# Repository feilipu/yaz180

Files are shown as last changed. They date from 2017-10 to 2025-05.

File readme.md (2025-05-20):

# YAZ180

There needed to be <strong>Yet Another Z180</strong> computer created.<br>
And so, here it is.

<div>
<table style="border: 2px solid #cccccc;">
<tbody>
<tr>
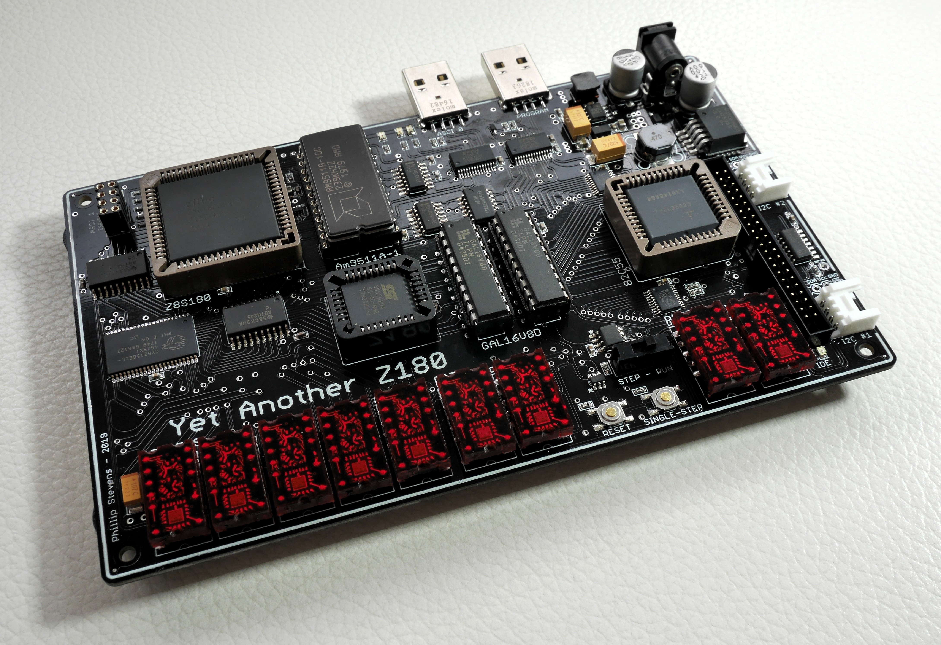
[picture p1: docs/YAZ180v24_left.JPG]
<td style="border: 1px solid #cccccc; padding: 6px;"></td>
</tr>
<tr>
<th style="border: 1px solid #cccccc; padding: 6px;"><centre>YAZ180 Version 2.4 2019 Left<center></th>
</tr>
<tr>
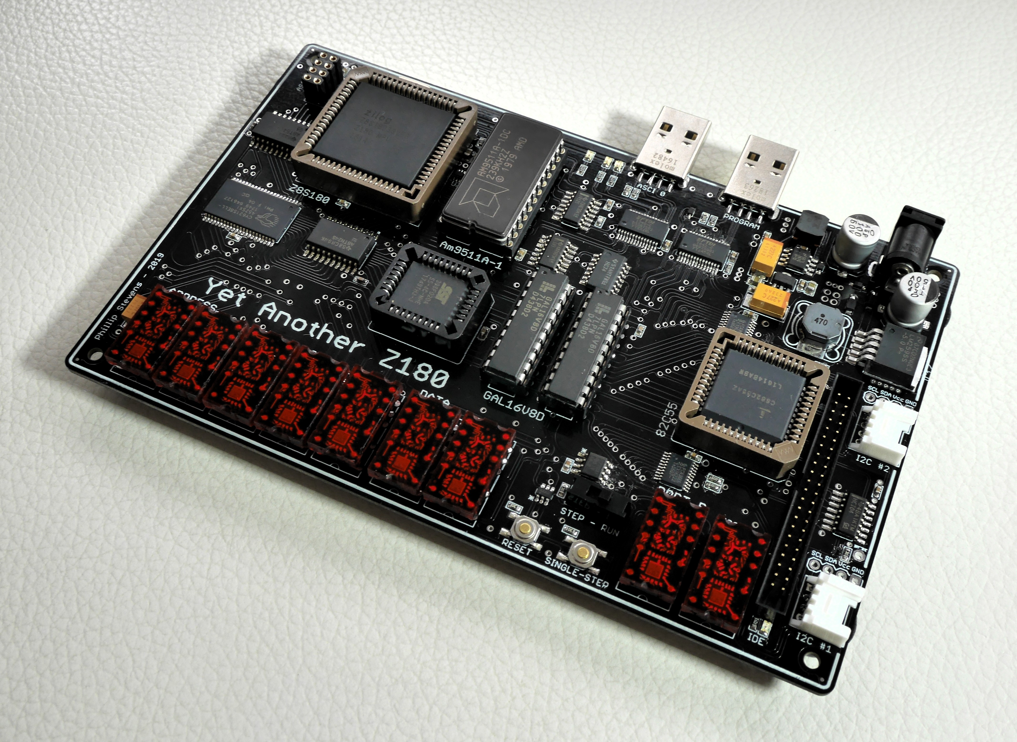
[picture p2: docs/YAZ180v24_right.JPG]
<td style="border: 1px solid #cccccc; padding: 6px;"></td>
</tr>
<tr>
<th style="border: 1px solid #cccccc; padding: 6px;"><centre>YAZ180 Version 2.4 2019 Right<center></th>
</tr>
<tr>
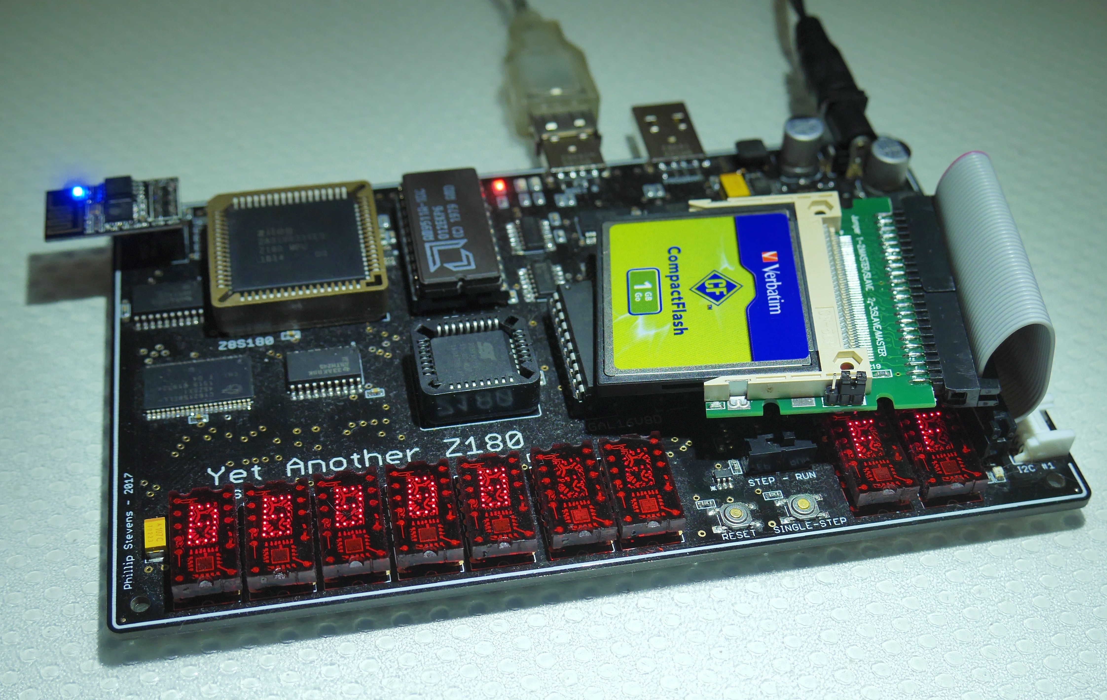
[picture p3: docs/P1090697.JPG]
<td style="border: 1px solid #cccccc; padding: 6px;"></td>
</tr>
<tr>
<th style="border: 1px solid #cccccc; padding: 6px;"><centre>YAZ180 Version 2.1 2017 Live with YABIOS and CP/M<center></th>
</tr>
</tbody>
</table>
</div>

The [YAZ180](https://feilipu.me/?s=yaz180) is a modern single board computer, built on the tradition rich Z180 CPU and the AMD Am9511A-1 APU.

It is my attempt to create a perfect mix of "ancient" and  modern computing technology. Specifically, it is an attempt to marry CPU/APU technology from 40 years ago, with modern I2C, USB, and WiFi capabilities, and make an powerful 8-bit computer that can either be embedded into an application, or operate as a stand-alone computer (with some accessories).

The YAZ180 is supported by the z88dk and it is designed to work with both traditional CP/M v2.2 applications and modern z88dk C compiled programs.

The YAZ180 is fully open source. All documentation and design is available from this repository. I have made the raw PCBs available on [Tindie](https://www.tindie.com/products/feilipu/yaz180-pcb-modern-single-board-z180-computer/), for anyone who wishes to replicate this build.

## Concept

The Z180 CPU is based on the Z80 CPU, but it includes a number of integrated peripherals including a basic Memory Management Unit (MMU), two serial interfaces (ASCI0 & ASCI1), two DMA controllers (DMAC0 & DMAC1), and two Programmable Reload Timers (PRT0 & PRT1).

The fastest readily available Flash memory is 55ns. This is matched by the fastest RAM in 8 x 1MByte packaging at 45ns. Using these two timings the fastest clock that can be therefore be supported is approximately 20MHz. Using this as a guide, and knowing that the Z180 ASCI interfaces are happiest running at a magic frequency, I have therefore selected 18.432MHz as the crystal oscillator frequency for the YAZ180.

The Z180 can operate internally at 2x the crystal oscillator frequency, which means that the YAZ180 is configured to run with PHI at 36.864MHz with 1 wait memory wait state in normal situations. This is slightly outside the Z180 specification (33MHz), but this frequency is reported to work without issues by a number of SBC builds.

The AMD Am9511A (1977) was the first hardware arithmetic Floating Point Unit (FPU) developed. It is essentially a "scientific calculator" on a chip, and is capable of both 16 bit and 32 bit fixed and 32 bit floating point processing, across all the standard and trancendental functions. Even though this device is 40 years old, it is still [comparable in performance](https://feilipu.me/2017/02/22/characterising-am9511a-1-apu/) of mathematical calculations to its Z180 host.

In addition to the internal Z180 interfaces, I have added a 82C55 Programmable Peripheral Interface (PPI) Controller (1974). This device provides 3x 8 bit parallel ports, and enables the YAZ180 to support 16bit IDE hard drives, as well as providing a mechanism to add parallel data interfacing to future expansion boards.

As the IDE interface requires control signals that are active low, several of the PPI Port C lines are passed through inverters. Importantly, those Port C lines that can accept input in PPI Mode 1 or Mode 2 are not inverted, and are therefore available as inputs from off-board applications. The IDE physical interface cable also provides a tidy board extension format, to allow extension or accessory devices to be attached to the YAZ180.

A single step circuitry has been implemented, which is enabled by a switch, and triggered by writing to an I/O port address. This enables the YAZ180 to run normally, until it becomes interesting to enable a breakpoint.

To interface with modern sensors and devices, two separate I2C interface PCA9665 devices have been provided. This enables one I2C device to be running at 800kHz in Fast-mode Plus (or even Plaid at 1MHz) driving a LCD controller for a screen (for example FTDI EVE), and have the other I2C interface connected over longer distances to sensors or keyboard running at 100kHz in Standard mode. The PCA9665 has deep 68 byte hardware buffers, and can operate in buffered or streaming mode, enabling complete I2C sentences to be transmitted or received without CPU interaction. A complete GLX graphics command can be sent with one CPU interrupt transaction, for example.

<div>
<table style="border: 2px solid #cccccc;">
<tbody>
<tr>
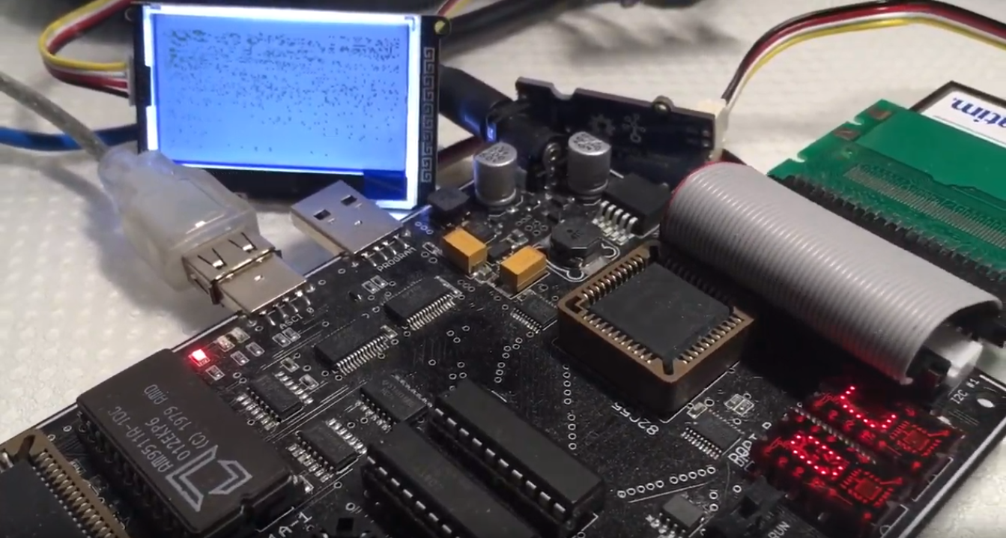
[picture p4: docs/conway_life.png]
<td style="border: 1px solid #cccccc; padding: 6px;"></td>
</tr>
<tr>
<th style="border: 1px solid #cccccc; padding: 6px;"><centre>YAZ180 I2C#2 Conway's Life & I2C#1 Temperature / Humidity Sensing - CLICK FOR VIDEO<center></th>
</tr>
</tbody>
</table>
</div>

To interface with TCP/IP networks, using WiFi, an ESP8266 pin-out for the ESP-01S is provided, connected to ASCI1. This enables the YAZ180 to operate as an Internet server (with attached IDE hard drive), and / or to be controlled using Secure Shell from anywhere.

A USB parallel interface is provided to enable "tool-less" programming of the YAZ180. A perl script is provided to upload Intel HEX code and program it into the system Flash memory. To enable this feature hardware is provided to reconfigure the memory map to allow boot from USB.

## PCB

The YAZ180 PCB is 160mm x 100mm in size, with 4 layers.<br>
This is the maximum size supported by the Eagle "Hobby Licence", which was used to create the PCB.

- Layer Top - all active devices (RED) - 2oz copper
- Layer 2 - GND layer (flood fill) - 0.5oz copper
- Layer 15 - VCC layer (flood fill) - 0.5oz copper
- Layer Bottom - signal traces (BLUE) - 2oz copper

- PCB Dimension - 160mm*100mm
- Material - FR-4 TG130
- Surface Finish - ENIG
- Min Solder Mask Dam - 0.4mm
- PCB Color - Black

<div>
<table style="border: 2px solid #cccccc;">
<tbody>
<tr>
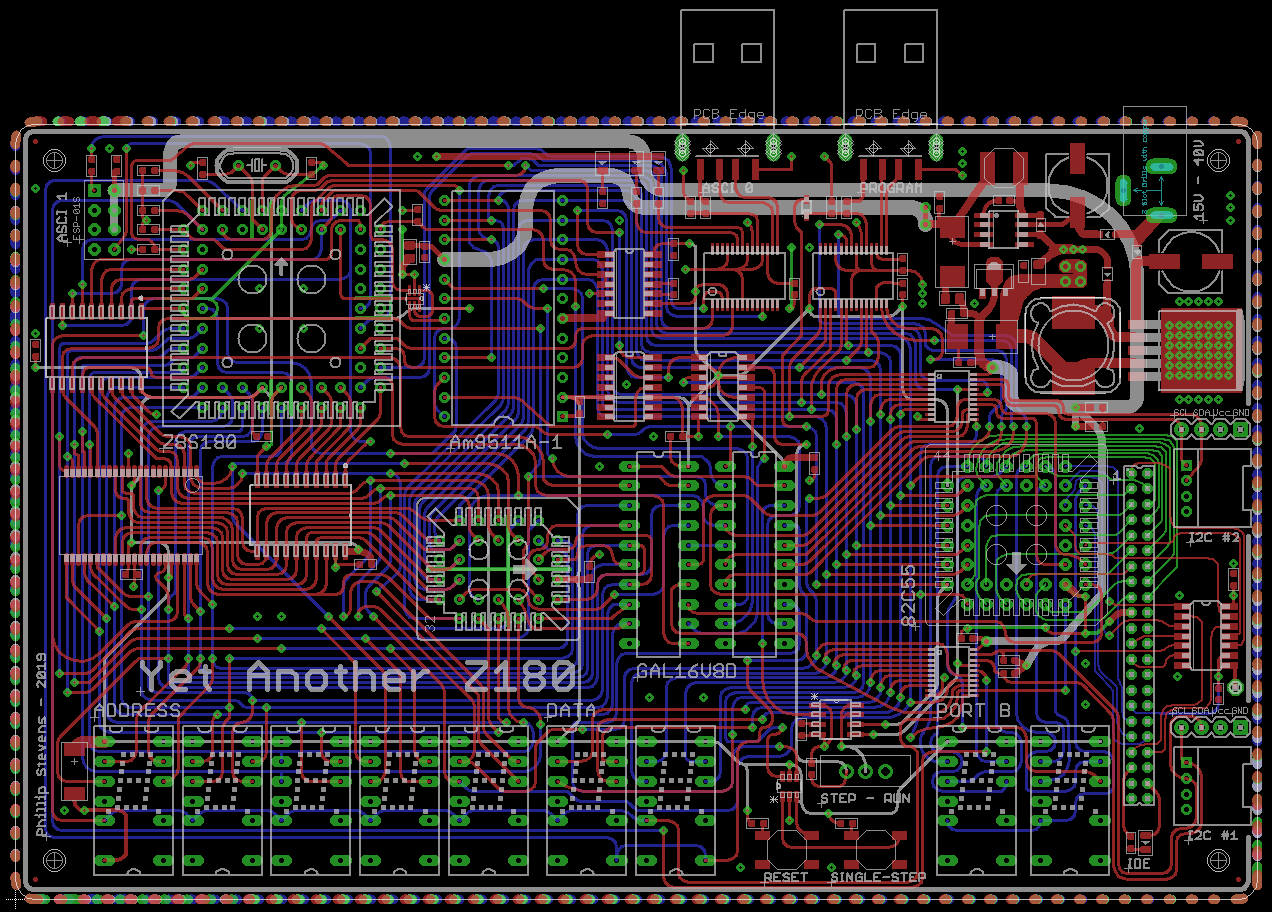
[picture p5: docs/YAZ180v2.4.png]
<td style="border: 1px solid #cccccc; padding: 6px;"></td>
</tr>
<tr>
<th style="border: 1px solid #cccccc; padding: 6px;"><centre>YAZ180 Version 2.4 PCB 2019 Layout<center></th>
</tr>
<tr>
<td style="border: 1px solid #cccccc; padding: 6px;"></td>
</tr>
<tr>
<th style="border: 1px solid #cccccc; padding: 6px;"><centre>YAZ180 Version 2.1 PCB 2017<center></th>
</tr>
</tbody>
</table>
</div>



The YAZ180 requires 15V to 40V, 2A power supply, through a standard 2.1mm barrel jack.<br>
If you are not equipping the Am9511A-1 APU, then the minimum required supply voltage drops to 7V.

The main supply is switchmode rated at 5V 3A, which is used by most of the traditional devices on the board. Note that the <strong>TIL-311</strong> LED display devices consume approximately 105mA each, and operate <strong>HOT TO TOUCH</strong>.

A 3.3V 1A rated linear supply is fed from the 5V internal source. 3.3V is needed to support the I2C and ESP-01S devices.

The internal 12V 500mA rated switchmode supply is generated only to support the APU. Note that the <strong>Am9511A-1</strong> consumes 5V 70mA plus 12V 70mA normally, and operates <strong>BURNING HOT TO TOUCH</strong> (seriously).

The Z180 is supported by an ABT logic signal buffer on the /RD, /WR, /MREQ, and /IORQ lines, together with the four lowest address lines, A3, A2, A1, and A0. These signals are provided to all active elements, and so even though the Z180 includes its own signal buffers, I thought these signals should be additionally buffered.

The Z180 data lines are also buffered by an ABT logic bus transceiver. This is to ensure that these lines are also optimally driven.

## BOM

The <a href="https://github.com/feilipu/yaz180/blob/master/docs/YAZ180_V23_ListByValues.csv" target="_blank">Bill of Material</a> is available from DigiKey by modifying this [Shopping Cart](https://www.digikey.com.au/short/j103pz).

Note that there are two significant items missing from the Shopping Cart.

- The <a href="https://github.com/feilipu/yaz180/blob/master/docs/datasheets/Am9511%20Arithmetic%20Processor.pdf" target="_blank">Am9511A-1</a> is obsolete, and is only available from second tier chip sellers.
- The <a href="https://github.com/feilipu/yaz180/blob/master/docs/datasheets/til311.pdf" target="_blank">TIL-311</a> is not obsolete, but is no longer used in modern development and so is also not generally available.

Both of these products are readily available from second tier sources, but due to their scarcity they are not inexpensive.

Some other smaller pin-outs and connectors are not included:

- 2 of Seeed Studio Grove I2C connectors

## Memory & I/O Address Layout

The physical address mapping is provided by the standard CUPL (described below), and is completely arbitrary. Any other CUPL definitions can be programmed into the GAL16V8D "Memory" device to provide any memory layout desired.

### Physical Memory Address Space

The basic layout is to allow for an initial boot from flash memory into a BANK_0, with additional BANK_1 through BANK14 containing 64kB RAM based application spaces. The upper 4kB of each application space will be masked by COMMON AREA 1 RAM, which provides system utilities.

The additional flash memory is assigned to the upper memory space (BANK13, BANK14, and) BANK15, depending on the size of flash storage equipped. This non-volatile storage can be used for any purpose.

The PROGRAMMING MODE hardware recognises that data is available on the USB parallel port, and reconfigures the physical address mapping to enable boot from USB, and further programming of Flash or RAM.

<div>
<table style="border: 2px solid #cccccc;">
<tbody>
<tr>
<th style="border: 2px solid #cccccc; padding: 6px;">Physical Address Range</th>
<th style="border: 2px solid #cccccc; padding: 6px;">Run Mode</th>
<th style="border: 2px solid #cccccc; padding: 6px;">Programming Mode</th>
</tr>
<tr>
<th style="border: 1px solid #cccccc; padding: 6px;">$00000 -> $0BFFF</th>
<td style="border: 1px solid #cccccc; padding: 6px;">Flash (48kB of 256kB)</td>
<td style="border: 1px solid #cccccc; padding: 6px;">USB pseudo RAM (48kB)</td>
</tr>
<tr>
<th style="border: 1px solid #cccccc; padding: 6px;">$0C000 -> $BFFFF</th>
<td style="border: 1px solid #cccccc; padding: 6px;">SRAM (736kB of 1MB)</td>
<td style="border: 1px solid #cccccc; padding: 6px;">SRAM (736kB of 1MB)</td>
</tr>
<tr>
<th style="border: 1px solid #cccccc; padding: 6px;">$C0000 -> $CFFFF</th>
<td style="border: 1px solid #cccccc; padding: 6px;">SRAM (64kB of 1MB)</td>
<td style="border: 1px solid #cccccc; padding: 6px;">Flash (64kB of 256kB)</td>
</tr>
<tr>
<th style="border: 1px solid #cccccc; padding: 6px;">$D0000 -> $FFFFF</th>
<td style="border: 1px solid #cccccc; padding: 6px;">Flash (192kB of 256kB)</td>
<td style="border: 1px solid #cccccc; padding: 6px;">Flash (192kB of 256kB)</td>
</tr>
</tbody>
</table>
</div>

### Logical Memory Address Space

There is no need to follow this logical address space mapping. This is what I prefer. You can do whatever you want.

The organisation below is an attempt to provide a BANK_0 containing YABIOS (CRT0, boot code, and z88dk library code) together with a RAM system heap. The COMMON AREA 1 space from 0xF000 to 0xFFFF is intended to hold banking code, system call forwarding, interrupt service routines, system buffers, and a system stack.

Additional BANK_1 through BANK14 are intended to hold user code, whether CP/M or z88dk C programs, both are supported through system calls to BANK_0.

Flash found in (BANK13, BANK14, and) BANK15 is intended to be used for snapshots of default or frequently used applications. For example a CP/M snapshot would enable a "diskless" CP/M initialisation, using DMA to load within fractions of a second. Suggested default snapshots could be: CP/M CCP/BDOS, CP/M + BASIC, or Webserver, for example.

<div>
<table style="border: 2px solid #cccccc;">
<tbody>
<tr>
<th style="border: 2px solid #cccccc; padding: 6px;">Logical Address Range</th>
<th style="border: 2px solid #cccccc; padding: 6px;">Run Mode</th>
<th style="border: 2px solid #cccccc; padding: 6px;">Programming Mode</th>
</tr>
<tr>
<th style="border: 1px solid #cccccc; padding: 6px;">$0000 - $BFFF</th>
<td style="border: 1px solid #cccccc; padding: 6px;">Flash (48kB, BANK_0)</td>
<td style="border: 1px solid #cccccc; padding: 6px;">USB (48kB, CA0)</td>
</tr>
<tr>
<th style="border: 1px solid #cccccc; padding: 6px;">$C000 - $EFFF</th>
<td style="border: 1px solid #cccccc; padding: 6px;">SRAM (12kB, BANK_0)</td>
<td style="border: 1px solid #cccccc; padding: 6px;">Flash (8kB, BANK)</td>
</tr>
<tr>
<th style="border: 1px solid #cccccc; padding: 6px;">$F000 - $FFFF</th>
<td style="border: 1px solid #cccccc; padding: 6px;">SRAM (4kB, CA1)</td>
<td style="border: 1px solid #cccccc; padding: 6px;">SRAM (8kB, CA1)</td>
</tr>
</tbody>
</table>
</div>

### I/O Address Space

A computer always needs to be extended and to interact with the real world, and the YAZ180 provides multiple high-speed interfaces. As the Z180 supports 16 bit I/O addressing, the address lines A15-A13 to provide I/O selection options on the YAZ180.

Using a PLD to generate the I/O address mapping also allows flexibility to latch data into the Hex Display, or trigger breakpoints using Z180 #M1 and #Wait signals to allow Single Step execution from any code point.

<div>
<table style="border: 2px solid #cccccc;">
<tbody>
<tr>
<th style="border: 2px solid #cccccc; padding: 6px;">I/O Address Range</th>
<th style="border: 2px solid #cccccc; padding: 6px;">Chip Select (A15,A14,A13)</th>
<th style="border: 2px solid #cccccc; padding: 6px;">Device</th>
</tr>
<tr>
<th style="border: 1px solid #cccccc; padding: 6px;">$0000 - $1FFF</th>
<td style="border: 1px solid #cccccc; padding: 6px;">DO NOT USE</td>
<td style="border: 1px solid #cccccc; padding: 6px;">Internal I/O z180 #INTn $0000-$00FF Registers</td>
</tr>
<tr>
<th style="border: 1px solid #cccccc; padding: 6px;">$2000 - $3FFF</th>
<td style="border: 1px solid #cccccc; padding: 6px;">BREAK</td>
<td style="border: 1px solid #cccccc; padding: 6px;">Break Point - Initiate Single Step Mode</td>
</tr>
<tr>
<th style="border: 1px solid #cccccc; padding: 6px;">$4000 - $5FFF</th>
<td style="border: 1px solid #cccccc; padding: 6px;">#DIO_CS</td>
<td style="border: 1px solid #cccccc; padding: 6px;">82C55 $4000-$4003 Registers</span></td>
</tr>
<tr>
<th style="border: 1px solid #cccccc; padding: 6px;">$6000 - $7FFF</th>
<td style="border: 1px solid #cccccc; padding: 6px;">EXPANSION</td>
<td style="border: 1px solid #cccccc; padding: 6px;">Hold for Expansion</td>
</tr>
<tr>
<th style="border: 1px solid #cccccc; padding: 6px;">$8000 - $9FFF</th>
<td style="border: 1px solid #cccccc; padding: 6px;">#I2C_CS2</td>
<td style="border: 1px solid #cccccc; padding: 6px;">PCA9665 #INT2 $8000-$8003 Registers</td>
</tr>
<tr>
<th style="border: 1px solid #cccccc; padding: 6px;">$A000 - $BFFF</th>
<td style="border: 1px solid #cccccc; padding: 6px;">#I2C_CS1</td>
<td style="border: 1px solid #cccccc; padding: 6px;">PCA9665 #INT1 $A000-$A003 Registers</td>
</tr>
<tr>
<th style="border: 1px solid #cccccc; padding: 6px;">$C000 - $DFFF</th>
<td style="border: 1px solid #cccccc; padding: 6px;">#APU_CS</td>
<td style="border: 1px solid #cccccc; padding: 6px;">Am9511A-1 #INT0 $C000-$C001 Registers</td>
</tr>
<tr>
<th style="border: 1px solid #cccccc; padding: 6px;">$E000 - $FFFF</th>
<td style="border: 1px solid #cccccc; padding: 6px;">EXPANSION</td>
<td style="border: 1px solid #cccccc; padding: 6px;">Hold for Expansion</td>
</tr>
</tbody>
</table>
</div>

## CUPL

The YAZ180 is essentially software defined hardware. The use of Programmable Logic Devices (PLD) to control the board has enabled me to avoid multiple rework to repair issues, and has enabled reconfiguration of memory and I/O logic without raising a soldering iron.

### Memory GAL Configuration

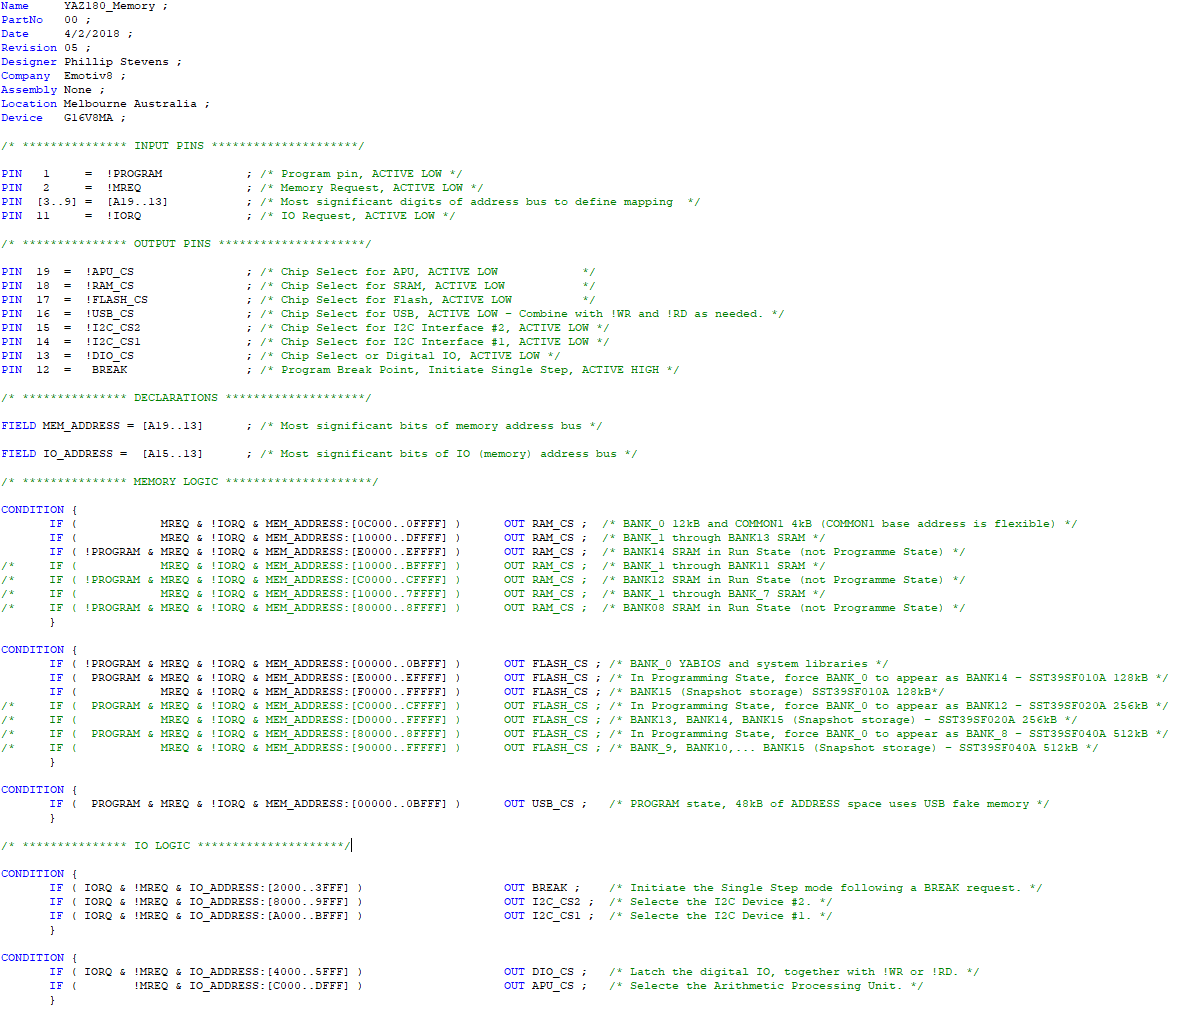
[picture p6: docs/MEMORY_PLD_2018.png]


### Logic (Single Step) GAL Configuration

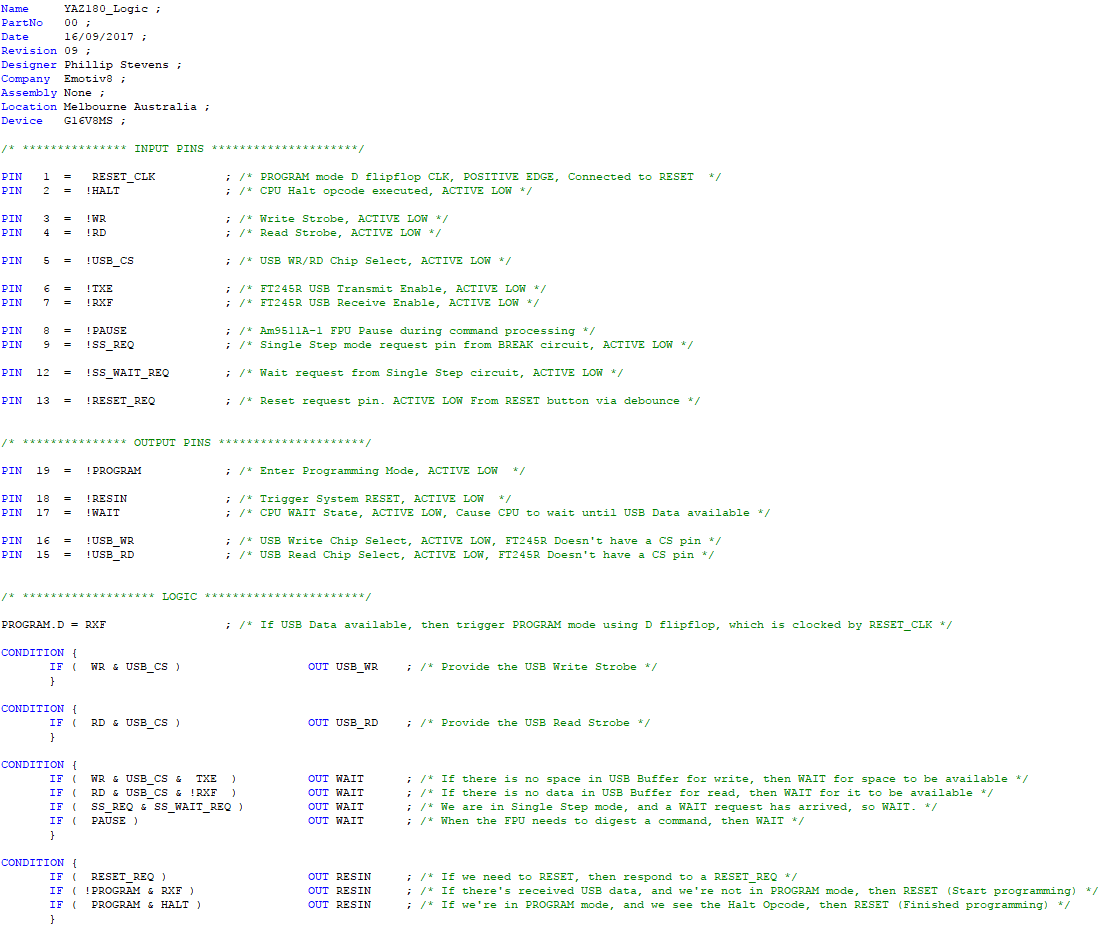
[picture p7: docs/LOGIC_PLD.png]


The YAZ180 CUPL code is available in the [respective directory](https://github.com/feilipu/yaz180/tree/master/cupl).

## YABIOS

Please see here for the status of [YABIOS](https://github.com/feilipu/yaz180/tree/master/yabios).

Currently the YAZ180 is initialised to load [YABIOS v2.2](https://github.com/feilipu/yaz180/tree/master/yabios). Applications can be built for the `+yaz180` target using the [z88dk]((https://github.com/z88dk/z88dk/tree/master/libsrc/_DEVELOPMENT/target/yaz180)) using the ROM (embedded system on metal), APP (YABIOS I/O), and CP/M (BDOS I/O) sub-types.

The YABIOS supports CP/M 2.2 Page 0 compatibility, with an underlying FAT32 File System, and has been extended to allow access to z88dk libraries, and APU and floating point libraries, through the use of `RST+DEFW` short calls, and it includes both `_call_far` and `_jump_far` capability to allow applications to grow beyond 60kB. There is support for 8 MByte CP/M drives as FAT32 files on a Compact Flash or PATA IDE drive up to 128 Gbyte (LBA 28).

## z88dk

[z88dk support](https://github.com/z88dk/z88dk/tree/master/libsrc/_DEVELOPMENT/target/yaz180) has been completed, and improvement work continues reguarly.

## CP/M

CP/M is complete with console and teletype I/O, and the underlying disk sub-system working. Integration of CP/M disks as FAT32 files has also been completed. CP/M can be booted off the Flash snapshot and can load transient programs from FAT32 files (read as CP/M drives).

CP/M drive files can be read and written using a host PC with any operating system, by using the [`cpmtools`](http://www.moria.de/~michael/cpmtools/) utilities, simply by inserting the IDE drive in a USB drive caddy.

The [`yash`](https://github.com/z88dk/z88dk-ext/blob/master/os-related/CPM/yash.c) application can be used to manage CP/M drive files without moving the PATA drive to a host computer. This application supports both read and write to the underlying FATFS file system.

## Construction Notes

There are some [construction notes](https://github.com/feilipu/yaz180/tree/master/construction_notes.md) with errata, to advice on how to build the YAZ180.

## Owners Notes

There are some [owners notes](https://github.com/feilipu/yaz180/tree/master/owners_notes.md) advice on how to operate the YAZ180, and its environment.

## Release Notes

The [release notes](https://github.com/feilipu/yaz180/tree/master/release/readme.md) for each major release cover any issues in software relating to the release.

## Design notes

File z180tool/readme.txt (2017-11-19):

Edit z80tool.pl to point to your FTDI device's device file.

    ls -la /dev/serial/by-id/

You can also just use the /dev/ttyUSB device name, but FTDI chips are popular
and you may eventually plug another one into your computer.  It's better to
use the by-id path which contains the chip's serial number.

The script can program EEPROM both with and without high-speed programming
mode and with or without software write protection, as well as RAM.  It
detects automatically which type of memory is in the Z80 system, but has
only been tested with AT28C256 EEPROMs and SRAM, as I do not have other
EEPROMs.  I did, however, test the code paths by modifying the assembly code
to incorrectly detect which type of memory is present, and so it should work
with other memory chips.

Usage: ./z80tool.pl [function] [filename]

Functions:

  read - reads the Z80 memory and writes it to specified file
  write - writes the specified file to Z80 memory
  protect - enables write protection on AT28C256 EEPROMs
  unprotect - disables write protection on AT28C256 EEPROMs
  writeprotect - writes the specified file to Z80 memory, then
                 enables write protection on the AT28C256 EEPROMS.
  check - Just checks what type of memory is in the Z80, and its
          write protection status.  May wreck the EEPROM's contents
          in the process, as it must write to it to figure it out.

The z80tool.pl can run alone, the other files in this archive are there just
in case you need to modify it.  If it sees the resulting *.rom files from
compiling the two assembly source files, it will load them, otherwise it uses
versions stored within the script itself, made with the rom2perl.pl script.

http://www.ecstaticlyrics.com/electronics/Z80/EEPROM_programmer/

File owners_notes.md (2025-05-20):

# Owners Notes

These are a few notes for owners of a YAZ180, which should help to make using the board for fun and profit easier.

Please also read the [implementation notes](https://github.com/feilipu/yaz180/blob/master/implementation_notes.md), and the [construction notes](https://github.com/feilipu/yaz180/blob/master/construction_notes.md). The information in both these documents won't be repeated here.

Note that the YAZ180 is a very capable and multifaceted tool. I've not stretched any of its capabilities, and therefore you might find stuff (bugs) that I've never seen.

I've tested the `_call_far` and `_jp_far` functions, but I haven't written large programs requiring multi-bank support. 

I've written I2C drivers now 4 times (and deleted the last two attempts), and I know the drivers in the z88dk have been updated and are working. Trying to use the I2C hardware buffers, in an interrupt driven memory banked environment is hard IMHO, and I've still not completely achieved the result I want.

You're probably the first one to try what you're trying to do. But, don't stress.

Read the source code. At least the code in this repository. The important stuff to know is all maintained here. Libraries in z88dk and in my z88dk-libraries are relevant, but they deliver standardised outcomes for libc and for file management, and the won't tell you much about how this environment is configured.

## Power Bricks

The first thing needed is a power supply capable of supplying the current needs of all of the blinking lights. And, being able to supply current at above 12V to support the Am9511A APU.

Because a switch mode power supply is being used, with a substantial input voltage tolerance, anything up to (say) 24V 2A would work. On my desk, I have a 15V 2A supply, which performs perfectly.

40V is the ultimate maximum input voltage. Magic smoke territory. Please don't use this.

If you're not planning to use the APU, then it is probably best to unplug it and leave it aside. It will just sit generating heat, and that's pretty pointless. If you aren't using the APU, then the power supply is adequate supplying 7V to 9V 2A.

Use a 12V to 15V supply, simply because that covers all of the bases. 2A is more than enough.
Providing a lower source voltage is less wasteful and the PCB power supplies run cooler.

## USB Cables and Connections

I selected male A type sockets for the USB because the connector is quite robust, and doesn't mind a few insertion cycles.

The FTDI chips are powered by the USB side, but their IO on the digital side is powered by the board. This means that during a power cycle it should be possible to leave the USB cable plugged, and not re-enumerate the USB interface. But, this doesn't always work. Often the host computer will move the USB interface to new device on power cycle, which means that the serial terminal will loose connection with the YAZ180 if it is not re-plugged.

The ASCI-0 with the FTDI-232 Serial interface is set up for 115,200 baud 8n2.

## RESET and SINGLE-STEP

After putting a lot of circuitry on the PCB to support SINGLE-STEP, in reality it is not very useful now that tools such as ZSID or DDT work effectively. Still, it is nice to have. Leave the switch set to RUN, and forget it.

The RESET button is your friend. Don't be afraid to use it, often. As there is very little state maintained, nothing is lost by doing a RESET.

You will need to RESET

* on power on, to flush and reset the serial interfaces.
* something crashed in CP/M.
* sometimes, just because.

## Random stuff happening

There are two causes of random stuff happening. The first is the Flash chip has lost seating. The second is the IDE or CF drive needs to be power cycled.

Sometimes I find random things happening, and it is almost always cured by pressing down on the Flash chip, or sometimes simply extracting it and reseating.

When using CP/M sometimes the IDE or CF drive will get itself into an unusual state, that can't be recovered by a hard reset on the PATA interface (generated when the YAZ180 is RESET). If that happens, then a power cycle is the only option.

## Am9511A-1 APU

Obviously, the Am9511A APU is a very old device, and it has been quite difficult to get it to work with the more modern Z8S180 CPU. That said, once it has been initialised correctly, it is very reliable.

Sometimes the devices doesn't initialise itself properly, and then the only thing remaining to do is to power cycle the board. Resetting often doesn't work. But, try if you like.

The Am9511A-1 runs very very hot. I cannot leave my finger on the surface of the device after it has been operating for 10 minutes or so. Yet, this is normal. The current consumption is within the normal range. And the devices I used have been operating now for two years now without one failing.

You will note that in order to write to the Am9511A-1 the CPU has to slow down 4x from 36MHz to 9.2MHz, although during normal operation of the Am9511A-1 the 74LS93 divider produces a 2.3MHz signal from the normal speed CPU PHI signal. Unfortunately, the Am9511A-1 requires 30ns of data hold following release of the `/WR` signal, and this can only be generated by combining the `/WR` and `ECLK` signals (shortening the apparent `/WR` for the APU), and slowing down the CPU clock. Running the CPU at 18.432MHz produces 27ns of hold time, and unfortunately this is simply not sufficient so the the next step is to slow down to 9.2MHz during write to the APU.

Reading from the APU is not affected by this issue, so it is done at full CPU speed.

Note that in some situations the Am9511A-1 also requires that 2x Memory Wait states (and 3x I/O Wait states) be provided, although it is not being accessed by memory operations. I'm still not clear why this is the case.

## ESP-01S Interface

The ASCI-1 is connected to a port into which a ESP-01S can be inserted. Whilst any program can be run on the ESP-01S, the most useful from my point of view is the [JeeLabs esp-link](https://github.com/jeelabs/esp-link/releases/tag/V3.0.14).

The ASCI-1 is set up with 9600 baud 8n2, with NO remote echo as it typical for teletype interfaces. It is done this way to support Kermit on HP-48S/G calculators. Just an interest I have.

Using the ESP-01S, it is possible to reach your YAZ180 via the Internet.

# YABIOS

The YABIOS has been set up as a working tool. It isn't consise in its language or its commands. So, for example, there are three steps to getting a program running.

* Load the program using either `loadh 3` via the currently active serial port, or load a previously saved program (if you've got an IDE or CF drive attached) using `loadb path 3` (where we have decided to use Bank 3 for our program).
* Save the program to your drive (if you want to) using `saveb 3 path`.
* Establish the program bank as active, and fill the page 0 information with `mkb 3`.
* Initiate the program by using the `initb 3`, whereby execution begins in Bank 3 at `0x0100`.

Before any IDE or CF drive information can be obtained, the drive needs either to be mounted with `mount 1`, or its directory read with `ls` which will auto mount the drive.

The workflow that I use is to build new programs, which will be run as a native YABIOS `app`, on the host PC and then download or `cat` the HEX file to the YAZ180 using the YABIOS `loadh` function. This is extremely fast, and makes use of more convenient tools on the host PC.

It is also possible to store binary files, with any origin (default at `0x0100`) directly into a file in the IDE or CF drive on the PC, and then use `loadb` to load them into the correct place on YAZ180, and `initb` to start execution at the right address. I'd call this advanced usage. I can't remember actually doing this.

Often used binary files can be stored in flash. For example in the Release 2.1, two versions of the Mandelbrot program are stored in Pages 13 (using Z180 `mul` routines), and Page 14 (using Am9511A-1 APU). The two stored binaries can be accessed with the command sequence `cpb 13 3` or `cpb 14 3`, and `mkb 3`, and `initb 3`, for example, where Bank 3 is the target bank.

## CP/M Functions

There are two CP/M functions. The `mkcpmd` function builds a properly extended CP/M drive file on the IDE or CF drive attached to YAZ180. This is necessary because the CPM tools do not build the fully extended 8388608 Byte files required. But, if you have a file you can use as a template already then this comand is pretty useless (obsolete). Just do a file copy, and then within CP/M delete the contents of the drive.

The `mkcpmb` command will be used all the time. This combines both the `mkb` and `loadb` actions, and will load the contents of the flash in Bank 15 into the Bank you choose, and will prepare the bank with the LBA of each of up to 4 drive files. Then a `initb` command is required to initiate CP/M.

To exit CP/M an additional CCP function called `EXIT` has been added. This will return to YABIOS and allow CP/M to be restarted with different drive files.

More to CP/M later

## Bank Functions

All work as intended, but `lsb` or list bank has not been implemented. I found that since I've not implemented a RTOS yet, there was little point to this function at this stage.

The `loadh` function should respect Type 2 ESA configuration. This means that an ESA command will change banks to the required Bank, and will begin loading HEX from that location. The Type 2 Extended Segment Address (ESA), is equivalent to BBR data, and translates 1:1. Therefore Bank changes can be done by inputting the correct ESA data as 0xn000.

## File System Functions

The `mkfs` function has been excluded from the build, as it took too much space, and it wasn't sensible to format the sole drive on the YAZ180. Do this on a host PC.

## Disk Functions

The `dd` function reads decimal LBAs, so where a file is used as input to the `mkcpmb` command and the LBA is found and output. This LBA can then be used to dump the contents of the CP/M drive file, for interest.

## Time functions

The `clock` reads real time and keeps pretty good time at that at about 20ppm. The only thing that will upset the clock is using the APU which slows down the clock to 1/4 speed for milli-seconds. Probably you won't notice this.

The default `tz` is Melbourne Australia. There isn't an easy non-volatile way to make the default change permanently, unless a new firmware version is burnt.

# z88dk

The z88dk is my development system of choice. There is much information about how to configure it around, and there's an [entry on my blog](https://feilipu.me/2016/09/16/z80-c-code-development-with-eclipse-and-z88dk/) on using it as a last resort. Note, I've never gotten to getting the Eclipse environment working. Never really needed it.

## YAZ180

For the YAZ180 the command line of choice is
```bash
zcc +yaz180 -subtype=app -SO3 -m --math32 --max-allocs-per-node400000 test.c -o test -create-app
```
The YAZ180 has three main options,being `app`, `rom`, and `cpm` subtypes.

The `rom` subtype is only useful where you are compiling a YABIOS, or you wish to run your YAZ180 without the yabios from the metal. In this situation all the drivers available for the YAZ180 are maintained within the z88dk, and everything should just work.

The `app` subtype is the go to for native applications. Everything you're running directly on YABIOS should be compiled with this subtype.

Within the CP/M environment, then the `cpm` subtype should be selected. Alternatively the z88dk `cpm` target can be selected, although this doesn't allow access to YAZ180 specific libraries and header files, nor does it use the Z180 specific functions, such as `mlt nn` to accelerate array access and integer arithmetic.

Details of each build type for the YAZ180 can be found within the configuration files of the z88dk. For the beginning user, the defaults are quite acceptable.

Breaking down the above command line

* `+yaz180` - is the platform type
* `-subtype=app` - is the subtype for the platform, here build for application (with YABIOS)
* `-v` - verbose `-nv` is silent
* `-m` - build a map file, needed for `-create-app`
* `-SO3` - stongly optimise using the aggressive z88dk peephole optimiser
* `--list` - generate list files
* `--max-allocs-per-node` - depth of sdcc code optimisation, reduce for faster compilation
* `-create-app` - generate finalised HEX code, also a BIN file which can be used directly.

## CP/M

To use z88dk to compile for CP/M for the Z180 processor, then the following commands can be used

```bash
zcc +yaz180 -subtype=cpm -SO3 -m --list --math32 -test.c -o test
appmake +glue --ihex --clean -b test -c test
```
Breaking this down

* `+yaz180` - is the platform type
* `-subtype=cpm` - is the subtype for the platform, here build for CP/M
* `appmake` - builds the final HEX output
* `+glue` - binds binary objects into a specific output
* `--clean` - removes byproducts of the build process

Using the `cpm` subtype from the YAZ180 target supports the Z180 specific instructions more completely, and avoid the potential inclusion of Z80 undocumented instructions.

Note that the alternative method of obtaining CP/M builds by using the CP/M target and `default` subtype doesn't provide access to YAZ180 specific hardware or capabilities, but that is not really a problem, as CP/M provides access to all the serial hardware via BDOS calls anyway.

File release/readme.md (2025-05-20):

## Release Notes

### V1.2

The current version of yabios has been used now for several months, and Release 1.2 provides a clear point from which code can be distributed.

At this point all of the included hardware drivers (ASCIO, 82C55 and APU), and software functions are working as expected, and yabios now provides a platform for further development.

Further development includes the I2C drivers, which are excluded from the yabios common RAM.

In the 256kB of Flash there are 4 pages of 64kB, split according to the memory map into Pages 0, 13, 14, and 15.

* Page 0 is the boot page, containing the yabios boot code and shell.
* Page 13 is a mandelbrot test using the Z180 `mul` instruction, showing the maximum math performance.
* Page 14 is a mantelbrot test using the Am9511A-1 APU in floating point mode.
* Page 15 is the CP/M CCP/BDOS/BIOS from which the CP/M system loads (and reloads) during normal operation.

__Note__ that the Am9511A-1 APU may have difficulty initialising itself. This will be obvious, because the expected output will not be provided. In this case the yaz180 may need to be power cycled, or at a minimum reset.

If no IDE disk is available for testing, most of the system can be tested by running either the Page 13 or Page 14 mandelbrot programs, or simply doing some memory dumps.

<div>
<table style="border: 2px solid #cccccc;">
<tbody>
<tr>
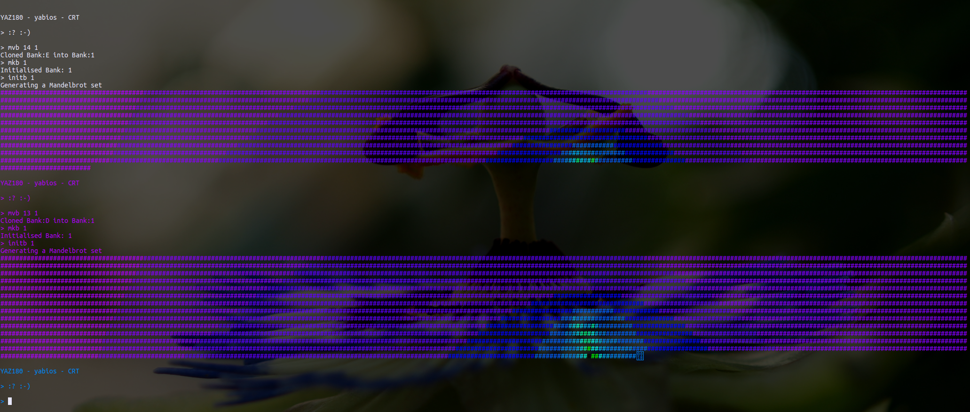
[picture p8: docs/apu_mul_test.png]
<td style="border: 1px solid #cccccc; padding: 6px;"></td>
</tr>
<tr>
<th style="border: 1px solid #cccccc; padding: 6px;"><centre>Testing using Page 13 and Page 14<center></th>
</tr>
<tr>
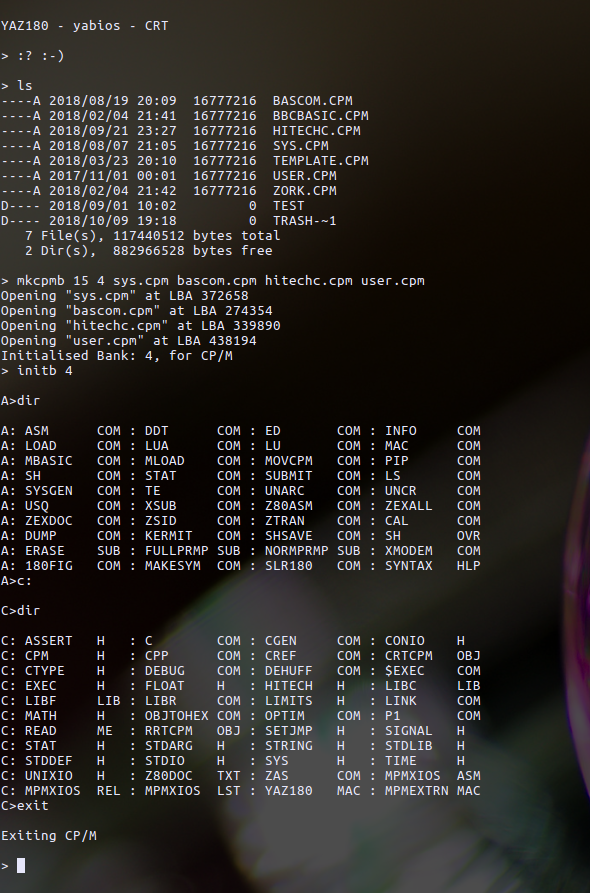
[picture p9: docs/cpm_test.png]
<td style="border: 1px solid #cccccc; padding: 6px;"></td>
</tr>
<tr>
<th style="border: 1px solid #cccccc; padding: 6px;"><centre>Testing Page 15 CP/M<center></th>
</tr>
</tbody>
</table>
</div>

### V1.3

There is little change to the yaz180 code in this release, but the underlying `zsdcc` compiler has been developed significantly. This release has been compiled with `r11311` of sdcc, using the patch file included in z88dk.

### V1.4

There is little change to the yaz180 code in this release, except a few tweaks to the far functions and ASCI drivers. This release has been compiled with `r11369` of sdcc, using the patch file included in z88dk. This release changes the location of most functions, so the [linkage file](https://github.com/z88dk/z88dk/blob/master/libsrc/_DEVELOPMENT/target/yaz180/crt_yabios_def.inc) in z88dk has been updated.

### V1.5

There is little change to the yaz180 code in this release, except a few tweaks to the IDE drivers and time reporting. This release has been compiled with `r11502` of sdcc, using the patch file included in z88dk. This release changes the location of some functions, so the [linkage file](https://github.com/z88dk/z88dk/blob/master/libsrc/_DEVELOPMENT/target/yaz180/crt_yabios_def.inc) in z88dk has been updated.

### V1.6

There is little change to the yaz180 code in this release, except a few tweaks to the CLI. This release has been compiled with `r11556` of sdcc, using the patch file included in z88dk. All the underlying libraries have been updated too.

### V2.0

__NOTE WELL__ This release __v2.0 changes the number of directory entries in CP/M drives to 2048 directory entries__. If you don't convert __your old drives__ to this new configuration, __they will be destroyed__.

There is no change to the yaz180 code in this release, except to change the directory structure. This release has been compiled with `r12017` of sdcc, using the patch file included in z88dk.

### V2.1

This release adds trap functionality to notify of illegal opcodes, most commonly present in programs developed for use within CP/M. This has meant that the function addresses have changed, and these are noted both here and in the [z88dk definitions file](https://github.com/z88dk/z88dk/blob/master/libsrc/_DEVELOPMENT/target/yaz180/crt_yabios_def.inc).

The command to clone or copy a bank has changed to `cpb` which is more aligned to its actual function.

Hardware flow control has been enabled on ASCI0 `CRT` using `/RTS`.

This release has been compiled with `r12419` of zsdcc, using the patch file included in z88dk.

### V2.2

This release provides some minor tidy up of the source code, including simplification of token parsing.
The unimplemented function `lsb` has been removed from the CLI, and some defaults have been reset.
The `frag` function to check whether FAT32 files are contiguous has been added. This only needs to be run once to before use with CP/M.
The ChaN FatFs library is updated to R0.15.

The serial interfaces have been adjusted to 115200 baud 8n2.

This release has been compiled with v4.4.0 `r14648` of zsdcc, using the patch file included in z88dk.

### V2.3

This release provides some minor tidy up of the source code, including interrupt safe disk read and write routines for SDCC. The CP/M functions #37 and #40 have been returned to the BDOS, as these were inadvertently ommited even though they are part of CP/M 2.2.

The ChaN FatFs library is updated to R0.15a patch 1.

This release has been compiled with v4.5.0 `r15248` of zsdcc, using the patch file included in z88dk and the z88dk on May 20, 2025.

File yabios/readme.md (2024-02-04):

# YABIOS

There needed to be Yet Another Z180 computer created, and for that computer: <strong>Yet Another BIOS</strong>.

The YAZ180 is a modern single board computer, built on the tradition rich Z180 CPU and the AMD Am9511A-1 APU.

It is my attempt to create a perfect mix of "ancient" and  modern computing technology. Specifically, it is an attempt to marry CPU/APU technology from 40 years ago, with modern I2C, USB, and WiFi capabilities, and make an powerful 8-bit computer that can either be embedded into an application, or operate as a stand-alone computer (with some accessories).

The YAZ180 is supported by the Z88dk and it is designed to work with both traditional CP/M v2.2 applications and modern Z88dk C compiled applications.

The YABIOS supports CP/M 2.2 Page 0 compatibility, with an underlying Fat32 File System, and allows access to Z88dk libraries, with APU, FatFs, and time libraries, through the use of `RST+DEFB` or `RST+DEFW` short calls, and will include a `_call_far` capability to allow applications to grow beyond 60kB.

## Design Concept

YABIOS is designed to look substantially like CP/M BIOS to CP/M applications, but incorporating advances in design pioneered by the Cambridge Z88 OZ operating sytem to enable access to a wider range of system resources for applications prepared by the Z88dk.

There are three ways to interact with YABIOS,

1. the Command Line Interface, on either of the ASCI serial interfaces,
2. the Z80 `RST` short calls established to support access to YABIOS system functions, and
3. the CP/M BIOS calls integrating YABIOS with the CP/M CCP/BDOS.

The location of the `RST` short calls is defined within the YABIOS Page 0.
<div>
<table style="border: 2px solid #cccccc;">
<tbody>
<tr>
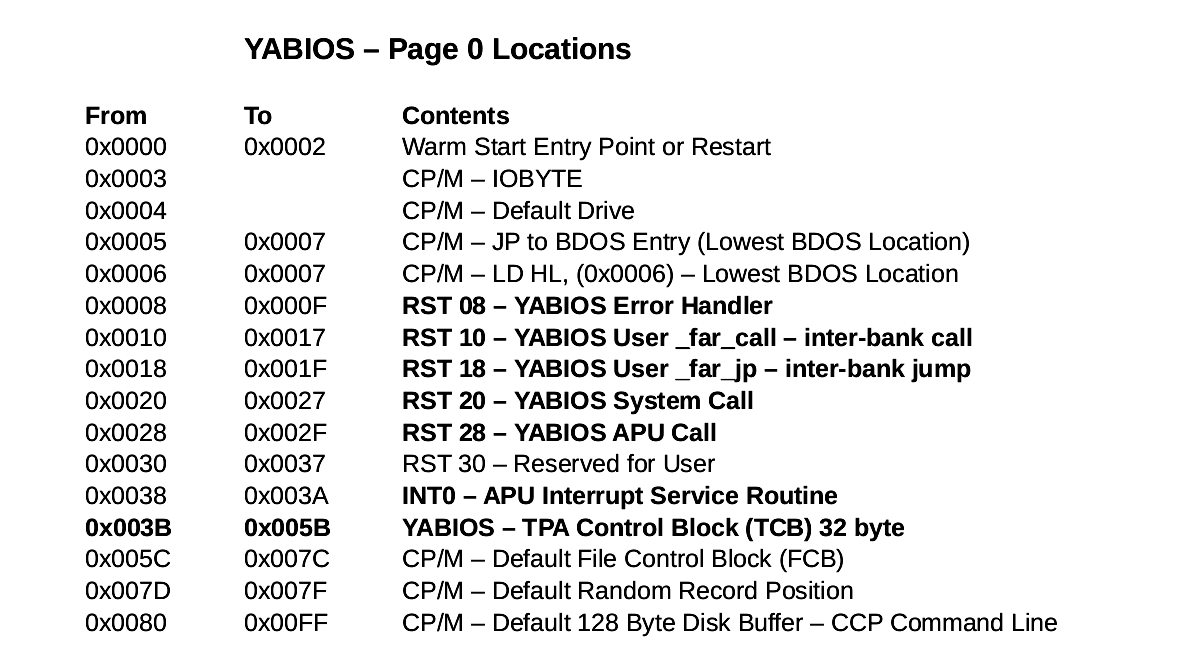
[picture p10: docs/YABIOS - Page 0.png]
<td style="border: 1px solid #cccccc; padding: 6px;"></td>
</tr>
<tr>
<th style="border: 1px solid #cccccc; padding: 6px;"><centre>YABIOS Page 0<center></th>
</tr>
</tbody>
</table>
</div>

As the YAZ180 has multiple BANK locations in which to run an application, one design goal is to minimise (remove) dependency on the application being loaded into a particular BANK. This will require the development of BANK relative addressing for `_call_far` and other system functionalities, if an application is to be larger than 60kB, or is to be independent of its initial BANK location.

## Development Path

As the development of YABIOS is going to take some effort and time, the work will be divided into phases, each providing measurable and useable outcomes. Each phase should provide services to the following phases, upon which that development phase will build.

Each one of these items will need to be implemented.

### Phase 1 - Z88dk application support

- [x] [`_memcpy_far`](https://github.com/feilipu/yaz180/tree/master/yabios#_memcpy_far)function
- [x] [`_load_hex`](https://github.com/feilipu/yaz180/tree/master/yabios#_load_hex)
- [x] [`_load_bin`](https://github.com/feilipu/yaz180/tree/master/yabios#_load_bin) functions
- [x] [Command Line Interface](https://github.com/feilipu/yaz180/tree/master/yabios#command-line-interface)
- [x] [`RST+DEFW` System Call](https://github.com/feilipu/yaz180/tree/master/yabios#rst20defw-system-call)
- [x] [`RST+DEFB` APU Call](https://github.com/feilipu/yaz180/tree/master/yabios#rst28defb-apu-call) convert existing code to pass values, rather than pointers
- [x] [`RST+DEFB` Error Handler](https://github.com/feilipu/yaz180/tree/master/yabios#rst8defb-error-handler)
- [x] Integrate existing FatFs code for IDE interface on 82C55.
- [x] I/O redirection for CP/M IOBYTE support

Note: `_memset_far` was deleted as there was insufficient space in CA1 memory.

### Phase 2 - CP/M application support

- [x] `conin`, `conout`, `const` calls
- [x] link FatFS with CP/M Disk buffers
- [x] `setdma`, `seldsk`, `settrk`, `setsec` calls
- [x] `read`, `write`, `sectran` calls
- [x] integrate CP/M IOBYTE support
- [x] integrate CLI support

### Phase 3 - Flash Snapshot support

- [x] add flash read support into `_ memcpy_far`.
- [ ] add flash write support into `_ memcpy_far` (very hard, DMAC won't do it).
- [x] support CP/M to warm boot from flash
- [x] integrate CLI support

### Phase 4 - RTOS multi-tasking

- [x] port FreeRTOS within an application (single BANK) see [z88dk-libs/freertos](https://github.com/feilipu/z88dk-libraries/tree/master/freertos).
- [ ] integrate FreeRTOS with YABIOS (Page 0 `TCB*`)

### Phase 5 - Multi-bank application support

- [x] [`RST+DEFW+DEFB` `_call_far`](https://github.com/feilipu/yaz180/tree/master/yabios#rst10defwdefb-_call_far)
- [x] [`RST` `_jp_far`](https://github.com/feilipu/yaz180/tree/master/yabios#rst18-_jp_far)
- [x] finalise and test

## Memory Map

The organisation below is an attempt to provide a logical memory map for YAZ180, which allows simple bank management. Yet, is flexible enough to support multi-tasking from a RTOS in the future.

`BANK_0` contains YABIOS (CRT0, boot code, and Z88dk library code) together with a RAM system heap. The COMMON AREA 1 space from 0xF000 to 0xFFFF is intended to hold banking code, system call forwarding, interrupt service routines, system buffers, and a system stack.

Additional `BANK_1` through `BANK14` are intended to hold user code, whether CP/M or Z88dk C programs, both are supported through system calls to `BANK_0`.

Flash found in (`BANK13`, `BANK14`, and) `BANK15` is intended to be used for snapshots of default or frequently used applications. For example storing a CP/M snapshot enables a "diskless" CP/M initialisation, using DMA, to load within fractions of a second. Suggested default snapshots could be: CP/M CCP/BDOS, CP/M + BASIC, or Webserver, for example.

<div>
<table style="border: 2px solid #cccccc;">
<tbody>
<tr>
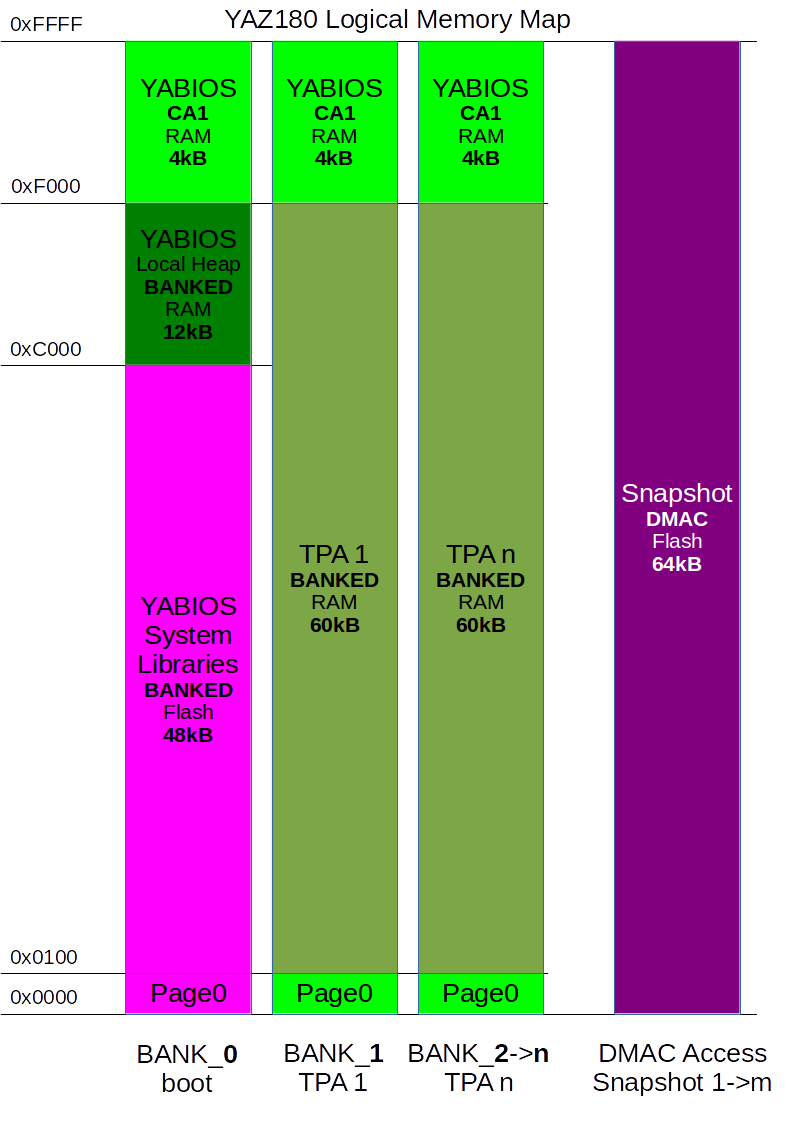
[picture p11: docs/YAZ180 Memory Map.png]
<td style="border: 1px solid #cccccc; padding: 6px;"></td>
</tr>
<tr>
<th style="border: 1px solid #cccccc; padding: 6px;"><centre>YABIOS Memory Map<center></th>
</tr>
</tbody>
</table>
</div>

Further description of the memory map when programming via the USB parallel port, the physical arrangement of RAM and Flash memory, and the I/O arrangement are provided below.

### Programming Memory Map

YABIOS being developed for the YAZ180 implements the following memory map for run (normal) mode and programming mode. Programming mode is used to provide access to YAZ180 Flash memory for programming, without relying on the existance of YABIOS, or external tools.

A USB parallel interface is provided to enable "tool-less" programming of the YAZ180. A perl script is provided to upload Intel HEX code and program it into the system Flash memory. To enable this feature hardware is provided to reconfigure the memory map to allow boot from USB.

Preparation of the programming mode perl tool is work in progress.

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

### Physical Memory Address Space

The basic layout is to allow for an initial boot from flash memory into a system `BANK_0`, with additional `BANK_1` through `BANK12` containing 64kB RAM based application spaces. The upper 4kB of each application space will be masked by `COMMON AREA 1` RAM, which provides system utilities.

The additional flash memory is assigned to the upper memory space (`BANK13`, `BANK14`, and) `BANK15`. This non-volatile storage can be used for any purpose.

The PROGRAMMING MODE hardware recognises that data is available on the USB parallel port, and reconfigures the physical address mapping to enable boot from USB, and further programming of Flash or RAM.

<div>
<table style="border: 2px solid #cccccc;">
<tbody>
<tr>
<th style="border: 2px solid #cccccc; padding: 6px;">Physical Address Range</th>
<th style="border: 2px solid #cccccc; padding: 6px;">Run Mode</th>
<th style="border: 2px solid #cccccc; padding: 6px;">Programming Mode</th>
</tr>
<tr>
<th style="border: 1px solid #cccccc; padding: 6px;">$00000 - $0BFFF</th>
<td style="border: 1px solid #cccccc; padding: 6px;">Flash (48kB of 128kB)</td>
<td style="border: 1px solid #cccccc; padding: 6px;">USB pseudo RAM (48kB)</td>
</tr>
<tr>
<th style="border: 1px solid #cccccc; padding: 6px;">$0C000 - $DFFFF</th>
<td style="border: 1px solid #cccccc; padding: 6px;">SRAM (848kB of 1MB)</td>
<td style="border: 1px solid #cccccc; padding: 6px;">SRAM (848kB of 1MB)</td>
</tr>
<tr>
<th style="border: 1px solid #cccccc; padding: 6px;">$E0000 - $EFFFF</th>
<td style="border: 1px solid #cccccc; padding: 6px;">SRAM (64kB of 1MB)</td>
<td style="border: 1px solid #cccccc; padding: 6px;">Flash (64kB of 128kB)</td>
</tr>
<tr>
<th style="border: 1px solid #cccccc; padding: 6px;">$F0000 - $FFFFF</th>
<td style="border: 1px solid #cccccc; padding: 6px;">Flash (64kB of 128kB)</td>
<td style="border: 1px solid #cccccc; padding: 6px;">Flash (64kB of 128kB)</td>
</tr>
</tbody>
</table>
</div>

### I/O Address Space

A computer always needs to be extended and to interact with the real world, and the YAZ180 provides multiple high-speed interfaces. As the Z180 supports 16 bit I/O addressing, the address lines A15-A13 to provide I/O selection options on the YAZ180.

<div>
<table style="border: 2px solid #cccccc;">
<tbody>
<tr>
<th style="border: 2px solid #cccccc; padding: 6px;">I/O Address Range</th>
<th style="border: 2px solid #cccccc; padding: 6px;">Chip Select (A15,A14,A13)</th>
<th style="border: 2px solid #cccccc; padding: 6px;">Device</th>
</tr>
<tr>
<th style="border: 1px solid #cccccc; padding: 6px;">$0000 - $1FFF</th>
<td style="border: 1px solid #cccccc; padding: 6px;">-</td>
<td style="border: 1px solid #cccccc; padding: 6px;">Internal I/O z180 #INTn $0000-$00FF Registers</td>
</tr>
<tr>
<th style="border: 1px solid #cccccc; padding: 6px;">$2000 - $3FFF</th>
<td style="border: 1px solid #cccccc; padding: 6px;">BREAK</td>
<td style="border: 1px solid #cccccc; padding: 6px;">Break Point - Initiate Single Step Mode</td>
</tr>
<tr>
<th style="border: 1px solid #cccccc; padding: 6px;">$4000 - $5FFF</th>
<td style="border: 1px solid #cccccc; padding: 6px;">#DIO_CS</td>
<td style="border: 1px solid #cccccc; padding: 6px;">82C55 $4000-$4003 Registers</span></td>
</tr>
<tr>
<th style="border: 1px solid #cccccc; padding: 6px;">$6000 - $7FFF</th>
<td style="border: 1px solid #cccccc; padding: 6px;">-</td>
<td style="border: 1px solid #cccccc; padding: 6px;">Hold for Expansion</td>
</tr>
<tr>
<th style="border: 1px solid #cccccc; padding: 6px;">$8000 - $9FFF</th>
<td style="border: 1px solid #cccccc; padding: 6px;">#I2C_CS2</td>
<td style="border: 1px solid #cccccc; padding: 6px;">PCA9665 #INT2 $8000-$8003 Registers</td>
</tr>
<tr>
<th style="border: 1px solid #cccccc; padding: 6px;">$A000 - $BFFF</th>
<td style="border: 1px solid #cccccc; padding: 6px;">#I2C_CS1</td>
<td style="border: 1px solid #cccccc; padding: 6px;">PCA9665 #INT1 $A000-$A003 Registers</td>
</tr>
<tr>
<th style="border: 1px solid #cccccc; padding: 6px;">$C000 - $DFFF</th>
<td style="border: 1px solid #cccccc; padding: 6px;">#APU_CS</td>
<td style="border: 1px solid #cccccc; padding: 6px;">Am9511A-1 #INT0 $C000-$C001 Registers</td>
</tr>
<tr>
<th style="border: 1px solid #cccccc; padding: 6px;">$E000 - $FFFF</th>
<td style="border: 1px solid #cccccc; padding: 6px;">-</td>
<td style="border: 1px solid #cccccc; padding: 6px;">Hold for Expansion</td>
</tr>
</tbody>
</table>
</div>

## Design Rules

_My house, my rules!_

Some design rules which (hopefully) will allow a responsive multi-tasking system to be built.

1. Only interrupt service routines should disable the global interrupt. No application should disable the global interrupt flag. The only exception to this is where an atomic outcome is needed, and there is no Z80 instruction available to achieve what is required.

2. All the hardware resources will be protected by their own Mutual Exclusion (mutex) semaphore (or lock). Irrespective of whether you need exclusive use of a resource, use the lock. Otherwise you might be trampling another application's I/O. Potentially, a queuing semaphore may be needed at some stage, but for now, it is simply a `SRA` based little mutex.

3. Shadow (alternate) registers are reserved for the use of the bank switching routines, and for yabios library code. Interrupt service routines should not use the shadow registers. Z88dk system library code uses shadow registers, and the calling yabios code will retain the `shadowLock` mutex, to ensure that the Z88dk library code is not affected by a bank switch at an inconvenient time.

4. Applications should use their own stack, which will be located at the top of the BANK space when they are initialised (unless otherwise defined), and not rely on the system stack being available. If parameters need to be passed on the stack to the library code, then they will have to be pushed onto the system stack, before the `system` call.

5. CP/M specific BIOS items will exist in the BANK space, below the YABIOS space, ensuring that the CP/M specific buffers and jump tables do not consume space in non-CP/M applications.

## System Function Definitions

These system functions are essential for creating bank handling for the YAZ180.

Whilst they will be exposed to the user through linkage into the Z88dk libraries, they are not expected to be used by an application, and they may cause harm to the coherency of the system if they are used.

### Note on BANK relative addressing, the `far void*`

For all memory related functions in the Z180 which extend beyond the Z80 addressing capability of 64kB, there needs to be a decision made as to how to address locations. Where a flat RAM model is being pursued, it makes sense to create a flat addressing structure.

However, in the YAZ180 we have a banked memory assignment. This means that the top of one bank is not contiguous with the bottom of another bank, and the YABIOS exists in a specific location in `BANK_0`. Therefore, we are never going to copy memory across the edge of a BANKED memory space. Both of these issues point to a slightly different addressing scheme.

For all far memory functions, the high byte of the 20bit address will be a twos complement bank-relative address. Additionally, as a later enhancement, calling far memory functions from a non-zero bank (as a user) will ensure that `BANK_0` and (`BANK13`, `BANK14`, and) `BANK15` cannot be reached, and `COMMON_AREA_1` memory cannot be written.

Far pointers will normally be passed in the `EHL` registers, as is the z88dk standard.<br>
`0xEE` is the twos complement bank address, as defined above.<br>
`0xHH` is the normal high or page address, within 64kB.<br>
`0xLL` is the normal low address, within 64kB.<br>

### `_memcpy_far`

`void *memcpy_far(void *str1, int8_t bank1, const void *str2, const int8_t bank2, size_t n)`<br>
`str1` − This is a pointer to the destination array where the content is to be copied, type-cast to a pointer of type `void*`.<br>
`bank1` − This is the destination bank, relative to the current bank.<br>
`str2` − This is a pointer to the source of data to be copied, type-cast to a pointer of type `void*`.<br>
`bank2` − This is the source bank, relative to the current bank.<br>
`n` − This is the number of bytes to be copied.<br>
This function returns a `void*` to destination, which is `str1` in `HL`.

IN:

    stack:
    n high
    n low
    bank2 far
    str2 high
    str2 low
    bank1 far
    str1 high
    str1 low
    ret high
    ret low

OUT:

    HL = `void*` to `str1`

Registers affected after return:
```
    ......../IXIY   preserved
    AFBCDEHL/....   modified
```
Notes:

`_memcpy_far` respects overlapping source and destination regions.
No checking is done to prevent writing to the `PAGE0` region, as this will be a common requirement.

Memory copying is done with DMAC0, using burst mode. This means that the CPU is halted during the transfer. This affects processing of other interrupts.

### `_load_hex`

`void _load_hex(char bank)`<br>
`bank` − This is the desired bank (in two's complement) _relative_ to the current bank. For example `0xFF` is one bank lower than the current bank.

IN:

    L = destination BANK, relative addressed.

OUT:

    -

Registers affected after return:
```
    ..BCDEHL/IXIY   preserved
    AF....../....   modified
exx AFBCDEHL        modified
```
Notes:

When called `_load_hex` waits for Intel HEX to be loaded via the CLI, and will load it into the provided initial bank. Any Type 2 ESA HEX instruction present within the Intel HEX will override CLI selection.

`_load_hex` provides an initial bank for loading the application. Type 2 ESA HEX information provides further _relative_ (preferred) bank information, in the [format defined above](https://github.com/feilipu/yaz180/tree/master/yabios#note-on-bank-relative-addressing), should the program to be loaded extend beyond one bank.

The contents of the alternate register set is modified only during the internal banks which function with interrupts disabled. This is only a momentary situation. Normal `_load_hex` operation is with interrupts enabled (to ensure that the ASCI interfaces are working).

No checking is done to prevent the `BANK_0` or flash memory bank (`BANK13`, `BANK14`, or) `BANK15` from being selected, if the system calls `_load_hex`.

No checking is done to prevent `PAGE0` and `COMMON AREA 1` memory being overwritten, if the system calls `_load_hex`.

When the user calls `_load_hex`, access to `BANK_0` will be prevented, enabling relocation of applications, and will ensure that critical `PAGE0` and `COMMON AREA 1` memory cannot be overwritten.

### `_load_bin`

`void _load_bin(far void* str)`<br>
`str` − This is a pointer to the destination where the content is to be copied, type-cast to a pointer of type `far void*`.<br>

IN:

    E = destination BANK, relative addressed.
    HL = `void*` to `str`

OUT:

    -

Registers affected after return:
```
    ..BC..../IXIY   preserved
    AF..DEHL/....   modified
exx AFBCDEHL        modified
```
Notes:

When called `_load_bin` waits for binary data to be loaded via the CLI, and will load it into memory starting from the provided initial destination  `str`.

The alternate register set is modified only during the internal `_bank_switch` function with interrupts disabled. This is only a momentary situation. Normal `_load_hex` operation is with interrupts enabled (to ensure that the ASCI interfaces are working).

No checking is done to prevent the `BANK_0` or flash memory bank (`BANK13`, `BANK14`, or) `BANK15` from being selected if the system calls `_load_bin`.

No checking is done to prevent `PAGE0` and `COMMON AREA 1` memory being overwritten, if the system calls `_load_bin`.

When the user calls `_load_bin`, access to `BANK_0` will be prevented, enabling relocation of applications, and will ensure that critical `PAGE0` and `COMMON AREA 1` memory cannot be overwritten.

## User System Interfaces

Access to YABIOS is designed to be through calls to the `RST20` System Call, and the `RST18` APU Call. Access to banked applications (greater than 60kB in size) is designed to be through the `RST10` `_call_far`. General management of the YAZ180 is to be done through the Command Line Interface.

Errors will be reported to an Error handler function located at `RST8`, registered for each application, as desired.

Additional short call `RST30` addresses may be used by the application as desired.

### `RST30` Reserved User Call

The user might want to have a `RST` short call available. Reserve this `RST` for user short calls within a bank.

### `RST28+DEFB` APU Call

Registers affected after return:
```
    ..B.DE../IXIY   preserved (check called APU Function)
    AF.C..HL/....   modified  (check called APU Function)
```
Notes:

YABIOS APU Calls are provided within the `COMMON AREA 1` memory space, and can be linked to an Z88dk application program.

For example, for the `APU_OP_SQRT` command the System Call is generated by following example byte code:

```
RST28
DEFB __IO_APU_IO_SQRT
```

Following execution of the APU Call, the operation returns to the calling application.

### `RST20+DEFW` System Call

IN:

    Parameters required to execute the System Call, in Registers, or on Stack

OUT:

    Parameters returned by the System Call

Registers affected after return:
```
    ......../IXIY   preserved (check called System Function)
    AFBCDEHL/....   modified  (check called System Function)
exx AFBCDEHL        modified  (check called System Function)
```
Notes:

YABIOS System Calls are provided within the `BANK_0`, or `COMMON AREA 1` memory space, and can be linked to an Z88dk application program.

For example, the `_f_printf` function parameters are placed on the Stack or Registers, and the System Call is generated by following example byte code:

```
RST20
DEFW _f_printf
```

Following execution of the System Call, the operation returns to the calling application.

The the contents of the alternate register set is modified during the internal bank switch with interrupts disabled, during a System Call. Interrupts are disabled only for a momentary situation. Normal operation is with interrupts enabled.  Therefore for YABIOS system functions that require the use of the alternate register set, some evaluation of the actual requirements will need to be completed.

### `RST18` `_jp_far`

IN:

    `far void *` in EHL, to the location

OUT:

Registers affected after return:
```
    ......../IXIY   preserved (check called System Function)
    AFBCDEHL/....   modified  (check called System Function)
exx AFBCDEHL        modified  (check called System Function)
```

Notes:

YABIOS `_jp_far` call are provided to support an application in its own memory space. The location of the application `_user_function` is provided by a `far void *`.

The `_jp_far` call is generated by following example byte code:

```
LD E, -1                ; Destination BANK, for example one bank below
LD HL, _user_function   ; Address of _user_function
RST18
```
The the contents of the alternate register set is modified during the internal bank switch with interrupts disabled, during a System Call. Interrupts are disabled only for a momentary situation. Normal operation is with interrupts enabled.

### `RST10+DEFW+DEFB` `_call_far`

IN:

    Parameters required to execute the `_user_function` call, in Registers or on Stack

OUT:

    Parameters returned by the `_user_function` call

Registers affected after return:
```
    ......../IXIY   preserved (check called _user_function)
    AFBCDEHL/....   modified  (check called _user_function)
exx AFBCDEHL        modified  (check called _user_function)
```
Notes:

YABIOS `_call_far` calls are provided to support an application in its own memory space. The location of the application `_user_function` is provided by a `far void *`.

The called `_user_function` parameters are placed on the Stack or Registers, and the `_call_far` call is generated by following example byte code:

```
RST10
DEFW 0xHHLL
DEFB 0xEE
```

Where:<br>
0xHHLL = `void*` to `_user_function`
0xEE = destination BANK, _relative_ addressed, to the current BANK.<br>

Following execution `_user_function` call, the operation returns to the calling application.

The the contents of the alternate register set is modified during the internal bank switch with interrupts disabled, during a System Call. Interrupts are disabled only for a momentary situation. Normal operation is with interrupts enabled.

### `RST8+DEFB` Error Handler

IN:

    Parameters required to execute the `_error` call, in Registers or on Stack

OUT:

    Parameters returned by the `_error` call

Registers affected after return:
```
    ......../IXIY   preserved (check called _error Function)
    AFBCDEHL/....   modified  (check called _error Function)
```
Notes:

YABIOS `_error` calls are provided to support an application in its own memory space. The location of the application `_error` function is provided by a `void*` within the application's own bank.

The `_error` parameters are placed on the Stack or Registers, and the `_error` call is generated by following example byte code:

```
RST08
DEFB 0xEE           ; optional if error code is placed in subset of DEHL
```

Where:<br>
EE = error code as defined by the application.<br>

Following execution `_error` call, the operation returns to the Command Line interface via `_warm_start`, and does not return to the calling function.

```
RST08:
    pop hl             ; get return address in hl
    call _error        ; user provided function, minimum is `ret`
    jp _warm_start     ; YABIOS provided warm restart function
```

### Command Line Interface

The command line interface is implemented in C, with the underlying functions either in C or in assembly.

#### CP/M Functions
- `mkcpmb [src][dest][file][][][]` - initialise dest bank for CP/M from src bank, up to 4 drive files
- `mkcpmd [file][dir][bytes]` - create a drive file for CP/M, with dir entries, of bytes size

#### Bank Functions
- `mkb [bank]` - initialise the nominated bank (to warm state)
- `cpb [src][dest]` - copy or clone the nominated src bank
- `rmb [bank]` - remove the nominated bank (to cold state)
- `lsb` - list the usage of banks, and whether they are cold, warm, or hot (not implemented)
- `initb [bank][origin]` - begin executing the nominated bank at nominated address
- `loadh [bank]` - load the nominated bank with Intel Hex from ASCI0 / ASCI1 (ESA supported)
- `loadb [path][bank][origin]` - load the nominated bank from origin with binary code
- `saveb [bank][path]` - save the nominated bank from 0x0100 to 0xF000

#### System Functions
- `md [bank][origin]` - memory dump, origin in hexadecimal
- `help` - this is it
- `exit` - exit and restart

#### File System Functions
- `ls [path]` - directory listing
- `rm [path]` - delete a file
- `cp [src][dest]` - copy a file
- `cd [path]` - change the current working directory
- `pwd` - show the current working directory
- `mkdir [path]` - create a new directory
- `chmod [path][attr][mask]` - change file or directory attributes
- `mount [path][option]` - mount a FAT file system

#### Disk Functions
- `ds` - disk status
- `dd [sector]` - disk dump, sector in decimal

#### Time Functions
- `clock [timestamp]` - set the time (UNIX epoch) using `date +%s`
- `tz [tz]` - set timezone (no daylight saving)
- `diso` - local time ISO format: 2013-03-23 01:03:52
- `date` - local time: Sun Mar 23 01:03:52 2013

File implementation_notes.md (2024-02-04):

# Implementation Notes

These are some notes taken during implementation, so that the scraps of paper don't get lost.

## FIXME

- [x] convert APU driver from storing operand pointers, to actually store operands.<br>
- [ ] implement mutex lock code for apu [ ], asci0 [ ], and asci1 [ ].<br>

## Why the `COMMON_AREA_1` shrunk

Now that we're trying to keep the `COMMON_AREA_1` space down to 4kB, we need to pack things in tight.

The CP/M BIOS functions will be below the YABIOS area, because they relate only to CP/M, and there are some large allocation vectors for the disks that are not required for other systems. So, don't push them on other systems. We can then choose whether the CP/M BDOS/BIOS is large or small, depending on how we prepare the hard drive files.

## Calculating `COMMON1` addresses

We have `$0500` bytes of aligned buffers, with the two ASCI and the APU. Put them at the bottom of `COMMON1`, then unaligned data starts at `$F500`. That allows the code section to flow after, and makes copying on setup a single transfer.

The ASCI Tx buffers share a single page, and are interleaved. This provides 127 bytes of Tx buffer and doesn't require manual buffer wrapping. Page alignment ensure that we only have to increment the low address byte to have the buffer wrap properly.

So that the Z80 jump and Z180 vector tables don't have to be moved, put them at the top. Therefore the Z80 `__IO_VECTOR_BASE` is `$FFE0`, and with the Z180 `__crt_io_vector_base` being `0x00` bytes later also at `$FFE0`. The Z80 jump table is empty. Z80 jump tables in `BANK_0` point directly at the relevant RST functions in `BANK_0`, and in other banks they can be configured as the application in that bank desires.

That puts the initial system stack pointer at `$FFDE` (pre-decrement), with two bytes available from `$FFDE` to enable the global SP to be stored, when local SP is switched over.

## Modifying the memory model

Based on the above, we can allow the memory model to be expanded by just 3 items. The `rodata_page0` contains `$003B` bytes of simple page zero code, to be replicated to each `BANK_n` during initialisation, and when a bank is reloaded.

Then the `rodata_common1_data` and `rodata_common1_driver` can just follow each other into the space from `$F000`. The global stack will grow down to meet them somewhere (hopefully not too often).

```asm
section rodata_page0
section rodata_common1_data
section rodata_common1_driver
```

## Moving the Z88dk files around because `PHASE`

We need to have the YABIOS constructed in just three files. The `PAGE0` file, the `COMMON1_DATA` file, and the `COMMON1_DRIVER` file. This is pretty simple, based on the fact that we can't handle multiple files with phase currently. It breaks the nice model of one file per function, but that's ok for now. We don't have too many functions we want to put in the common area 1 memory.

## Setting up the Z80 `RST` calls

Because we're using all of the `RST` calls, (except `RST28` is reserved for the user, and `RST30` is reserved for FUZIX), the resulting code is `$00FE`. There is no Z80 jump table built, and the `RST` jumps will be directly to the actual function. These functions calls must be filled into the page zero table in `rodata_page0`.

The `__crt_enable_trap` enables us to use the `RST00` to do a warm boot, or optionally jump to the start of a transitory program in TPA space `$0100`.

```asm
   defc TAR__crt_enable_rst            = 0x00FE
   defc TAR__crt_enable_nmi            = 0
   defc TAR__crt_enable_trap           = 1
```

## What needs to be in `COMMON_AREA_1`?

Based on the [design rules](https://github.com/feilipu/yaz180/blob/master/yabios/README.MD#design-rules), the following things will need to be in the `COMMON_AREA_1` so that they can respond quickly.

- All interrupt code, for Z180 interrupts, and the Z80 INT0 APU ISR.
- ASCI0/1 get character code, so that `_load_hex` and `_load_bin` can work quickly.
- Banking code and handling the error, system and APU `RST` calls.
- DMAC0/1 code for doing `_memcpy_far` and `_memset_far`.
- Any Z80dk library code that is called by either a `PAGE0` or `COMMON_AREA_1` resident call, unless it is specifically a banked call.
- Scheduling code, when we get that far...

## What needs to be in `BANK_0` RAM?

These elements need to be either statically defined the `BANK_0` RAM, or located in the system heap space also in `BANK_0`.

- Disk I/O buffers
- FatFS
- Floating point library conversions, and soft floating point
- clib
- time functions
- driver code that is not time critical or is large (i2c, graphics).

The boot monitor code will be the major program located in `BANK_0` Flash, and this will be written in C.

## Sadly, there can never be a `jp_far`

I modified the `call_far` code to make a `jp_far` using the `RSTx + DEFW + DEFC` mechanism, but forgot that a `jp` instruction doesn't push the `PC` onto the stack. Therefore there is no way to know from whence the program arrived, when it hits the `rst` instruction. Damn. It would have been so nice to just switch banks like that. I guess the only way to do it is off the stack (costing the ability to pass some parameters).

## Stack Canary

After finding there were stack issues, I built a canary that `xor` two bytes. These two bytes are located at the end of the CA1 code, and are the first thing the bios stack will grow down to meet. The stack canary is checked once per second by the system tick. An error code of `0x40` will be printed on the console if the stack collides with the CA1 code.

As part of resolving this issue, I had to delete the `_memset_far` function. I think it was the most unnecessary piece of code of all the functions in CA1.

## Compilation Command Line

First make sure that the ff and time libraries are installed into Z88dk using the `z88dk-lib` tool.
```bash
> zcc +yaz180 -subtype=rom -clib=sdcc_iy -SO3 --opt-code-speed --max-allocs-per-node400000 -v -m -llib/yaz180/ff -llib/yaz180/time --math32 @yabios.lst -gpf:yabios.rex -o yabios -create-app
```

or
```bash
> zcc +yaz180 -subtype=rom -clib=new -O2 --opt-code-speed=all -v -m -llib/yaz180/ff -llib/yaz180/time --math32 @yabios.lst -gpf:yabios.rex -o yabios -create-app
```

This generates a `yabios.ihx` file that can be written to the YAZ180 flash.

It also generates a `yabios.def` file containing the calling linkages for the particular compile. Note that this API may be unstable, because of the constant development in Z88dk, sdcc, and the resulting sizes of the `ff.lib` and `time.lib` system libraries. So once the YAZ180 flash is written, then the `yaz180.def` (or possibly renamed to `yaz180.asm`) API will be needed for every application.

## Loading Flash from outside yabios

It is possible to load (`BANK13`, `BANK14`, and) `BANK15` with application code either from the perl programming interface, or via the TL866 programming tool. Applications written in this way can be loaded to an initialised (`mkb`) bank using the `mvb` or `mkcpmb` command and then executed using `initb` as normal. The v2.1 PCB (2017) doesn't connect A17 to the flash, so it is limited to 128kB. The CUPL has been modified to put the upper page in `BANK15`. Other CUPL options are commented out, for v2.2 PCB (2018) and later, which has both A17 and A18 connected.

## CP/M Implementation

The CP/M implementation supports both ASCI interfaces, with ASCI0 being the CRT and ASCI1 being the TTY. The CP/M CCP+BDOS is now running, and the disk interface has been completed.

```bash
> zcc +yaz180 -subtype=app --no-crt -m --list @cpm22.lst -o cpm22; z88dk-appmake +glue -b cpm22 --ihex --clean
> cat > /dev/ttyUSB0 < cpm22__.ihx
```

I've added the `_f_expand()` function into the FATFs implementation, as this will allow the YABIOS command line to create a correctly sized CP/M drive, which can then be added / or exchanged for other drives simply by renaming it. Formatting and other CP/M "disk" management will be done from within CP/M, using the YABIOS tools.

I've added an `EXIT` function into the CP/M CCP. This is to allow the CP/M system to terminate and return to yabios in `BANK_0` successfully. CP/M can be reinitialised, simply with the `initb n` command.

## CP/M TOOLS Usage

CP/M drive files can be read and written using a host PC with any operating system, by using the [`cpmtools`](http://www.moria.de/~michael/cpmtools/) utilities, simply by inserting the IDE drive in a USB drive caddy.

The CP/M TOOLS package v2.20 is available from debian repositories.

Check the disk image, `ls` a CP/M image, copy a file (in this case `bbcbasic.com`).

```bash
> fsed.cpm -f yaz180-8MB a.cpm
> cpmls -f yaz180-8MB a.cpm
> cpmcp -f yaz180-8MB a.cpm ~/Desktop/CPM/bbcbasic.com 0:BBCBASIC.COM
```

The contents of the `/etc/cpmtools/diskdefs` file need to be augmented with disk information specific to the YAZ180.

```
diskdef yaz180-8MB
  seclen 512
  tracks 64
  sectrk 256
  blocksize 4096
  maxdir 2048
  skew 0
  boottrk -
  os 2.2
end
```

## CP/M System Disk

I have found that the [RunCPM system disk](https://github.com/MockbaTheBorg/RunCPM/tree/master/DISK) contains a good package of CP/M utilities, that can just be loaded onto a disk for a complete ready to run CP/M.

I've also found the [NGS Microshell](http://www.z80.eu/microshell.html) to be very useful, so I add it to my system disk too. No need to add it permanently. In fact, adding it will remove the special `EXIT` function I built into the CCP to return to yabios.

The [`yash`](https://github.com/z88dk/z88dk-ext/blob/master/os-related/CPM/yash.c) application can be used to manage CP/M drive files without moving the PATA drive to a host computer. This application supports both read and write to the underlying FATFS file system.

## Layout issue - January 31, 2018 - PCB v2.1 2017

Noted that I selected the wrong device for the flash, being the 128kB version. This means that the Address 17 pin is not connected, by accident. When doing the v2.2 PCB, I will next select the 512kB device, and connect both A17 and A18 to the flash device, as this will provide some extra flexibility, if more flash memory is required.

## Layout issue - March 1, 2018 - PCB v2.2 2018

The ESP-01S can't have the DIO lines pulled high when booting. This means that the two DIO pins on the connecter must be removed, to prevent these lines from contacting.

## Legacy CP/M Drive - 512 Directory Entries

Note that for yaz180 CP/M v2.0 the maximum directory entries were increased to 2048, and the file size reduced to 8MB.
CP/M 2.2 BDOS uses 16 bit registers to calculate the ARECORD location, which overflows beyond 8 MB files.

These cpmtools entries below are for the (__obsolete__) v1.x releases of yaz180 CP/M.

```
diskdef yaz180v1-16MB
  seclen 512
  tracks 1024
  sectrk 32
  blocksize 4096
  maxdir 512
  skew 0
  boottrk -
  os 2.2
end
```

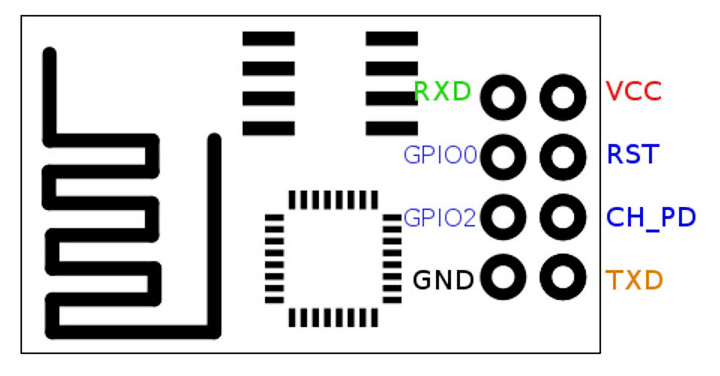
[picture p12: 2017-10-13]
docs/datasheets/esp8266-esp-01e-pinouts.jpg

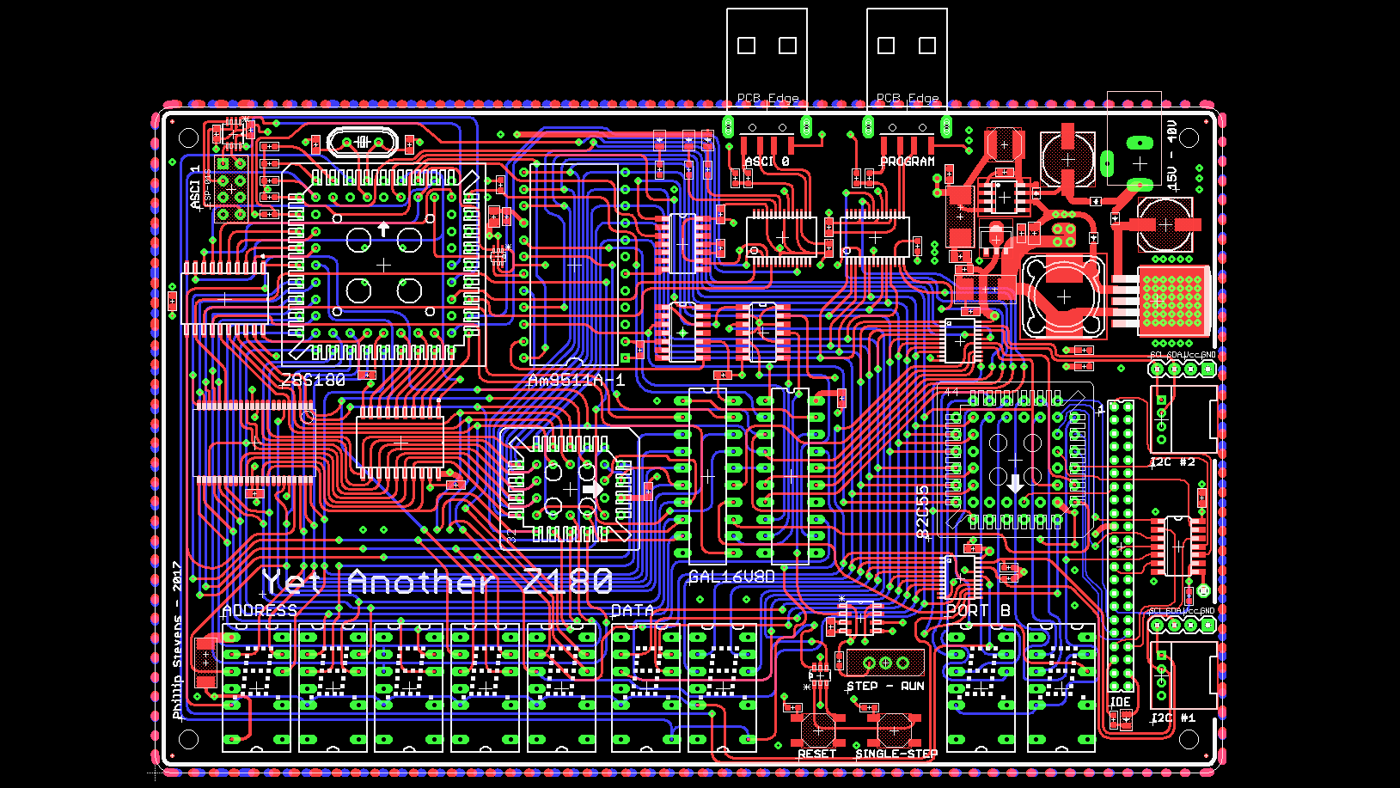
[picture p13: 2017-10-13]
docs/YAZ180v2.1.png

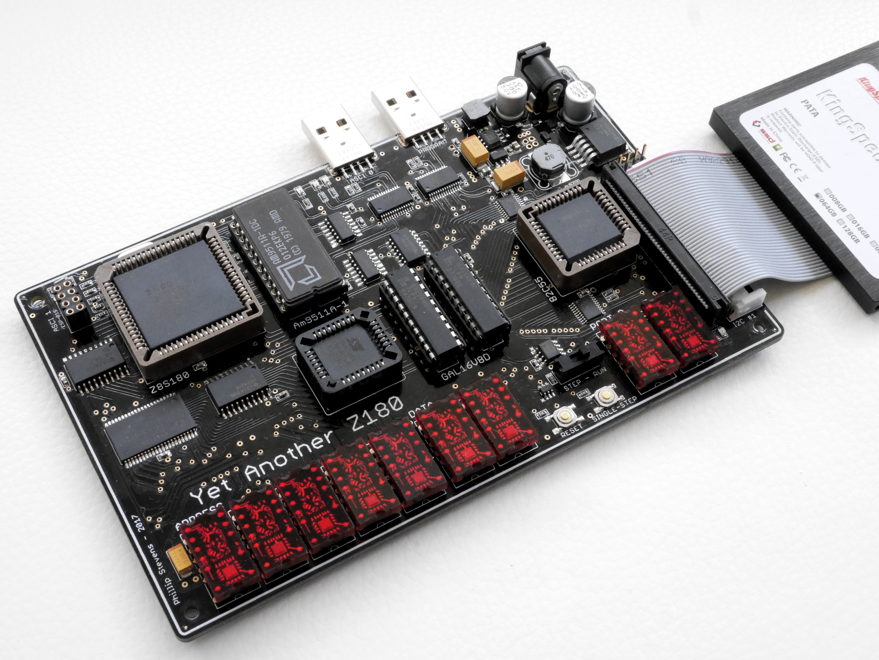
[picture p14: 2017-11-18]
docs/YAZ180v21_ide.JPG

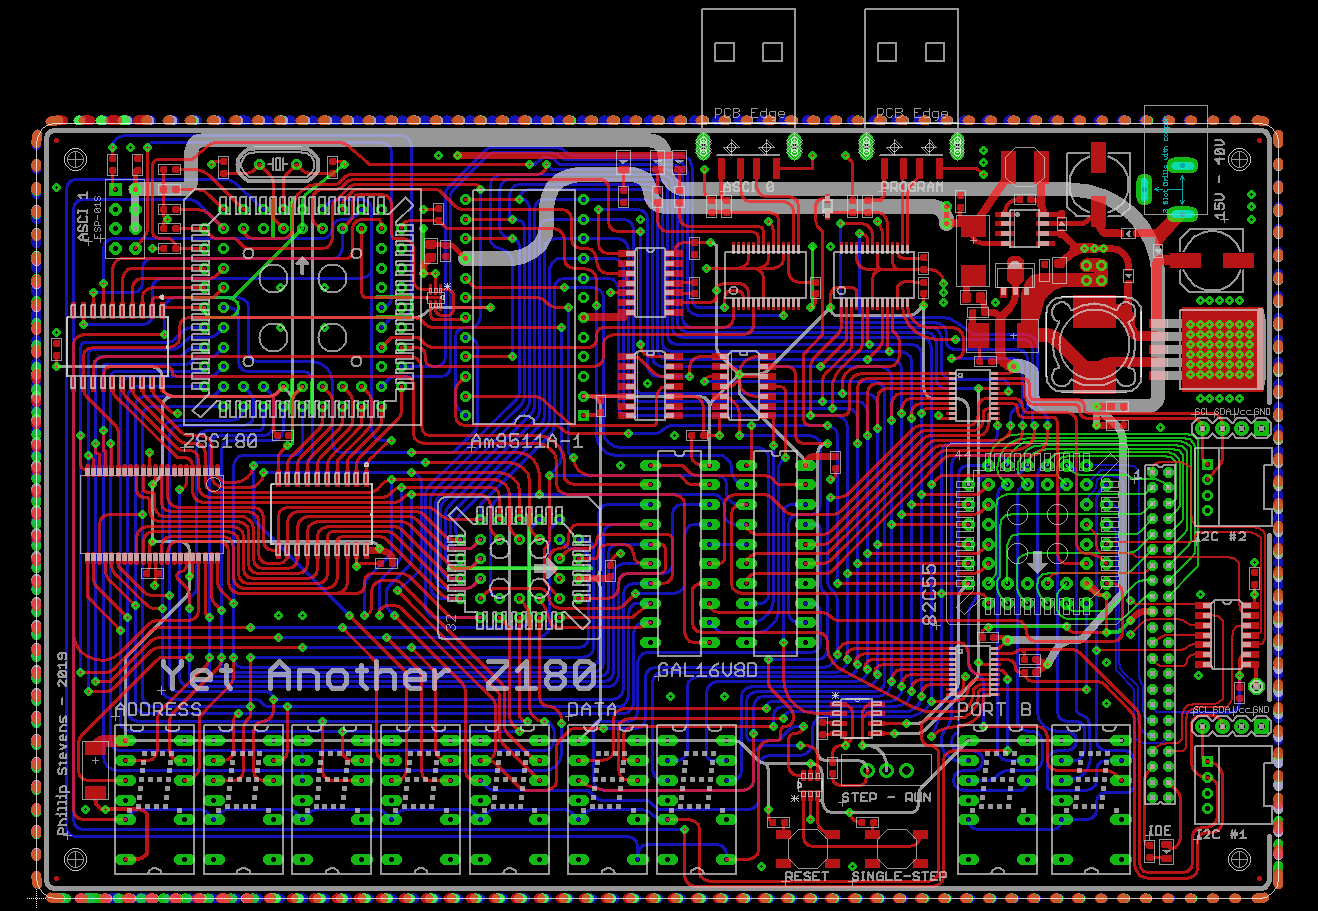
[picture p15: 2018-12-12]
docs/YAZ180v2.3.png

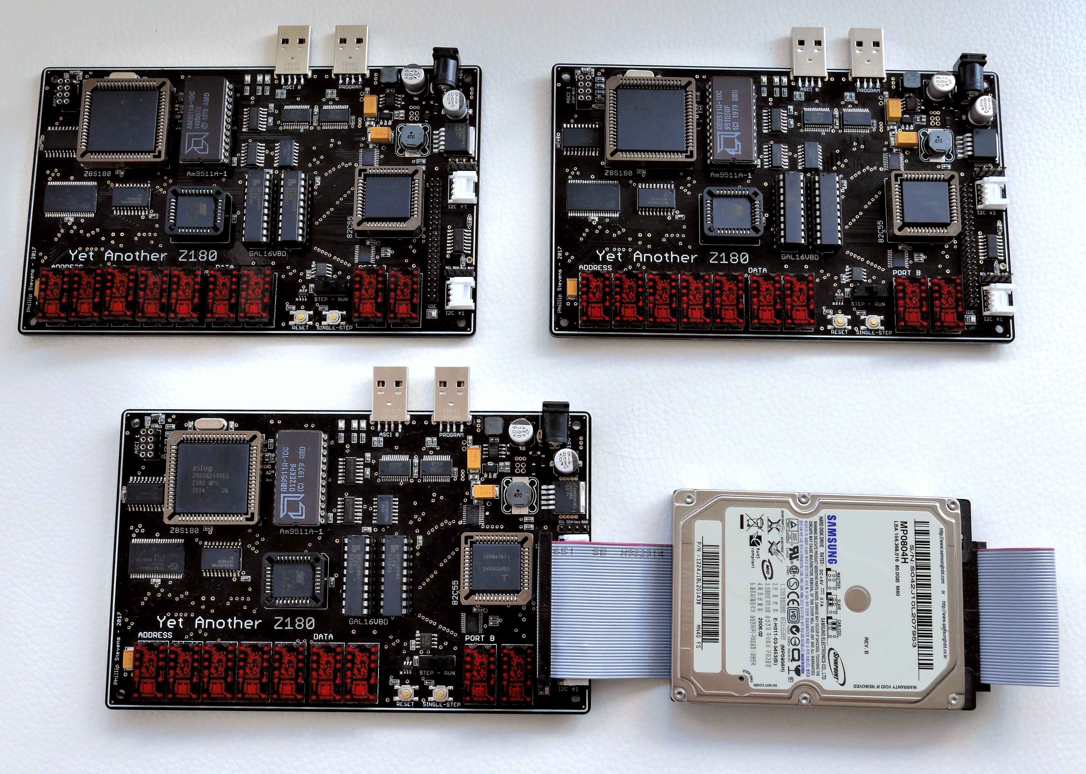
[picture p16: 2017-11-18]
docs/YAZ180v21_family.JPG

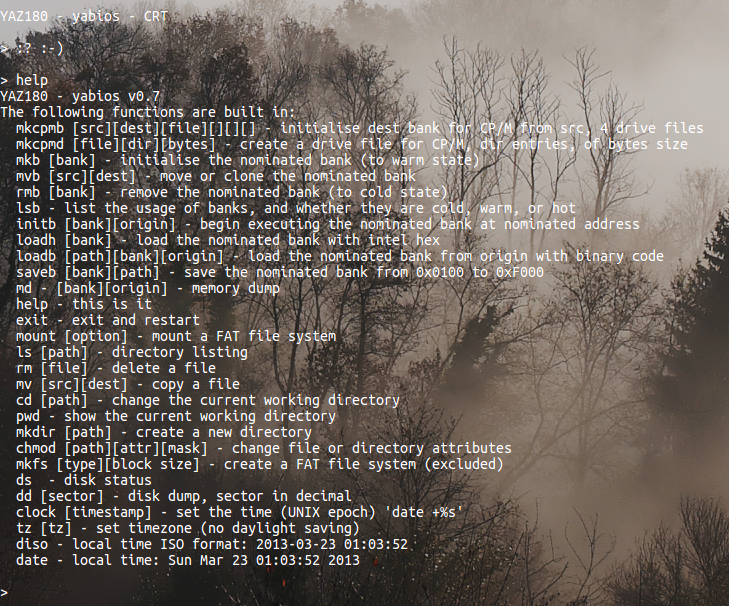
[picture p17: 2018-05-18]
docs/yabios_help.png

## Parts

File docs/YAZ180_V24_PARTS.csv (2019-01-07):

Part | Value | Device | Package | Description | MF | MPN | OC_FARNELL | OC_NEWARK | PACKAGE | SUPPLIER | TP_SIGNAL_NAME | VALUE
!INT_IDE | TPSPAD1-13 | TPSPAD1-13 | P1-13 | TEST PIN
C1 | 100nf | CERAMIC-100NF-50V-10%-X7R(0603) | C0603 | 302010138 |  | CC0603KRX7R9BB104 |  |  |  |  |  | 100nf
C2 | 100nf | CERAMIC-100NF-50V-10%-X7R(0603) | C0603 | 302010138 |  | CC0603KRX7R9BB104 |  |  |  |  |  | 100nf
C3 | 22pf | CERAMIC-22PF-50V-5%-NPO(0603) | C0603 | 302010143 |  |  |  |  |  |  |  | 22pf
C4 | 22pf | CERAMIC-22PF-50V-5%-NPO(0603) | C0603 | 302010143 |  |  |  |  |  |  |  | 22pf
C5 | 2.2uf | CERAMIC-2.2UF-10V-10%-X7R(0603) | C0603 | 302010054 |  | CC0603KRX7R6BB225 |  |  |  |  |  | 2.2uf
C6 | 22pf | CERAMIC-22PF-50V-5%-NPO(0603) | C0603 | 302010143 |  |  |  |  |  |  |  | 22pf
C7 | 100uf | ALUMINUM-SMD-100UF-50V(D8-H10.5MM) | ELECTRO-SMD-E-7.8MM | 302030095 |  | CS1H101M-CRF10 |  |  |  |  |  | 100uf
C8 | 100uf | ALUMINUM-SMD-100UF-50V(D8-H10.5MM) | ELECTRO-SMD-E-7.8MM | 302030095 |  | CS1H101M-CRF10 |  |  |  |  |  | 100uf
C9 | 220uf | TANTALUM-SMD-220UF-16V(AVX-E) | AVX-E | 302020032 |  | TAJE227K016RNJ |  |  |  |  |  | 220uf
C10 | 220uf | TANTALUM-SMD-220UF-16V(AVX-E) | AVX-E | 302020032 |  | TAJE227K016RNJ |  |  |  |  |  | 220uf
C11 | 100uf | TANTALUM-SMD-100UF-16V(AVX-C) | AVX-C | 302020023 |  | TAJC107K016RNJ |  |  |  |  |  | 100uf
C12 | 10uf | CERAMIC-10UF-25V-10%-X5R(0805) | C0805 | 302010178 |  | CC0805KKX5R8BB106 |  |  |  |  |  | 10uf
C13 | 100nf | CERAMIC-100NF-50V-10%-X7R(0603) | C0603 | 302010138 |  | CC0603KRX7R9BB104 |  |  |  |  |  | 100nf
C14 | 100nf | CERAMIC-100NF-50V-10%-X7R(0603) | C0603 | 302010138 |  | CC0603KRX7R9BB104 |  |  |  |  |  | 100nf
C15 | 100nf | CERAMIC-100NF-50V-10%-X7R(0603) | C0603 | 302010138 |  | CC0603KRX7R9BB104 |  |  |  |  |  | 100nf
C16 | 100nf | CERAMIC-100NF-50V-10%-X7R(0603) | C0603 | 302010138 |  | CC0603KRX7R9BB104 |  |  |  |  |  | 100nf
C17 | 100nf | CERAMIC-100NF-50V-10%-X7R(0603) | C0603 | 302010138 |  | CC0603KRX7R9BB104 |  |  |  |  |  | 100nf
C18 | 100nf | CERAMIC-100NF-50V-10%-X7R(0603) | C0603 | 302010138 |  | CC0603KRX7R9BB104 |  |  |  |  |  | 100nf
C19 | 100nf | CERAMIC-100NF-50V-10%-X7R(0603) | C0603 | 302010138 |  | CC0603KRX7R9BB104 |  |  |  |  |  | 100nf
C20 | 100nf | CERAMIC-100NF-50V-10%-X7R(0603) | C0603 | 302010138 |  | CC0603KRX7R9BB104 |  |  |  |  |  | 100nf
C21 | 100nf | CERAMIC-100NF-50V-10%-X7R(0603) | C0603 | 302010138 |  | CC0603KRX7R9BB104 |  |  |  |  |  | 100nf
C22 | 100nf | CERAMIC-100NF-50V-10%-X7R(0603) | C0603 | 302010138 |  | CC0603KRX7R9BB104 |  |  |  |  |  | 100nf
C23 | 100nf | CERAMIC-100NF-50V-10%-X7R(0603) | C0603 | 302010138 |  | CC0603KRX7R9BB104 |  |  |  |  |  | 100nf
C24 | 100nf | CERAMIC-100NF-50V-10%-X7R(0603) | C0603 | 302010138 |  | CC0603KRX7R9BB104 |  |  |  |  |  | 100nf
C25 | 100nf | CERAMIC-100NF-50V-10%-X7R(0603) | C0603 | 302010138 |  | CC0603KRX7R9BB104 |  |  |  |  |  | 100nf
C26 | 10uf | CERAMIC-10UF-25V-10%-X5R(0805) | C0805 | 302010178 |  | CC0805KKX5R8BB106 |  |  |  |  |  | 10uf
C27 | 10nf | CERAMIC-10NF-50V-10%-X7R(0603) | C0603 | 302010140 |  | CC0603KRX7R9BB103 |  |  |  |  |  | 10nf
C28 | 100nf | CERAMIC-100NF-50V-10%-X7R(0603) | C0603 | 302010138 |  | CC0603KRX7R9BB104 |  |  |  |  |  | 100nf
C29 | 10uf | CERAMIC-10UF-25V-10%-X5R(0805) | C0805 | 302010178 |  | CC0805KKX5R8BB106 |  |  |  |  |  | 10uf
C30 | 100nf | CERAMIC-100NF-50V-10%-X7R(0603) | C0603 | 302010138 |  | CC0603KRX7R9BB104 |  |  |  |  |  | 100nf
C31 | 100nf | CERAMIC-100NF-50V-10%-X7R(0603) | C0603 | 302010138 |  | CC0603KRX7R9BB104 |  |  |  |  |  | 100nf
C32 | 100nf | CERAMIC-100NF-50V-10%-X7R(0603) | C0603 | 302010138 |  | CC0603KRX7R9BB104 |  |  |  |  |  | 100nf
D1 | 60V-3A | SMD-DIODE-SCHOTTKY-60V-1A(SOD-323) | SOD-323 | 304020026 |  | PMEG6010CEJ,115 |  |  |  |  |  | 60V-1A
D2 | 60V-1A | SMD-DIODE-SCHOTTKY-60V-1A(SOD-323) | SOD-323 | 304020026 |  | PMEG6010CEJ,115 |  |  |  |  |  | 60V-1A
D3 | 60V-3A | SMD-DIODE-SCHOTTKY-60V-1A(SOD-323) | SOD-323 | 304020026 |  | PMEG6010CEJ,115 |  |  |  |  |  | 60V-1A
D4 | 60V-1A | SMD-DIODE-SCHOTTKY-60V-1A(SOD-323) | SOD-323 | 304020026 |  | PMEG6010CEJ,115 |  |  |  |  |  | 60V-1A
D5 | SMD-LED-CLEAR-YELLOW(0805) | SMD-LED-CLEAR-YELLOW(0805) | LED-0805 | 304090039 |  | 17-215UYC/S530-A3/TR8
D6 | SMD-LED-CLEAR-GREEN(0805) | SMD-LED-CLEAR-GREEN(0805) | LED-0805 | 304090057 |  | 17-215SYGC/S530-E2/TR8
D7 | SMD-LED-CLEAR-RED(0805) | SMD-LED-CLEAR-RED(0805) | LED-0805 | 304090046 |  | 17-215SURC/S530-A2/TR8
D8 | SMD-LED-CLEAR-RED(0805) | SMD-LED-CLEAR-RED(0805) | LED-0805 | 304090046 |  | 17-215SURC/S530-A2/TR8
D9 | 1N4148WS | 1N4148WS | SOD323F | 1N4148 General Purpose Rectifie
DIS1 | HTIL311A | HTIL311A | HTIL311A | LED DISPLAY 1-character dot matrix, 2 decimal points |  |  | unknown | unknown
DIS2 | HTIL311A | HTIL311A | HTIL311A | LED DISPLAY 1-character dot matrix, 2 decimal points |  |  | unknown | unknown
DIS3 | HTIL311A | HTIL311A | HTIL311A | LED DISPLAY 1-character dot matrix, 2 decimal points |  |  | unknown | unknown
DIS4 | HTIL311A | HTIL311A | HTIL311A | LED DISPLAY 1-character dot matrix, 2 decimal points |  |  | unknown | unknown
DIS5 | HTIL311A | HTIL311A | HTIL311A | LED DISPLAY 1-character dot matrix, 2 decimal points |  |  | unknown | unknown
DIS6 | HTIL311A | HTIL311A | HTIL311A | LED DISPLAY 1-character dot matrix, 2 decimal points |  |  | unknown | unknown
DIS7 | HTIL311A | HTIL311A | HTIL311A | LED DISPLAY 1-character dot matrix, 2 decimal points |  |  | unknown | unknown
DIS8 | HTIL311A | HTIL311A | HTIL311A | LED DISPLAY 1-character dot matrix, 2 decimal points |  |  | unknown | unknown
DIS9 | HTIL311A | HTIL311A | HTIL311A | LED DISPLAY 1-character dot matrix, 2 decimal points |  |  | unknown | unknown
ESP-01S | ESP-01S | DIP-BLACK-FEMALE-HEADER(2X4P-2.54) | H2X4-2.54 | 320030087 |  |  |  |  |  |  |  | 2X4P-2.54
IC1 | 74LS93D | 74LS93D | SO14 | Decade, divide by twelve and binary COUNTER
IC3 | 74ACT74D | 74ACT74D | SO14 | Dual D type positive edge triggered FLIP FLOP, preset and clear
IC4 | IS62WV10248DALL-55T | IS62WV10248DALL-55T | TSOP-II-44 | 1024k x 8 low voltage, ultra low power CMOS static RAM
IC5 | SST39VF010 | SST39VF010 | S32 | 1 Mbit x8 Multi-Purpose Flash
IC6 | ATF16V8BP3 | ATF16V8BP3 | DIL20 | High perfomance CMOS (electrically erasable) programmable logic device (PLD) |  | ATF16V8CZ-15PU | 1551768 | 94M6254
IC7 | ATF16V8BP3 | ATF16V8BP3 | DIL20 | High perfomance CMOS (electrically erasable) programmable logic device (PLD) |  | ATF16V8CZ-15PU | 1551768 | 94M6254
IC8 | 74121D | 74121D | SO14 | Monostable MULTIVIBRATOR, schmitt trigger inputs
IC9 | 82c55 | 82C55APLCC44-S | S44 | MICROCOMPUTER/PERIPHERAL DEVICE
IC10 | LM2674AM-12V | LM2674AM | SO08 | National Semiconductor 0.5A Simple Switcher"(c)"
IC11 | FT232RL | FT232RL | SSOP28DB | USB UART
IC12 | FT245RL | FT245RL | SSOP28DB | USB FIFO Controller
IC13 | 74HCT04D | 74HCT04D | SO14 | Hex INVERTER
IC14 | PCA9665 | PCA9665 | TSSOP20 | IC CNTRLR PARALLEL/I2C 20TSSOP
IC15 | PCA9665 | PCA9665 | TSSOP20 | IC CNTRLR PARALLEL/I2C 20TSSOP
IC17 | LM2596S-5V | LM2596S | TO263-5 | SIMPLE SWITCHER® Power Converter 150 kHz 3A Step-Down Voltage Regulator | NATIONAL SEMICONDUCTOR | LM2596S-ADJ/NOPB | 9494367 | 41K3842
IDE | 87758-4416 | 87758-4416 | 87758-4416 | 44 Pin - 2mm Dual Row Single Wafer, Vertical T/H HDR | MOLEX | 87758-4416 | unknown | 59J1588
J1 | DC-005 | CONN-POWER-JACK-2.1MM(DC-005) | DCJ3P-14.2X11.0X9.0MM | 320120003 |  | DC-005 |  |  |  |  |  | DC-005
J2 | I2C Grove 2 | GROVE-CONNECTOR-DIP-90D(4P-2.0) | HW4-2.0-90D | 320110034
J3 | I2C Grove 1 | GROVE-CONNECTOR-DIP-90D(4P-2.0) | HW4-2.0-90D | 320110034
J6 | I2C Pinout 1 | I2C_STANDARD | 1X04 | SparkFun has standardized on a pinout for all I2C based sensor breakouts.
J7 | I2C Pinout 2 | I2C_STANDARD | 1X04 | SparkFun has standardized on a pinout for all I2C based sensor breakouts.
L1 | 33uH | MSS1260 | MSS1260 | SMT Power Inductor
L2 | 200UH | SMD-INDUCTOR-200UH-20%(2P-5X5MM) | SMD-2P-5.0X5.0X2.0MM | 303010140 |  | SWPA5020S220MT |  |  |  |  |  | 200UH
R1 | 270R | SMD-RES-270R-1%-1/10W(0603) | R0603 | 301010197 |  | RC0603FR-07270RL |  |  |  |  |  | 270R
R2 | 10K | SMD-RES-10K-1%-1/10W(0603) | R0603 | 301010299 |  | RC0603FR-0710KL
R3 | 270R | SMD-RES-270R-1%-1/10W(0603) | R0603 | 301010197 |  | RC0603FR-07270RL |  |  |  |  |  | 270R
R4 | 270R | SMD-RES-270R-1%-1/10W(0603) | R0603 | 301010197 |  | RC0603FR-07270RL |  |  |  |  |  | 270R
R5 | 10K | SMD-RES-10K-1%-1/10W(0603) | R0603 | 301010299 |  | RC0603FR-0710KL
R6 | 10K | SMD-RES-10K-1%-1/10W(0603) | R0603 | 301010299 |  | RC0603FR-0710KL
R7 | 10K | SMD-RES-10K-1%-1/10W(0603) | R0603 | 301010299 |  | RC0603FR-0710KL
R8 | 270R | SMD-RES-270R-1%-1/10W(0603) | R0603 | 301010197 |  | RC0603FR-07270RL |  |  |  |  |  | 270R
R9 | 4.7K | SMD-RES-4.7K-5%-1/10W(0603) | R0603 | 301010290 |  | RC0603JR-074K7L |  |  |  |  |  | 4.7K
R10 | 10K | SMD-RES-10K-1%-1/10W(0603) | R0603 | 301010299 |  | RC0603FR-0710KL |  |  |  |  |  | 10K
R11 | 10K | SMD-RES-10K-1%-1/10W(0603) | R0603 | 301010299 |  | RC0603FR-0710KL |  |  |  |  |  | 10K
R12 | 10K | SMD-RES-10K-1%-1/10W(0603) | R0603 | 301010299 |  | RC0603FR-0710KL
R13 | 10K | SMD-RES-10K-1%-1/10W(0603) | R0603 | 301010299 |  | RC0603FR-0710KL |  |  |  |  |  | 10K
R14 | 4.7K | SMD-RES-4.7K-5%-1/10W(0603) | R0603 | 301010290 |  | RC0603JR-074K7L |  |  |  |  |  | 4.7K
R15 | 4.7K | SMD-RES-4.7K-5%-1/10W(0603) | R0603 | 301010290 |  | RC0603JR-074K7L |  |  |  |  |  | 4.7K
R16 | 10K | SMD-RES-10K-1%-1/10W(0603) | R0603 | 301010299 |  | RC0603FR-0710KL
R17 | 10K | SMD-RES-10K-1%-1/10W(0603) | R0603 | 301010299 |  | RC0603FR-0710KL
R18 | 10K | SMD-RES-10K-1%-1/10W(0603) | R0603 | 301010299 |  | RC0603FR-0710KL
R19 | 10K | SMD-RES-10K-1%-1/10W(0603) | R0603 | 301010299 |  | RC0603FR-0710KL
R20 | 2.2K | SMD-RES-2.2K-5%-1/10W(0603) | R0603 | 301010124 |  | RC0603JR-072K2L |  |  |  |  |  | 2.2K
R21 | 2.2K | SMD-RES-2.2K-5%-1/10W(0603) | R0603 | 301010124 |  | RC0603JR-072K2L |  |  |  |  |  | 2.2K
R22 | 2.2K | SMD-RES-2.2K-5%-1/10W(0603) | R0603 | 301010124 |  | RC0603JR-072K2L |  |  |  |  |  | 2.2K
R23 | 2.2K | SMD-RES-2.2K-5%-1/10W(0603) | R0603 | 301010124 |  | RC0603JR-072K2L |  |  |  |  |  | 2.2K
R24 | 270R | SMD-RES-270R-1%-1/10W(0603) | R0603 | 301010197 |  | RC0603FR-07270RL |  |  |  |  |  | 270R
SW1 | SINGLE STEP | SMD-BUTTON(4P-4.0X4.0X1.7MM)-DHT-1152 | SW4-SMD-4.0X4.0X1.7MM | 311020027
SW2 | RESET | SMD-BUTTON(4P-4.0X4.0X1.7MM)-DHT-1152 | SW4-SMD-4.0X4.0X1.7MM | 311020027
SW3 | DIP-SLIDE-SWITCH(3P-11.6X4.0X5.4+2.0MM)-EG1218 | DIP-SLIDE-SWITCH(3P-11.6X4.0X5.4+2.0MM)-EG1218 | SW3-2.5-11.6X4.0X5.4+2.0MM | 311010006
U1 | Z8X180PLCC68-S | Z8X180PLCC68-S | PLCC-S68 | Zilog Z80S180/Z80L180
U2 | AM9511A-1 | AM9511 | DIL24-6
U3 | SN74ABTH245DW | SN74ABTH245DW | SOIC127P1030X265-20N | OCTAL BUS TRANSCEIVERS |  | SN74ABTH245DW | 1739615 | 50R5691 | SOIC-20 | Texas Instruments
U4 | SN74ABT541BDW | SN74ABT541BDW | SOIC127P1030X265-20N | OCTAL BUFFERS/DRIVERS |  | SN74ABT541BDW | 9590170 | 85F222 | SOIC-20 | Texas Instruments
U5 | CJ1117-3.3-1310120P1 | CJ1117-3.3-1310120P1 | SOT89 | 1A Low Dropout Linear Regulator
U7 | SN74LVC1G97DCKR | SN74LVC1G97DCKR | SOT65P210X110-6N | CONFIGURABLE MULTIPLE-FUNCTION GATE |  | SN74LVC1G97DCKR | 1470839 | 32H6376 | SOT-23-6 | Texas Instruments
U21 | MAX6817EUT+T | MAX6817EUT+T | SOT95P280X145-6N | ±15kV ESD-Protected CMOS Switch Debouncers |  | MAX6817EUT+T | 1299771 | 68K9458 | SOT23-6 | Maxim
U22 | TLC7705ID | TLC7705ID | SOIC127P600X175-8N | MICROPOWER SUPPLY VOLTAGE SUPERVISOR |  | TLC7705ID | 8454663 | 35K1226 | SOIC-8 | Texas Instruments
X1 | ASCI0 - USB | USBA-SMD-MALE | USB-A-SMT-MALE | USB Connectors
X2 | USB Programmer | USBA-SMD-MALE | USB-A-SMT-MALE | USB Connectors
X3 | FIDUCIAL_0.6-1.2MM | FIDUCIAL_0.6-1.2MM | FIDUCIAL0.6-1.2
X4 | FIDUCIAL_0.6-1.2MM | FIDUCIAL_0.6-1.2MM | FIDUCIAL0.6-1.2
X5 | FIDUCIAL_0.6-1.2MM | FIDUCIAL_0.6-1.2MM | FIDUCIAL0.6-1.2
X6 | FIDUCIAL_0.6-1.2MM | FIDUCIAL_0.6-1.2MM | FIDUCIAL0.6-1.2
Y1 | 18.432MHZ | DIP-CRYSTAL-25MHZ-20PF-20PPM(HC49US) | HC49US | 306010005 |  | 49S |  |  |  |  |  | 25MHZ

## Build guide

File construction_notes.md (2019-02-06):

# Construction Notes

The best BOM, as in most accurate, is the Digikey Shopping Cart. But this is not so transparent, as the Item numbers don't match the names on the board. Use the Excel version of the BOM for reference, although it has a few extra parts that are unneeded.

To build instructions, this depends on your personal workflow. I have a cheap Chinese SMD oven, so I use this for most of the SMD components. Though, I've found that the RAM, I2C, and FTDI USB component soldering is better done by hand soldering, after the other SMD components are placed and soldered. Then I place the sockets for all of the through-hole components.

Finally, I use a TL866 to program the Lattice GAL devices, and the Flash with the relevant code, and dig into testing.

## Soldering

Also, please note that the soldering for the TSSOP SMD devices is quite hard. I have a bit of trouble with these myself and I still don't have a perfect workflow for getting the RAM and FTDI devices soldered right every time.

If you solder in stages, leaving the FT245, I2C, and 82C55 devices off the bus initially, it is easiest to trouble shoot the board. 9 out of 10 times, it is the RAM device that causes me problems. Either with dry feet, or whisker shorts.

## PCB Version 2.1 (2017)

I found the ESP-01S doesn't need to have a level converter, because it has 5V tolerant I/O. Therefore the expensive level converter component is not needed. The footprint can be repaired by three small cuts, as shown. The Z80 ASCI1 TX line can be bridged with a resistor, between 0 Ohms and 1000 Ohms. I used 220 Ohms. The Z80 ASCI1 RX line can be bridged with a very short piece of wire, as shown.

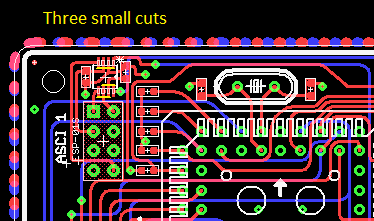
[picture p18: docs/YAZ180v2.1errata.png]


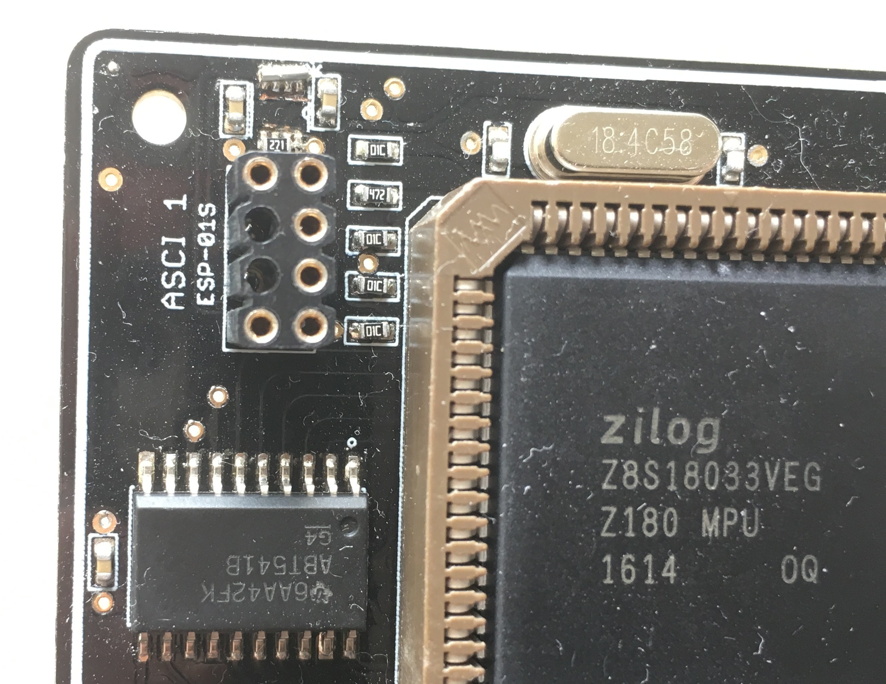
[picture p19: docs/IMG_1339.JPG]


Note that the SST39SF020A 256kB flash device is only supported for 128kB, unless the A17 pin is connected from the Memory GAL to the flash device. This means that `BANK15` is loaded at `0x10000`, rather than at `0x30000` as might be expected. In the default CUPL code `BANK13` and `BANK14` are defined as RAM also because of this issue.

Note that the Am9511A needs to have at least 5 clock cycles under Reset, to initialise itself properly. As the Reset pins on the 74LS93 are controlled by the same Reset as the Am9511A this doesn't happen. The Reset signal needs to be disconnected from the 74LS93, so that the Phi/8 signal can be provided continually to the Am9511A. Use a sharp knife to make a tiny cut to disconnect Pin 2 and 3, which are bridged from the Reset via. Be careful not to cut on the left side of the via, as this is the Reset signal to the Am9511A. The 74LS93 Reset pins should be tied to ground, so that they don't float.

Note to operate the YAZ180 at 36.864MHz, and have the Am9511A work at its preferred frequency, the QD (/16) output of the 74LS93 divider needs to be connected to the Am9511A `CLK` rather than the QC (/8) output. In practice, I just lifted Pin 8 of the 74LS93 off the pad, and soldered a tiny jumper from Pin 11 to Pad 8. There's no problem with just breaking off Pin 8 if it is getting in the way.

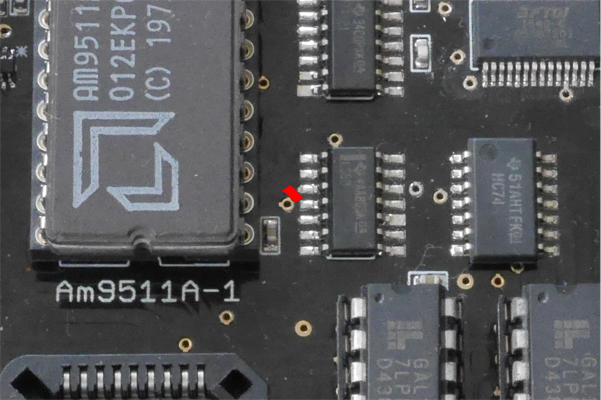
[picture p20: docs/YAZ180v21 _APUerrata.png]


Note that the monostable latch for the Single Step function needs to have input B held high. The B input (Pin 5) should be tied to VCC.

These four images show a Version 2.1 PCB with both APU and Single Step modifications, and ESP-01S modification. The Flash address modification has not been made, and would only be visible on the back side.

<div>
<table style="border: 2px solid #cccccc;">
<tbody>
<tr>
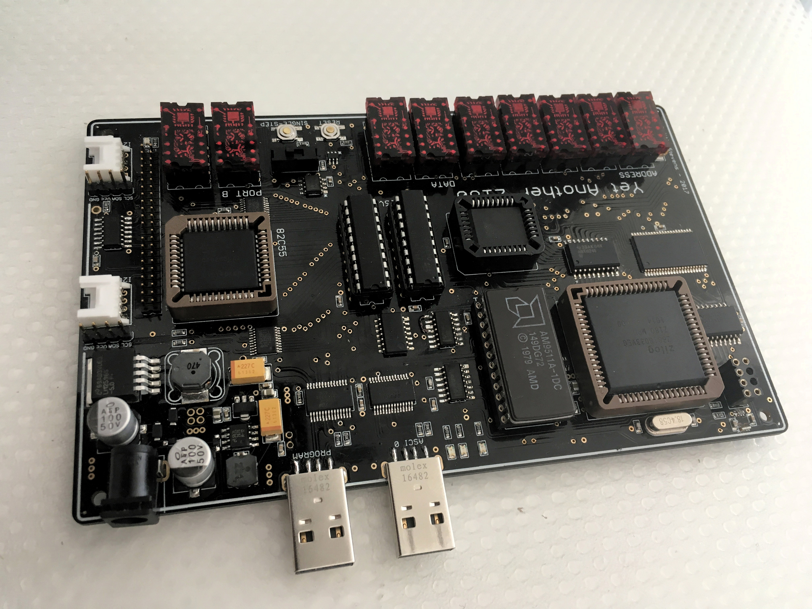
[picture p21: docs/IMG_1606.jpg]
<td style="border: 1px solid #cccccc; padding: 6px;"></td>
</tr>
<tr>
<th style="border: 1px solid #cccccc; padding: 6px;"><centre>YAZ180 Version 2.1 2017 Top Perspective View<center></th>
</tr>
<tr>
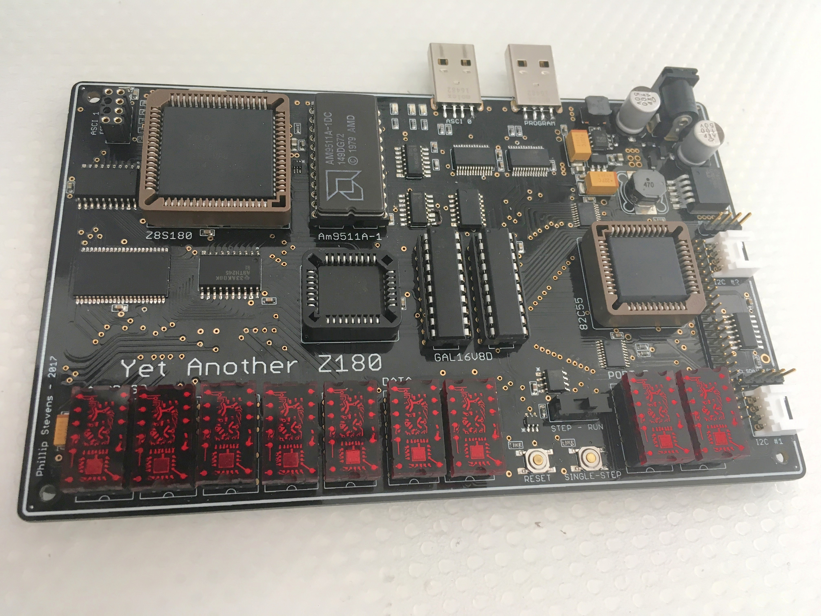
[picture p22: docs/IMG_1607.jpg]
<td style="border: 1px solid #cccccc; padding: 6px;"></td>
</tr>
<tr>
<th style="border: 1px solid #cccccc; padding: 6px;"><centre>YAZ180 Version 2.1 2017 Bottom Perspective View<center></th>
</tr>
<tr>
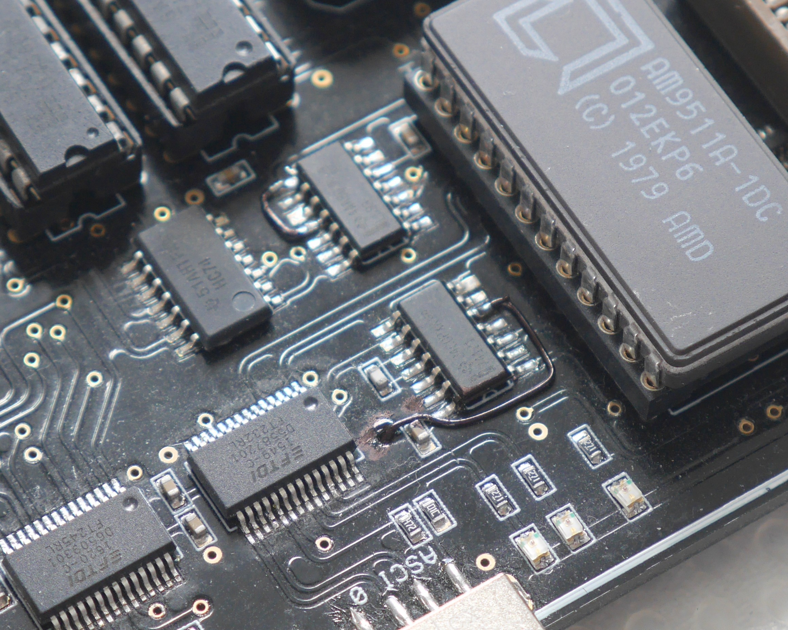
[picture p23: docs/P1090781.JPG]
<td style="border: 1px solid #cccccc; padding: 6px;"></td>
</tr>
<tr>
<th style="border: 1px solid #cccccc; padding: 6px;"><centre>YAZ180 Version 2.1 2017 Top Perspective of Rework<center></th>
</tr>
<tr>
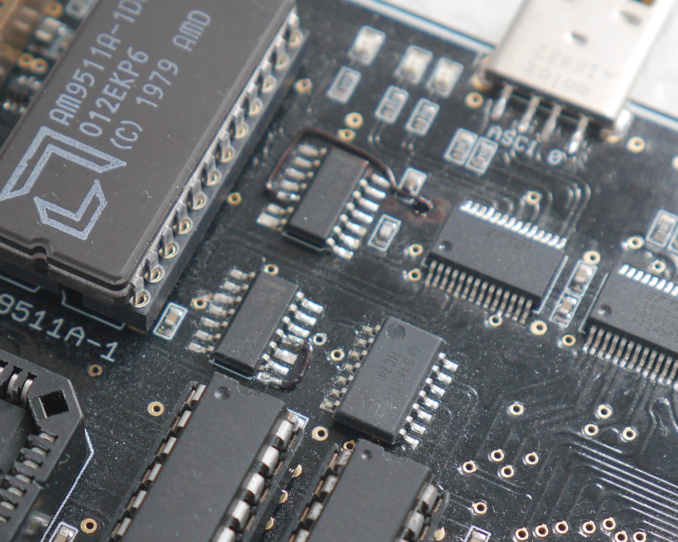
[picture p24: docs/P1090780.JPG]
<td style="border: 1px solid #cccccc; padding: 6px;"></td>
</tr>
<tr>
<th style="border: 1px solid #cccccc; padding: 6px;"><centre>YAZ180 Version 2.1 2017 Bottom Perspective of Rework<center></th>
</tr>
</tbody>
</table>
</div>

## PCB Version 2.2 (2018)

The ESP-01S won't boot with its IO held high. Therefore the two IO pins need to be removed from the connector before it is soldered into the PCB. This modification together with fix for PCB v2.1 (2017) is shown above.

The Am9511A Reset fix above needs to be made.

The Am9511A `CLK` fix above needs to be made too.

The Single Step `B` fix above needs to be made too.

## PCB Version 2.3 (2019)

All of the above errata have been incorporated, and resolution of issue #4 has also been incorporated.
Files for this version have been released in this repository.

Bad order somehow. Dimension information missing from the gerbers.
Version 2.3 gerbers didn't produce working board.

## PCB Version 2.4 (2019)

So Version 2.4 has been revised and is now the basis going forward.
This version  has no errata at 1 February 2019.

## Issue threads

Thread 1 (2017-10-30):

How to use a 17- or 19-pin SRAM chip with YAZ180?

grancier, 2017-10-30:
Hi,

I've decided to build a retrobrew 8-bit computer, and for a variety of reasons (including parts sourcing) I decided to use a Z180 33MHZ MPU (bought on digikey).

Your project is probably one of the best documented and researched DIY 8-bit computers on the internet, especially for the Z-180, so I have been following your schematics very closely.

I'm working in breadboard since soldering such small components would be very time consuming, so most of the components I purchased were in DIP or PLCC formfactor, including SRAM.

I purchased a AS6C1008 1M SRAM chip which has 17 address pins (A0-A16) which leaves 3 pins hanging and I'm not sure how to reconcile them with your schematic. I see that you connected the CPU pins to the SRAM pins in a non-sequential way, using the first 5 CPU pins (A0-A4) at the beginning of SRAM and the next 5 (A5-A9) at the 'end' (mapping to A15-A19 on SRAM) and the next half of the CPU pins mapping to the middle 10 on the SRAM pins in reverse order.

I suppose I could do the same with the 17 pins on the 1mb SRAM chip, having the first 10 cpu pins mapping to the first and last 5 pins on the SRAM, with the remaining 7 CPU pins mapped to the middle SRAM pins in reverse order, but would that work the same way? I guess I would have to update the CUPL code for that to work?

For Glue Logic, I decided to use a CPLD (ATF1508AS 84PLCC) instead of the 2 GALs you use, and I've read I could use that to decode the remaining 3 CPU address pins (A17-A19), but then where would they go out to, would I need a jumper for those pins, or should I use a 3-to-8 decoder, before the pins go into the CPLD?

I'm not trying to build anything fancy, and maybe one day I'll create a PCB for my project, but for now I just want to be able to: program the CPLD, boot a ROM, connect using vterm through usb, and run BASIC on my homebrew computer. I'm sure that could be done even without mapping the CPU pins 1:1 with SRAM, am I right?

Any response would be appreciated. Thanks.

feilipu, 2017-10-31:
> I've decided to build a retrobrew 8-bit computer, and for a variety of reasons (including parts sourcing) I decided to use a Z180 33MHZ MPU (bought on digikey).

Good choice!

> Your project is probably one of the best documented and researched DIY 8-bit computers on the internet, especially for the Z-180, so I have been following your schematics very closely.

Thanks. Much appreciated.
Its probably because I have a tendency to forget things, unless I write them down.

> I'm working in breadboard since soldering such small components would be very time consuming, so most of the components I purchased were in DIP or PLCC formfactor, including SRAM.

> I purchased a AS6C1008 1M SRAM chip which has 17 address pins (A0-A16) which leaves 3 pins hanging and I'm not sure how to reconcile them with your schematic.

That gives you 128kB of RAM. I would just connect the address pins to the Z180 sequentially, starting at the lowest address. You'll need to manage the RAM /CS pin to separate the use of RAM and Flash using the CPLD programming later.

> I see that you connected the CPU pins to the SRAM pins in a non-sequential way, using the first 5 CPU pins (A0-A4) at the beginning of SRAM and the next 5 (A5-A9) at the 'end' (mapping to A15-A19 on SRAM) and the next half of the CPU pins mapping to the middle 10 on the SRAM pins in reverse order.

That was just convenience. I was plagued by the non sequential ordering of the Address pins on the Z180, which meant that my layout on the PCB was complicated and not working. I wasted a week trying to lay them out cleanly. One morning, I woke up with the revelation that it since it was __RAM__, the addressing can actually be  __random__ and it doesn't matter. Hence the seemingly random connection of the address lines to the RAM chip. All that matters is that for a _unique_ address, you get back _unique_ data. You could also connect the data lines randomly too, but that wasn't helpful for my layout.

> I suppose I could do the same with the 17 pins on the 1mb SRAM chip, having the first 10 cpu pins mapping to the first and last 5 pins on the SRAM, with the remaining 7 CPU pins mapped to the middle SRAM pins in reverse order, but would that work the same way? I guess I would have to update the CUPL code for that to work?

If you're not trying to lay out a PCB, don't worry. Just connect it sequentially, starting from A0.

> For Glue Logic, I decided to use a CPLD (ATF1508AS 84PLCC) instead of the 2 GALs you use, and I've read I could use that to decode the remaining 3 CPU address pins (A17-A19), but then where would they go out to, would I need a jumper for those pins, or should I use a 3-to-8 decoder, before the pins go into the CPLD?

I had trouble programming ATF16V8 PLCC with the TL-866 programmer. Basically, I couldn't get it to work. Hence I tried with Lattice GALs, and that worked. The GALs are more _retro_, but they're more power hungry too. YMMV, on the ATF1508 PLCC. I've no experience to contribute, sorry.

Push as many address pins as you can into the PLCC. That will allow you the most flexibility in doing /CS decisions, and make life easier in the future. IMHO, CUPL is such a nice way to describe the hardware it makes sense to use it where you can. Using the EPLD and CUPL saved me at least 2 board revisions when I was first bringing up the YAZ180.

> I'm not trying to build anything fancy, and maybe one day I'll create a PCB for my project, but for now I just want to be able to: program the CPLD, boot a ROM, connect using vterm through usb, and run BASIC on my homebrew computer. I'm sure that could be done even without mapping the CPU pins 1:1 with SRAM, am I right?

You will need to map the CPU and SRAM 1:1, otherwise nothing will work. The Z180 increments its program counter by one for each instruction it retrieves, so it needs to have the low address lines connected 1:1.

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

And, if you're interested, the third iteration of the YAZ180 PCB is now finished and I'm building the first systems up now. I'll put a direct link to [Tindie](https://www.tindie.com/stores/feilipu/) for them here, once I'm satisfied they're working correctly.

Thanks again for the questions.

grancier, 2018-12-11:
Just as an addendum for those interested in Z180 memory mapping, I was able to use "partial" decoding for the memory map in my design. I used 74HC logic gates instead of a CPLD since the learning curve for programming a CPLD is non-trivial, whereas using TTL logic is just a matter of connecting the appropriate pins to each other.

My memory map has 48K ROM from 0x00000 to 0x0BFFF then 16K RAM from 0x0C000 to 0x0FFFF,  Crucially this means you have RAM in the first 64K of physical address space for stack space whereas if you only used A19, you would not have RAM until physical address 0x80000 and then setting up a stack becomes a harder programming problem. RAM is then continuous until 0x8BFFF then followed by ROM until 0xFFFFF. Since the Z180 does not use the 20-bit address space in a linear manner, meaning it doesn't "see" memory over 64K on reset, it helps to have RAM in those 1st 64K.

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

Closed 2017-11-02.

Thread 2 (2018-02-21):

Questions about how the Z180 MMU works

mosespray, 2018-02-21:
(https://github.com/feilipu/yaz180/files/1742861/yaz180.Memory.Map.-.Sheet1.pdf)
In the first blog post you describe your memory map design, but it is prefaced with a statement about how it all changed.  I transcribed the memory map from your blog (OLD WAY) and then from your PLD code (NEW WAY).  Can you elaborate on how the new scheme works?  Specifically, how does it flow?  When the Z180 boots, it starts at 0000H.  So, that would mean that it starts reading the yazbios at the beginning of the FLASH chip.  Then what happens?  Does it start banking the banks (1-13) in and out?  Would it be possible to just design it such that upon reset, it reads the bios from 0000H from the FLASH, but then perform a chip select with a 74LS138 to restore the entire 1MB SRAM?  I would rather have the physical be all in COMMON1, but I read somewhere that the Z180 can't deal with it being linear.

[yaz180 Memory Map - Sheet1.pdf]

Best,
Dave

feilipu, 2018-02-21:
There are quite a few good references to how the Z180 MMU works. I've listed a few at the bottom. I read each of them at least 10 times, and the data sheets many times too, but I still didn't understand until I had to actually write code.

The flow I'm describing is specific to both hardware and software (and also firmware in the EPLD for that matter), so it is completely configurable by anyone using the YAZ180 to bend to their own ends. But for discussion, here's my current view.

### Physical Addressing
The Z180 has 20 address lines and _through the MMU_ has 1MByte of physical address space. I have connected both a 1MByte SRAM and a 128kB/256kB/512kB Flash device to these address lines, in the normal way (excepting the comments on RAM in #3). This means that for a significant proportion of the physical address space there are two devices available.

The `/CE` or `/OE` pins of the RAM and Flash devices are controlled by the EPLD code, and in this way we only enable __ONE__ of the two devices for each physical address. In programming mode this control issue is compounded by needing to allow a physical address space for fake USB provided memory, but let's ignore that for now.

The current (and final, IMHO) physical assignment is RAM from `0x0C000` up to the lower limit of the Flash, and Flash from `0xFFFFF` down to its full capacity, less the first 64kBytes, 48kBytes of which appear in the first page from `0x00000` to `0x0BFFF`.

For example, for a 128kB Flash device, the lower page boundary is at `0xF0000`. For a 256kB Flash device it is at `0xD0000`. Note that these descriptions of "pages" are purely arbitrary, and are only relevant because the Z80 thinks in 64kByte chunks, so it is easiest to think in the same way.

### Logical Addressing
I've learned quite a bit since I started this project, and my ideas around how to manage the logical address space have matured substantially, I believe.

It is important to note that the Z180 is just a Z80 with a MMU. A Z80 only supports 64kByte of logical address space. The MMU is responsible for mapping segments of the physical address space into the Z80 logical address space. Compared to later x86 MMUs, the Z180 MMU is very simple and limited.

Initially I had the idea of trying to maintain a small `CA0` address space for the "Page 0" vectors and a global stack at the bottom of the logical address space, and use the `BANK` and `CA1` logical address spaces to allow reference to the parts of the physical address space as needed. I was trying to keep things simple, but this was naive.

The yabios now uses just two logical address spaces, `BANK` and `CA1`, with the `CA1` being as small as possible at the top of the logical address space. Currently this is `0xF000` to `0xFFFF`, and it looks as if this provides enough space for both interrupt code that must run irrespective of which bank of logical memory is configured in the `BANK` address space, and for buffers for I/O for the serial ports, and the Am9511A APU.

When the Z180 initially starts up, the MMU registers set the logical address space to match the first 64kBytes of the physical address space. That is why the physical address space needs to have some Flash in the lowest page (or 64kBytes), starting from `0x0000` logically and `0x00000` physically.

The first thing I do is to create the [split between `BANK` and `CA1`](https://github.com/z88dk/z88dk/blob/master/libsrc/_DEVELOPMENT/target/yaz180/crt_preamble.asm#L32) areas. Then the physical starting addresses for the two logical address spaces are set. Now we have a fixed RAM in `CA1` which is both logically and physically at `0x0F000` to `0x0FFFF`, and a banked logical address space from `0x0000` to `0xEFFF`, and depending on the [setting of the `BBR`](https://github.com/z88dk/z88dk/blob/master/libsrc/_DEVELOPMENT/target/yaz180/crt_preamble.asm#L38) can be any part of the physical address space.

__FOR CONVENIENCE__ I always ensure that the `BBR` setting is on a 64kByte page boundary. Doing this wastes RAM / Flash because the memory in every page from `0xnF000` through to `0xnFFFF` is always masked by the RAM maintained in `CA1` in `0x0F000` to `0x0FFFF`.

When doing a bank swap with this memory layout requires the programmer to think about both the contents of the "Page 0", and the location of the current stack.

The "Page 0" in Z80 is the 256 bytes at the bottom of the address space from `0x0000` through to `0x0100` (although in reality only up to `0x0068` is really necessary, it is convenient to think in terms of pages). The "Page 0" contains the interrupt vectors and these must always remain valid, if you want your Z80 processor to keep working. In the Z180 with the ability to change the "Page 0" contents by remapping the logical address space, it is essential to ensure the new or incoming ["Page 0" is created correctly](https://github.com/feilipu/yaz180/blob/master/yabios/main.c#L310) before doing a bank swap.

Also, when doing a bank swap the stack pointer `SP` needs to be managed. If the `SP` points to the wrong physical address location or has the wrong contents, because you changed the logical address map, then things go bad quickly.

That is why I've implemented a [location in "Page 0" of each bank to store the contents of the `SP`](https://github.com/z88dk/z88dk/blob/master/libsrc/_DEVELOPMENT/target/yaz180/driver/yabios/asm_common1_data.asm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) when the bank is changed. The lowest page of memory where the yabios is maintained has a system stack, and I maintain a the contents of the [system stack pointer in a different location in `CA1` memory](https://github.com/z88dk/z88dk/blob/master/libsrc/_DEVELOPMENT/target/yaz180/driver/yabios/asm_common1_data.asm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), so it is available to each bank's code to push things onto the system stack if they need to. Note that these locations are NOT the `SP`. They are locations provided to store the contents of the `SP` when that bank is NOT active. The [mechanism is shown in the `_call_far` function](https://github.com/z88dk/z88dk/blob/master/libsrc/_DEVELOPMENT/target/yaz180/driver/yabios/asm_common1_driver.asm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), and in the [`_system_rst` function](https://github.com/z88dk/z88dk/blob/master/libsrc/_DEVELOPMENT/target/yaz180/driver/yabios/asm_common1_driver.asm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).

### DMAC
Note that both of the the Z180 DMA Controllers don't care about the logical address space. They are programmed based on the physical address space. That is why it is convenient to maintain the 64kByte mapping for the `BBR`, to allow simple creation of 20 bit addresses for the DMAC simply [by bit shifting the `BBR` value](https://github.com/z88dk/z88dk/blob/master/libsrc/_DEVELOPMENT/target/yaz180/driver/yabios/asm_common1_driver.asm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).

Also, using the DMAC we can recover the RAM or flash hidden by the `CA1` logical address mapping by copying to and from the masked physical addresses, if there is a need for an application to use that extra 4kByte per page. So far I've not had a need to do this, but the [`_memcpy_far` function](https://github.com/z88dk/z88dk/blob/master/libsrc/_DEVELOPMENT/target/yaz180/driver/yabios/asm_common1_driver.asm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) already supports this capability.

### References
[The Ganssle Group - Z180 Memory Management](http://www.ganssle.com/articles/ammu.htm)
[Z180 FAQ](https://www-users.cs.york.ac.uk/~pcc/Circuits/64180/docs/z180faq.pdf)

mosespray, 2018-02-22:
Thank you for the quick and thorough responses.  In my quest to understand how the Z180 works, I encountered and read/re-read both of those references many times.  However, with the added explanations above, which are excellent, btw, I will read them again with them in mind.  I feel a lot better knowing that you had to read the docs over and over.  I really appreciate that you are so helpful and share your knowledge and designs.

Closed 2018-02-22.

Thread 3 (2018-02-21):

More design questions

mosespray, 2018-02-21:
I am curious as to why you set BUSRQ to VCC and leave BUSAK unconnected.  Is it because you are the only only using the bus (i.e. there aren't io cards to compete with)?

On page one of the schema, why do you connect ADDR10 - ADDR19 to A14 - A5 and ADDR5 - ADDR9 to A19 - A15?

feilipu, 2018-02-21:
> I am curious as to why you set BUSRQ to VCC and leave BUSAK unconnected. Is it because you are the only only using the bus (i.e. there aren't io cards to compete with)?

I made the decision early on in my design to make the YAZ180 a "Single Board Computer". This was because I didn't fully understand the transmission line theory which can result in issues when you try to run high speed signals through connectors and over longer distances with taps and open stubs.

Because the YAZ180 is a SBC, I was therefore aware that nothing on my board would need to control the bus, and therefore the `/BUSREQ` and `/BUSACK` signals were unnecessary. The `/BUSREQ` signal needs to be tied high as it is an active low signal. Active low is the normal case with most of the Z80 (Z180) control signals.

Later, I added the 82C55 PIO device to allow interfacing and expansion off the board. The three 8 bit ports of the 82C55 device are organised to look like an IDE interface, but really this is just for convenience. An IDE cable and connectors makes a very neat and cheap physical interface for system expansion.

> On page one of the schema, why do you connect ADDR10 - ADDR19 to A14 - A5 and ADDR5 - ADDR9 to A19 - A15?

The SRAM device is very compact, and is a SMD. I had quite a bit of difficulty organising the signal flow for the address and data lines to appear in the correct order at the SRAM device, because the pin-out of the Z8S180 PLCC seems to be strange.

After quite a bit of hand-wringing and sleepless nights, I realised that RAM is an acronym for "Random Access Memory", and so it really doesn't make any difference in which order the address lines are connected, provided that for each address a unique byte of data is stored or retrieved.

This comment in my hardware design notes...

"Getting 20 address lines and 8 data lines to appear on the SMD SRAM memory is challenging. I will probably reassign the address lines to suit the Z8S180 pin-out, rather than spending hours untangling the lines. It won’t be too easy to do this with the Flash device, but as it is in a PLCC through-hole socket it comes inherently with “vias” making reaching it half as hard as the SMD device."

In the end I got the address and data lines to "flow" nicely around the board with very few vias, as this screenshot shows.

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

mosespray, 2018-02-22:
Both answers make perfect sense.  Thanks!!

Closed 2018-02-22.

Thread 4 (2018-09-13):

Board Assembly Drawing - discussion

fitzfish, 2018-09-13:
Hello feilipu,

It would be very helpful if you could generate a pdf or png file of the assembly drawing from the PCB design tool you use for your PCB v2.2. If this is not clear, I am speaking of a picture with the board outline, pads, silkscreen outlines and reference designators visible to aid in correctly locating the component locations during assembly for those small components that do not have a reference designator visible on the final boards. I do not have your PCB tool and therefore cannot generate the view.

As an example, you generated this for V2 here: https://feilipu.me/2017/02/26/yet-another-z180-v2/names/#main

Thank you again and best regards,
Dave

feilipu, 2018-09-14:
Sorry for the oversight. This was something that I thought I had done some time ago, and yet it was not done. I have added the [Values and Names](https://github.com/feilipu/yaz180/commit/d36a0f9c51e5b9f19539bef81534c498ae4ce55f) PDFs for both V22 and V21. I hope that is useful.

Also, I added a [small update into the construction notes](https://github.com/feilipu/yaz180/commit/ddfe1b934e9c4ec652cbaee51bc79c4be4d3b8ea) about running the YAZ180 at 36.864MHz, and the timing for the Am9511A. Essentially a small jumper from Pad 11 to Pad 8 is needed so that the Am9511A `CLK` is driven at 1/16 of PHI, rather than 1/8 of PHI. The code changes have already been made.

I'll leave this issue open, and if there's anything else I can help with, just let me know.
Phillip

fitzfish, 2018-09-19:
I had similar problems with that part specifically, but also others to a lesser extent. On the ram - the circuit board as delivered does not include solder mask between the pads. This makes it virtually certain that solder bridging will occur during assembly. You could reduce the pad width a few mil to ensure the PCB vendor can adequately screen soldermask in there if you ever have to revise the board in the future. De-solder braid is my friend...

Overall a very nice layout and the assembly drawing has helped immensely. Thank you!

Remaining parts are on the truck for delivery today.
Best regards,
Dave

fitzfish, 2018-09-25:
Phillip,

Assembly complete and in testing. One has a short on 5V that I am still chasing. Noting obvious visible so am looking over once again.

The second board is powering up. I have found a couple of issues that was preventing it from coming out of reset and assume this is a good place to bring them up -

1. There is on open input on IC8 pin 5. Needs to be pulled up or will prevent coming out of reset (at least on the hardware build here).
2. I do not yet have an APU. The PAUSE signal is un-terminated when no APU installed which prevents the system from coming out of reset A 10k pull up to 5V under the 16V8 fixed this.
3. One final issue comes from the FT485. /RXE powers up low while RD and USB_CS power up high, causing Wait to be asserted from IC6. Not sure if this is a logic issue or something else. Applying 5V to the USB connector for that channel briefly brings the FT485 out of reset long enough for that signal to clear.

The board now comes out of reset and I can see the address display scrolling along. I have attempted to connect to a terminal to see if anything is talking with both the CPM and standard implementations for the BIOS and have gotten no further. Time to dig deeper into the BIOS for insight into the terminal settings. Any help there is appreciated to kick start progress! My desire is to run the test utilities you created next!

I hope the feedback helps and please know that I appreciate you blazing the trail for us here who wish to follow!

Best regards,
Dave

feilipu, 2018-09-25:
Dave,

thanks for the inputs.

The PCB doesn't have solder mask on the RAM, but it was ordered with "Solder Dam". I think the purpose of this solder dam is to reduce the chances of flow between the pads. Still, I find it ineffective.

The only way I can get the RAM to solder correctly is to wet the pads before the oven (with no device), and then later clean and re-tin them with fine tipped solder iron. Then lay the RAM device and hold it down, solder the diagonals, then solder the rest pressing on each pin with fine tweezers to hold it until solder hardens. Quite slow, and there must be a better way.

> There is on open input on IC8 pin 5. Needs to be pulled up or will prevent coming out of reset (at least on the hardware build here).

Noted. I'll fix this for the next iteration.

> I do not yet have an APU. The PAUSE signal is un-terminated when no APU installed which prevents the system from coming out of reset A 10k pull up to 5V under the 16V8 fixed this.

Hmm. The GAL devices are supposed to have active pull ups on all input pins. At least that is what is advertised. Although they also recommend terminating inputs, so adding a pull up resistor is a good idea.

> One final issue comes from the FT485. `/RXE` powers up low while `/RD` and `USB_CS` power up high, causing Wait to be asserted from IC6. Not sure if this is a logic issue or something else. Applying 5V to the USB connector for that channel briefly brings the FT485 out of reset long enough for that signal to clear.

I think all the points above are probably fixed once powered up. Everything works following a clean, powered up, `RESET` signal, which will also reset the GAL and USB devices. I find my YAZ180 boards won't run from power on, and some of above is probably the reason why this is the case.

Let me know if you can get yours working from power up without a press on the `RESET` button, please.

Phillip

fitzfish, 2018-09-30:
Hi Phillip,

>

feilipu, 2018-11-20:
I've just finished a [V2.3 of the YAZ180](https://github.com/feilipu/yaz180/tree/master/pcb/V23_20181120), and I'll start building it up over the holiday season for 2019.

It incorporates your fix as per below, plus all the other issues identified in the [construction notes](https://github.com/feilipu/yaz180/blob/master/construction_notes.md). Thanks again for debugging this issue. The resolution was not obvious.

> I added a 1N4148 diode to create an OR for the reset signal to the FT245R. The anode connects to Pin 1 of U6. This is the active high system `RESET`. The cathode connects to the `/FTDI1_RESET` at the junction of R11 and R14. Using the active high reset signal allows the FT245R chip to come out of reset just long enough for `/RXE` to go inactive. Once system reset returns inactive then the FT245R is held in reset until connected to an external USB port, and the board is not longer held in wait.

I elected not to add the resistor for the `PAUSE` line, as in the case where the APU is not equipped a through hole resistor can be added to the relevant holes. So, it is not really necessary.

I'm planning to build up a few boards and then see whether they sell.
If they do, then I'll keep building them in any spare time.

feilipu, 2019-02-05:
For some reason the Gerber dimension information was not respected in the V2.3 PCBs, and also I couldn't get the build on the (incorrectly sized) PCB to work. So, I revised to make a V2.4 PCB.

The V2.4 PCBs (there are only 5 currently) have all been built and are working. Once I'm 100% satisfied with the testing, then I'll sell them on Tindie, and also order some more raw PCBs.

So, I'll close this issue now. Thanks again for helping to make the YAZ180 better.

Closed 2019-02-05.

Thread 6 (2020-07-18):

CJ1117-3.3 not availabe

ProstetnikJeltz, 2020-07-18:
Hello,

the LDO CJ1117-3.3 is not available (even not at digikey), when trying to order from Germany - there are some retailers in China (but not at Aliexpress).
I searched all my sources but weren't able to get this LDO (Digikey, Mouser, RS-Components, Ebay, Aliexpress, Banggood ... ).
The problem is, that it is SOT-89-3 and not SOT-223, which is easy to find.
There are also no cross references available, because all other LDOs have Vin and Vout vice versa.
My solution by now is, to mount an SOT-223 AMS1117-3.3 in vertical position and hope, it won't get too hot, because the "heat spreader" is not soldered to the PCB.

Second problem is, that the footprints for the Diodes D2 and D4 (SOD-idontknow) differ from D1 and D3 (SOD-323).
So D2 and D4 don't fit to the PCB - I "wire wrapped" them, but this is a quite dirty solution for switching diodes ;) .

The PCB used, is the latest in folder "V24_20190107".

This is not a cpomplaint but a suggestion for further planning.
I really appreciate you work and look forward, when my YAZ180 sees the "first light".

Greetings from Munich
Uli

feilipu, 2020-07-19:
>  mount an SOT-223 AMS1117-3.3 in vertical position and hope, it won't get too hot.
You'll be fine. There is only the I2C chips and the ESP8266 on the 3V line.

It is unfortunate that I used that layout. It was only because I had a bunch of them handy from a prior project, and wanted to reuse them.

> Diodes D2 and D4 (SOD-idontknow) differ from D1 and D3 (SOD-323).

Yes. this is still an issue. I try to use "bigger" 2A diodes for the 5V circuit, and they don't quite fit on the pads correctly. I couldn't find an Eagle diode of appropriate size, so the diodes hand over the silkscreen slightly. That makes them hard to solder, unless you use paste.

I've not revised the PCB from the latest 2019 one, which you have. Been distracted by some software projects for the past months. I've been thinking about another version, but anything else I can think of right now would look a lot like the SC131 (and that's been done). [Here's some blinking lights for inspiration](https://youtu.be/CFe9-Dl6wxA). Good luck with your build, Uli.

ProstetnikJeltz, 2020-07-19:
Hello Philip,

thank you for your reply.
I‘ll try to mount the two diodes vertically and use a short wire for connecting to kathode/ground.
I just thought, fi you plan to relesa another PCB … 😉 .
The AMS1117 should do it, if not, I’ll solder a small piece of copper to the heatspreader.
Just waiting for the debouncer and the switching regulator, the it will run ( I hope so).
I also have several SC126 running, but the YAZ is quite more sophisticated 😊 .

To find smaller diodes for 2A is very hard, I tried to after I discovered the mounting problems.
But I keep on searching and if I find one that fits, I‘ll tell you.

I’m working at BMW as Testengineer and we have some very useful collections of SMDs, maybe searching there gets a hit 😉 .

Greetings form Munich and stay healthy

Uli

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

Closed 2020-07-28.

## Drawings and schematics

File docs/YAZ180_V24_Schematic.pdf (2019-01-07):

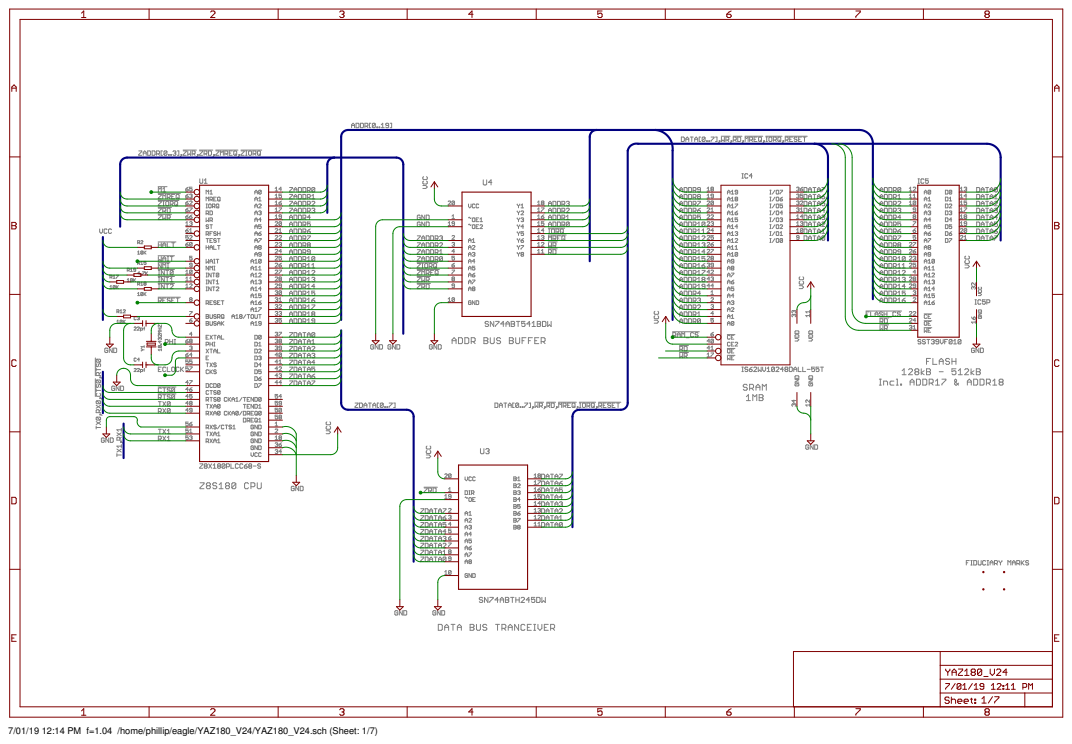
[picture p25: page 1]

7/01/19 12:14 PM f=1.04 /home/phillip/eagle/YAZ180_V24/YAZ180_V24.sch (Sheet: 1/7)

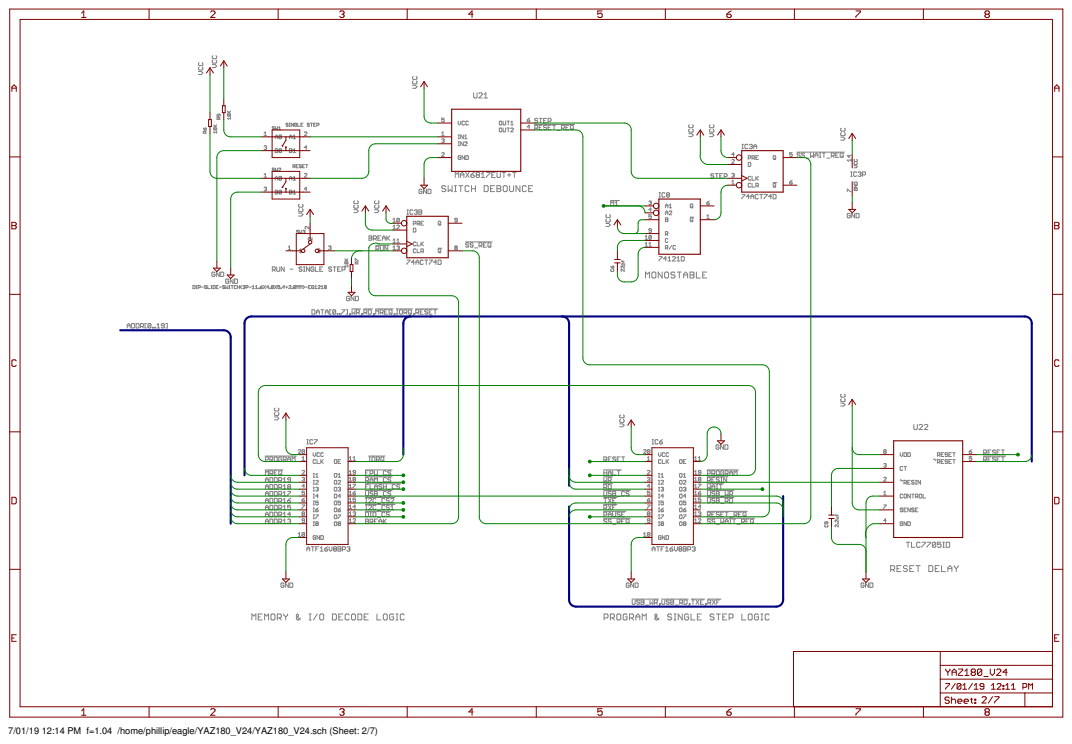
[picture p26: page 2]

7/01/19 12:14 PM f=1.04 /home/phillip/eagle/YAZ180_V24/YAZ180_V24.sch (Sheet: 2/7)

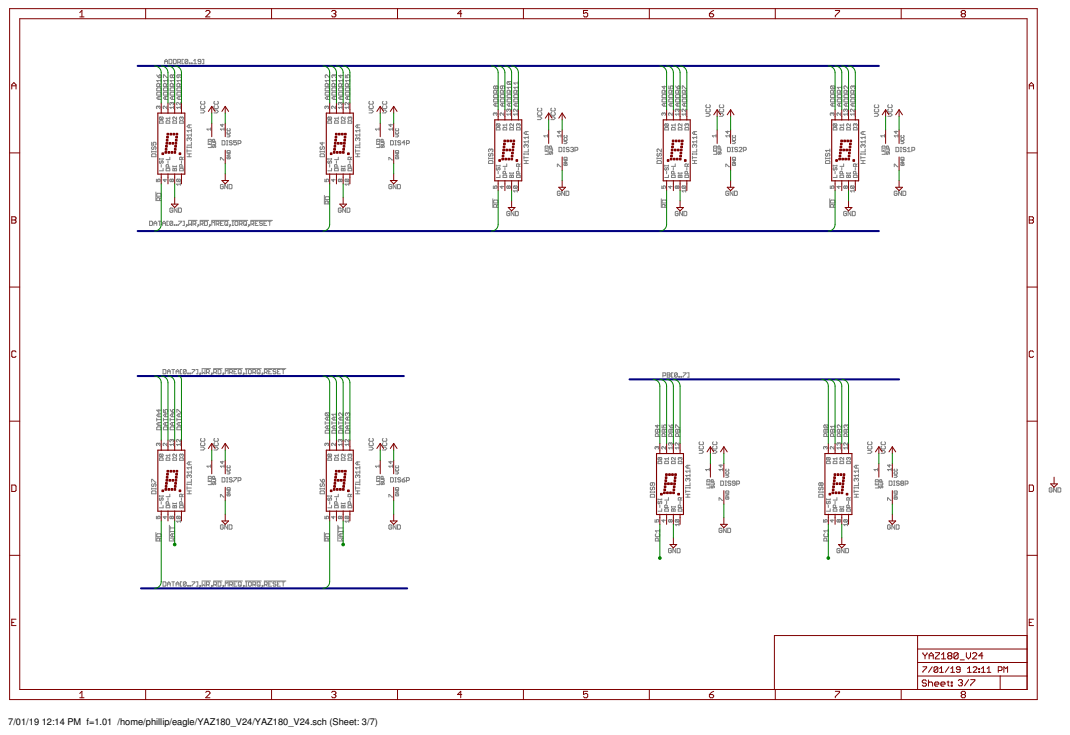
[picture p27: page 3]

7/01/19 12:14 PM f=1.01 /home/phillip/eagle/YAZ180_V24/YAZ180_V24.sch (Sheet: 3/7)

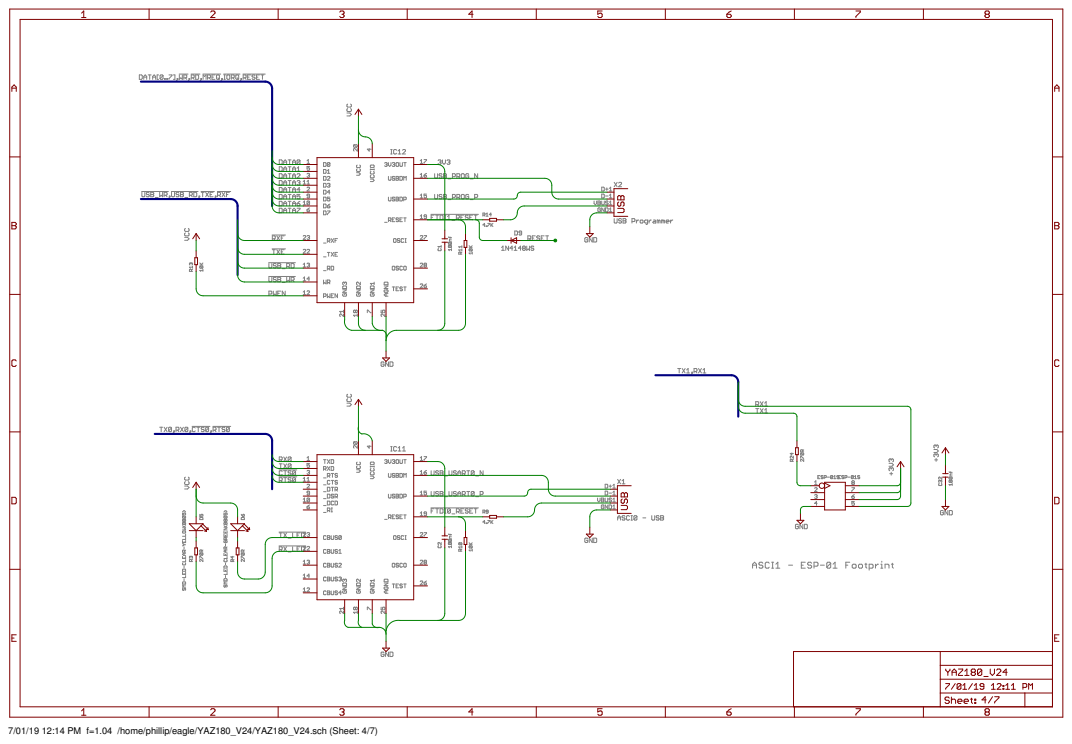
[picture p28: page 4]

7/01/19 12:14 PM f=1.04 /home/phillip/eagle/YAZ180_V24/YAZ180_V24.sch (Sheet: 4/7)

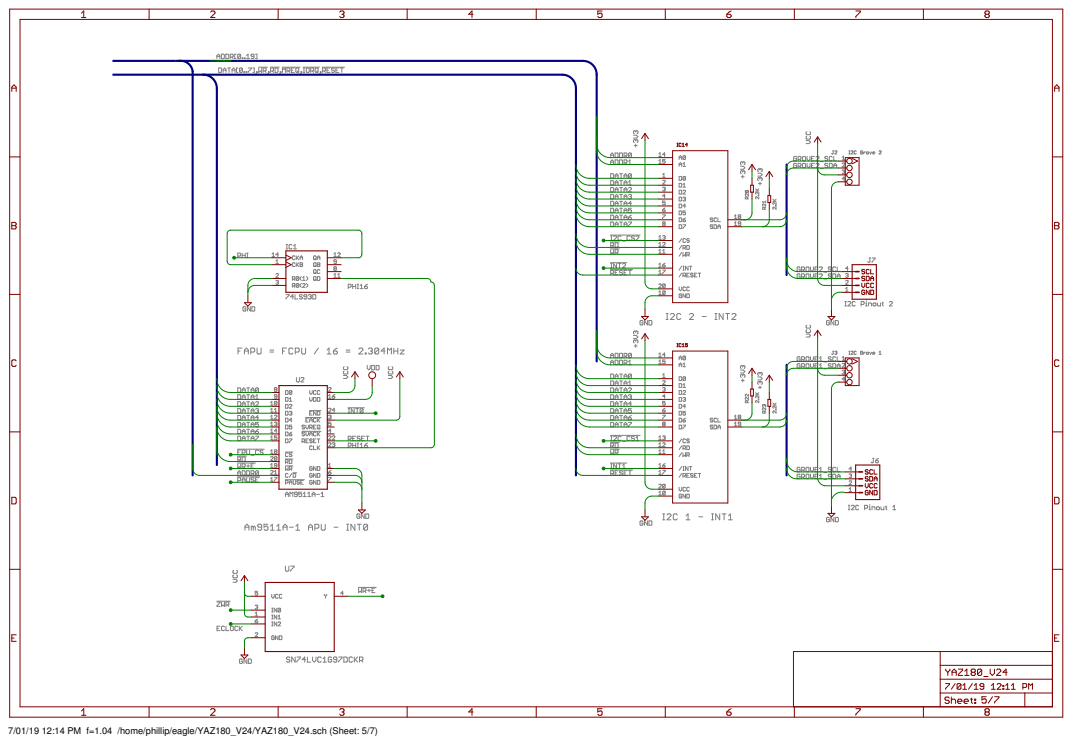
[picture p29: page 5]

7/01/19 12:14 PM f=1.04 /home/phillip/eagle/YAZ180_V24/YAZ180_V24.sch (Sheet: 5/7)

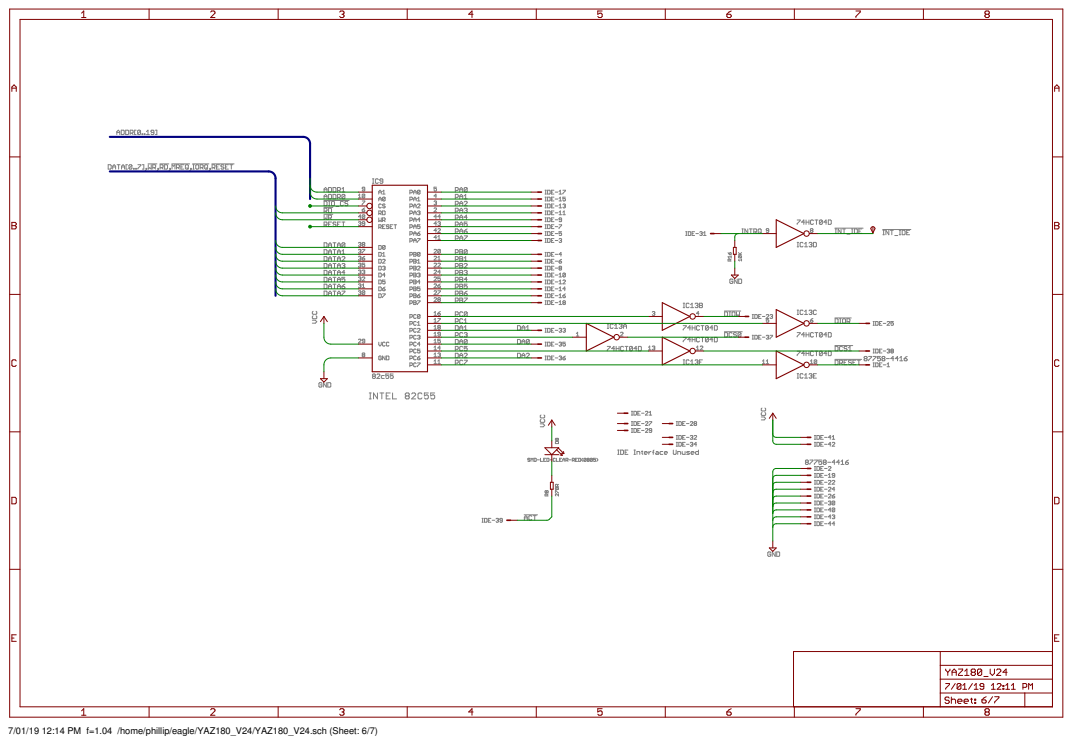
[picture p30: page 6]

7/01/19 12:14 PM f=1.04 /home/phillip/eagle/YAZ180_V24/YAZ180_V24.sch (Sheet: 6/7)

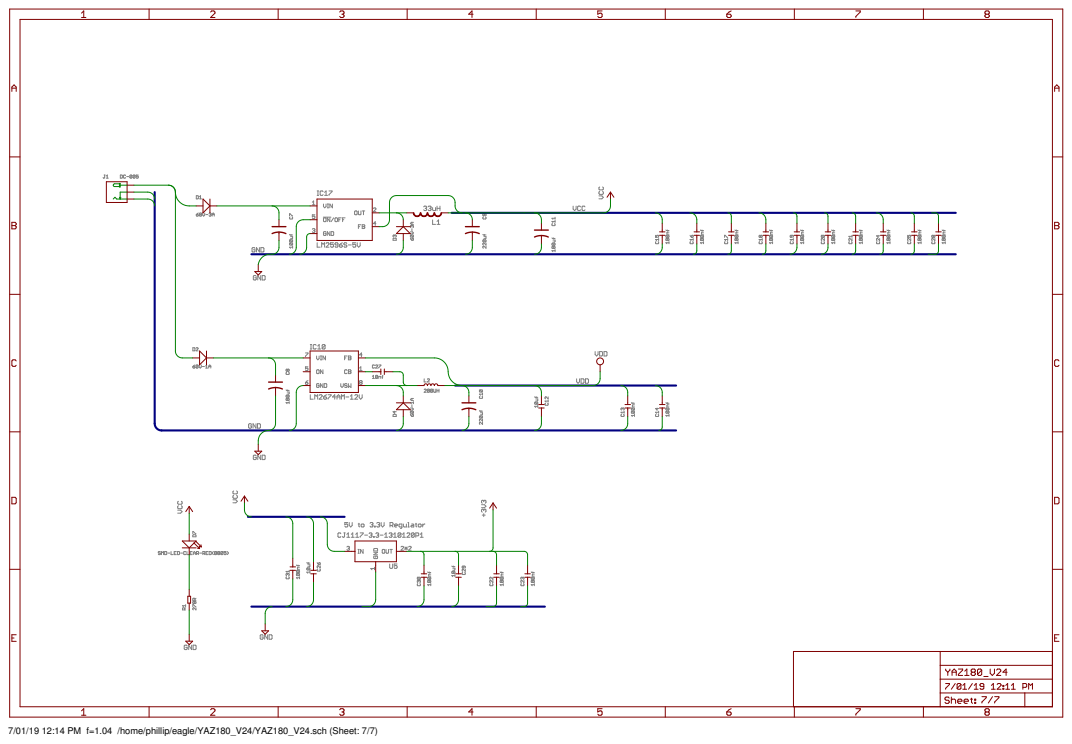
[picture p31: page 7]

7/01/19 12:14 PM f=1.04 /home/phillip/eagle/YAZ180_V24/YAZ180_V24.sch (Sheet: 7/7)

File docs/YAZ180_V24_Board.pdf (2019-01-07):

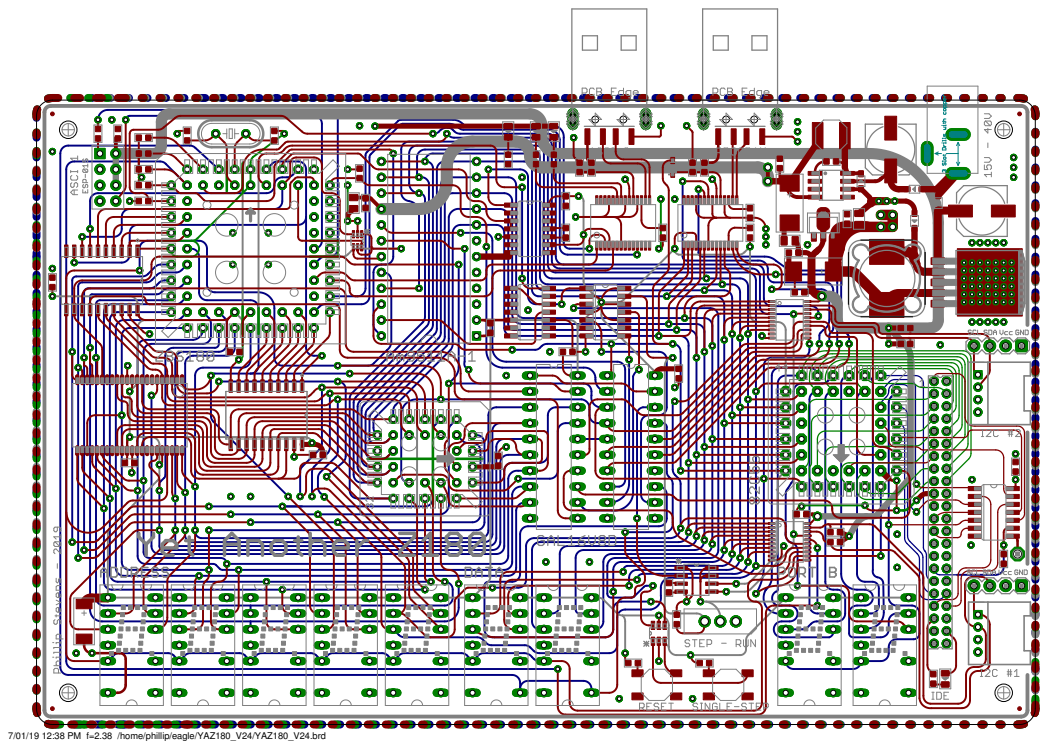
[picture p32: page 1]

7/01/19 12:38 PM f=2.38 /home/phillip/eagle/YAZ180_V24/YAZ180_V24.brd

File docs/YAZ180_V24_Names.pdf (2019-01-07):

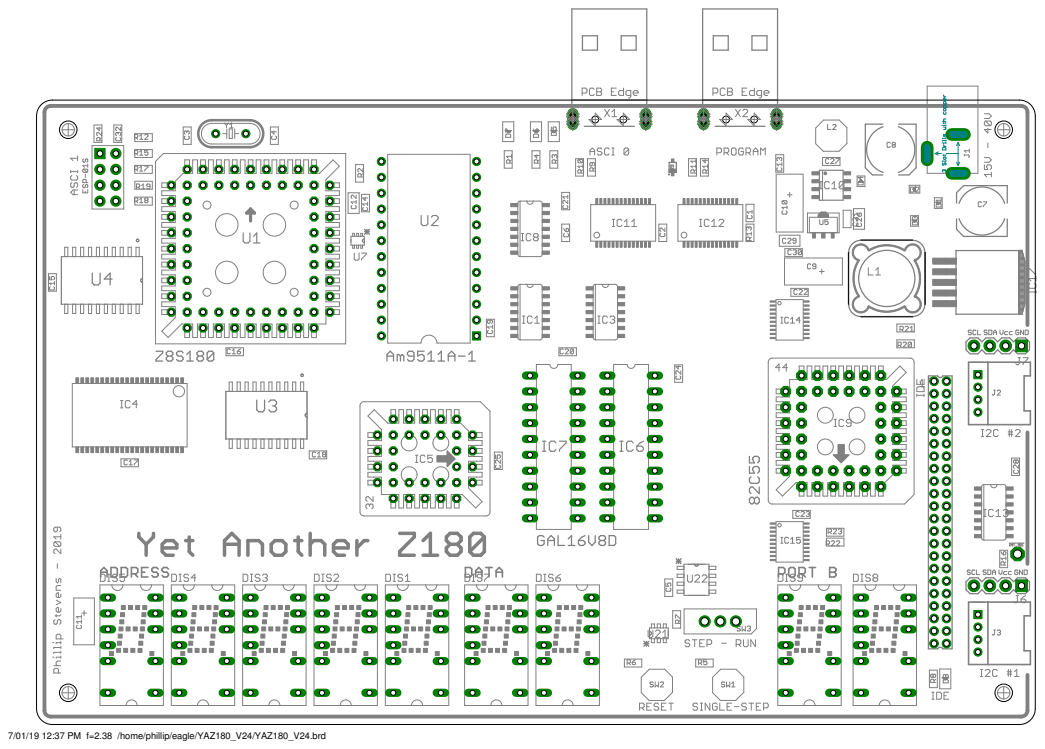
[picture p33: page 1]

7/01/19 12:37 PM f=2.38 /home/phillip/eagle/YAZ180_V24/YAZ180_V24.brd

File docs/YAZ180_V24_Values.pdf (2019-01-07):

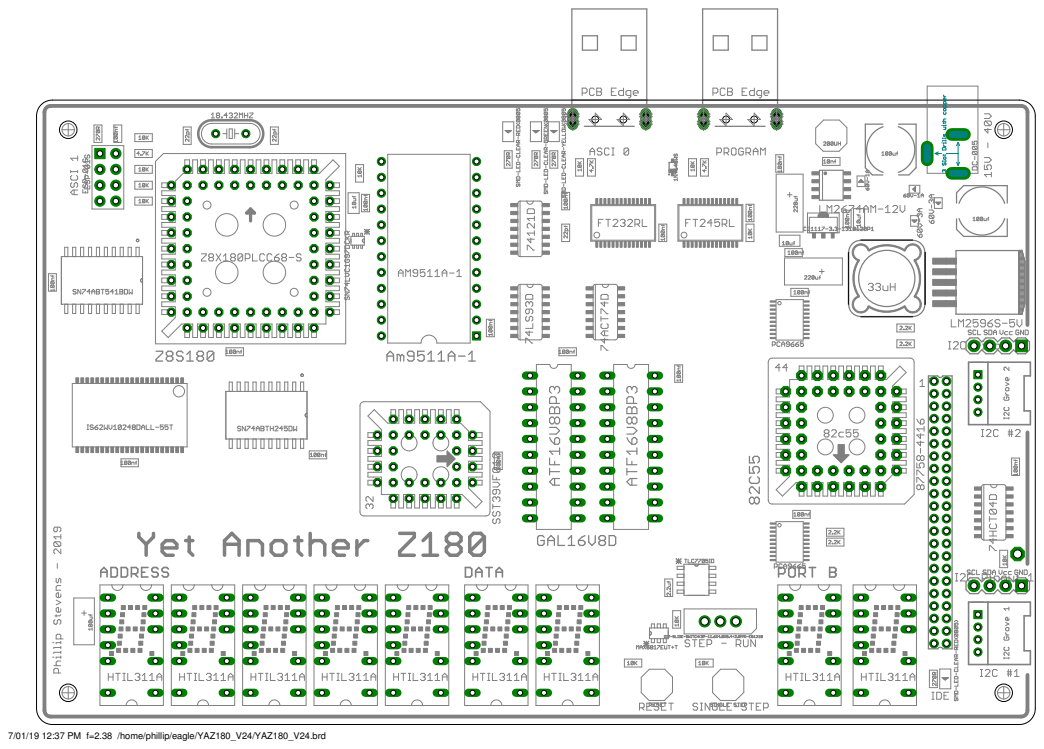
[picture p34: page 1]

7/01/19 12:37 PM f=2.38 /home/phillip/eagle/YAZ180_V24/YAZ180_V24.brd

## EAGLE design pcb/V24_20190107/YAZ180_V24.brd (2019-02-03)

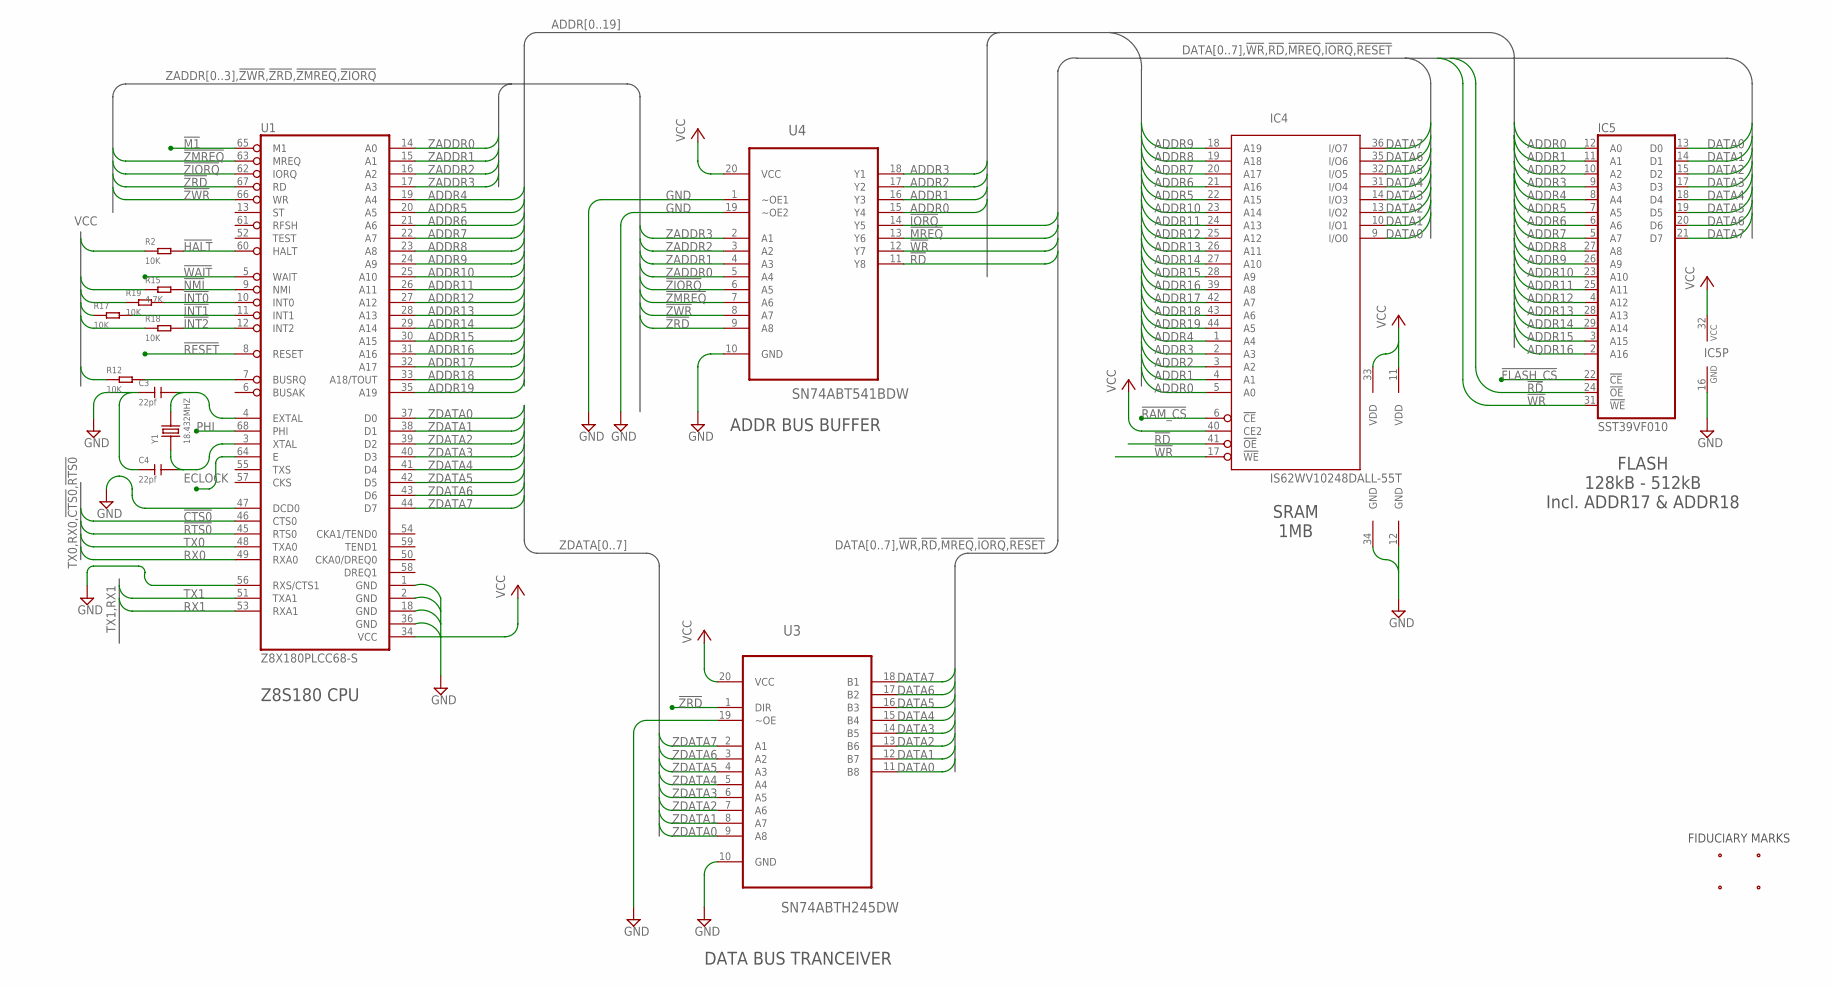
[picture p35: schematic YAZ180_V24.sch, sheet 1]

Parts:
C3, C4: 22pf; C0603
IC4: IS62WV10248DALL-55T; TSOP-II-44
IC5: SST39VF010; S32
R2, R12, R17, R18, R19: 10K; R0603
R15: 4.7K; R0603
U1: Z8X180PLCC68-S; PLCC-S68
U3: SN74ABTH245DW; SOIC127P1030X265-20N
U4: SN74ABT541BDW; SOIC127P1030X265-20N
X3, X4, X5, X6: FIDUCIAL_0.6-1.2MM; FIDUCIAL0.6-1.2
Y1: 18.432MHZ; HC49US

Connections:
!BUSRQ: R12.2, U1.7 (BUSRQ)
!CTS0: U1.46 (CTS0); also elsewhere on the board
!FLASH_CS: IC5.22 (!CE); also elsewhere on the board
!HALT: R2.2, U1.60 (HALT); also elsewhere on the board
!INT0: R19.2, U1.10 (INT0); also elsewhere on the board
!INT1: R17.2, U1.11 (INT1); also elsewhere on the board
!INT2: R18.2, U1.12 (INT2); also elsewhere on the board
!IORQ: U4.14 (Y5); also elsewhere on the board
!M1: U1.65 (M1); also elsewhere on the board
!MREQ: U4.13 (Y6); also elsewhere on the board
!NMI: R15.2, U1.9 (NMI)
!RAM_CS: IC4.6 (!CE); also elsewhere on the board
!RD: IC4.41 (!OE), IC5.24 (!OE), U4.11 (Y8); also elsewhere on the board
!RESET: U1.8 (RESET); also elsewhere on the board
!RTS0: U1.45 (RTS0); also elsewhere on the board
!WAIT: U1.5 (WAIT); also elsewhere on the board
!WR: IC4.17 (!WE), IC5.31 (!WE), U4.12 (Y7); also elsewhere on the board
!ZIORQ: U1.62 (IORQ), U4.6 (A5)
!ZMREQ: U1.63 (MREQ), U4.7 (A6)
!ZRD: U1.67 (RD), U3.1 (DIR), U4.9 (A8)
!ZWR: U1.66 (WR), U4.8 (A7); also elsewhere on the board
ADDR0: IC4.5 (A0), IC5.12 (A0), U4.15 (Y4); also elsewhere on the board
ADDR1: IC4.4 (A1), IC5.11 (A1), U4.16 (Y3); also elsewhere on the board
ADDR2: IC4.3 (A2), IC5.10 (A2), U4.17 (Y2); also elsewhere on the board
ADDR3: IC4.2 (A3), IC5.9 (A3), U4.18 (Y1); also elsewhere on the board
ADDR4: IC4.1 (A4), IC5.8 (A4), U1.19 (A4); also elsewhere on the board
ADDR5: IC4.22 (A15), IC5.7 (A5), U1.20 (A5); also elsewhere on the board
ADDR6: IC4.21 (A16), IC5.6 (A6), U1.21 (A6); also elsewhere on the board
ADDR7: IC4.20 (A17), IC5.5 (A7), U1.22 (A7); also elsewhere on the board
ADDR8: IC4.19 (A18), IC5.27 (A8), U1.23 (A8); also elsewhere on the board
ADDR9: IC4.18 (A19), IC5.26 (A9), U1.24 (A9); also elsewhere on the board
ADDR10: IC4.23 (A14), IC5.23 (A10), U1.25 (A10); also elsewhere on the board
ADDR11: IC4.24 (A13), IC5.25 (A11), U1.26 (A11); also elsewhere on the board
ADDR12: IC4.25 (A12), IC5.4 (A12), U1.27 (A12); also elsewhere on the board
ADDR13: IC4.26 (A11), IC5.28 (A13), U1.28 (A13); also elsewhere on the board
ADDR14: IC4.27 (A10), IC5.29 (A14), U1.29 (A14); also elsewhere on the board
ADDR15: IC4.28 (A9), IC5.3 (A15), U1.30 (A15); also elsewhere on the board
ADDR16: IC4.39 (A8), IC5.2 (A16), U1.31 (A16); also elsewhere on the board
ADDR17: IC4.42 (A7), U1.32 (A17); also elsewhere on the board
ADDR18: IC4.43 (A6), U1.33 (A18/TOUT); also elsewhere on the board
ADDR19: IC4.44 (A5), U1.35 (A19); also elsewhere on the board
DATA0: IC4.9 (I/O0), IC5.13 (D0), U3.11 (B8); also elsewhere on the board
DATA1: IC4.10 (I/O1), IC5.14 (D1), U3.12 (B7); also elsewhere on the board
DATA2: IC4.13 (I/O2), IC5.15 (D2), U3.13 (B6); also elsewhere on the board
DATA3: IC4.14 (I/O3), IC5.17 (D3), U3.14 (B5); also elsewhere on the board
DATA4: IC4.31 (I/O4), IC5.18 (D4), U3.15 (B4); also elsewhere on the board
DATA5: IC4.32 (I/O5), IC5.19 (D5), U3.16 (B3); also elsewhere on the board
DATA6: IC4.35 (I/O6), IC5.20 (D6), U3.17 (B2); also elsewhere on the board
DATA7: IC4.36 (I/O7), IC5.21 (D7), U3.18 (B1); also elsewhere on the board
ECLOCK: U1.64 (E); also elsewhere on the board
EXTAL: C3.2, U1.4 (EXTAL), Y1.2
GND: C3.1, C4.1, IC4.12 (GND), IC4.34 (GND), IC5.16 (GND), U1.1 (GND), U1.2 (GND), U1.18 (GND), U1.36 (GND), U1.47 (DCD0), U1.56 (RXS/CTS1), U3.10 (GND), U3.19 (~OE), U4.1 (~OE1), U4.10 (GND), U4.19 (~OE2); also elsewhere on the board
PHI: U1.68 (PHI); also elsewhere on the board
RX0: U1.49 (RXA0); also elsewhere on the board
RX1: U1.53 (RXA1); also elsewhere on the board
TX0: U1.48 (TXA0); also elsewhere on the board
TX1: U1.51 (TXA1); also elsewhere on the board
VCC: IC4.11 (VDD), IC4.33 (VDD), IC4.40 (CE2), IC5.32 (VCC), R2.1, R12.1, R15.1, R17.1, R18.1, R19.1, U1.34 (VCC), U3.20 (VCC), U4.20 (VCC); also elsewhere on the board
XTAL: C4.2, U1.3 (XTAL), Y1.1
ZADDR0: U1.14 (A0), U4.5 (A4)
ZADDR1: U1.15 (A1), U4.4 (A3)
ZADDR2: U1.16 (A2), U4.3 (A2)
ZADDR3: U1.17 (A3), U4.2 (A1)
ZDATA0: U1.37 (D0), U3.9 (A8)
ZDATA1: U1.38 (D1), U3.8 (A7)
ZDATA2: U1.39 (D2), U3.7 (A6)
ZDATA3: U1.40 (D3), U3.6 (A5)
ZDATA4: U1.41 (D4), U3.5 (A4)
ZDATA5: U1.42 (D5), U3.4 (A3)
ZDATA6: U1.43 (D6), U3.3 (A2)
ZDATA7: U1.44 (D7), U3.2 (A1)

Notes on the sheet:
FIDUCIARY MARKS
Z8S180 CPU
ADDR BUS BUFFER
SRAM 1MB
FLASH 128kB - 512kB Incl. ADDR17 & ADDR18
DATA BUS TRANCEIVER

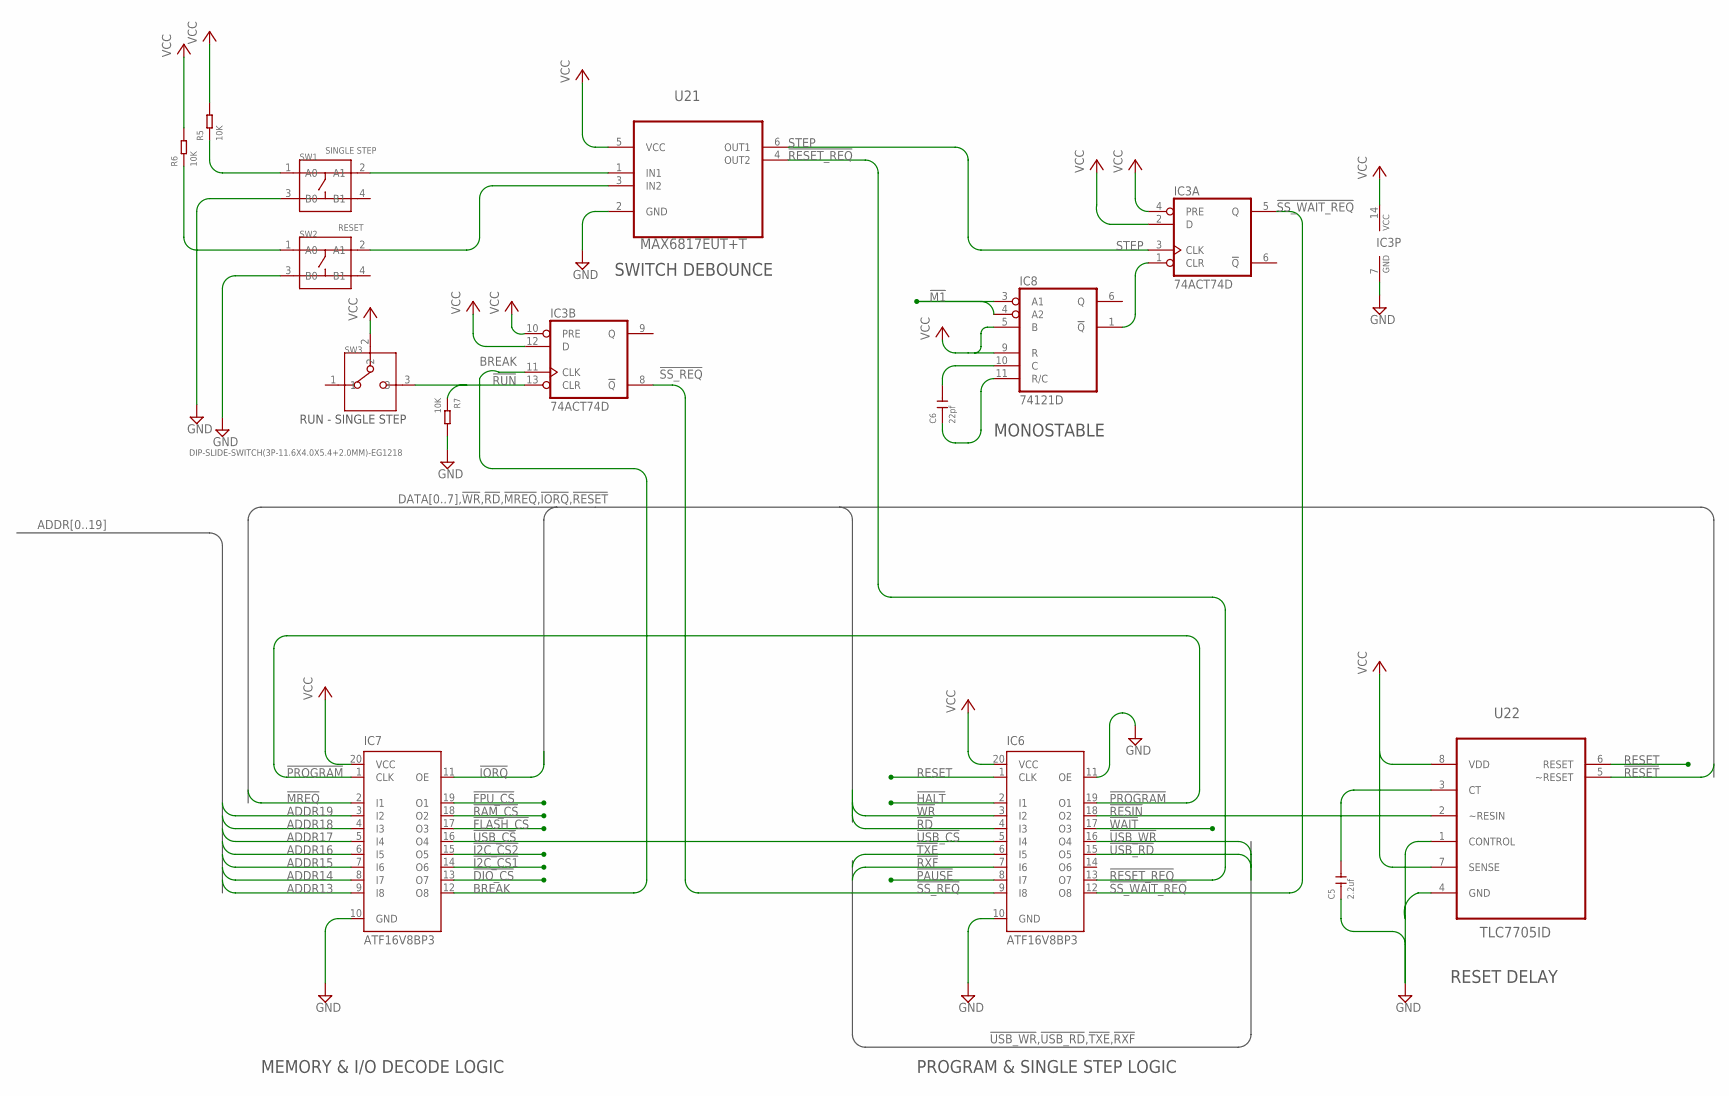
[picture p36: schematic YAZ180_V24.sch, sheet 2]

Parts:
C5: 2.2uf; C0603
C6: 22pf; C0603
IC3: 74ACT74D; SO14
IC6, IC7: ATF16V8BP3; DIL20
IC8: 74121D; SO14
R5, R6, R7: 10K; R0603
SW1: SINGLE STEP; SW4-SMD-4.0X4.0X1.7MM
SW2: RESET; SW4-SMD-4.0X4.0X1.7MM
SW3: DIP-SLIDE-SWITCH(3P-11.6X4.0X5.4+2.0MM)-EG1218; SW3-2.5-11.6X4.0X5.4+2.0MM
U21: MAX6817EUT+T; SOT95P280X145-6N
U22: TLC7705ID; SOIC127P600X175-8N

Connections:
!DIO_CS: IC7.13 (O7); also elsewhere on the board
!FLASH_CS: IC7.17 (O3); also elsewhere on the board
!FPU_CS: IC7.19 (O1); also elsewhere on the board
!HALT: IC6.2 (I1); also elsewhere on the board
!I2C_CS1: IC7.14 (O6); also elsewhere on the board
!I2C_CS2: IC7.15 (O5); also elsewhere on the board
!IORQ: IC7.11 (OE); also elsewhere on the board
!M1: IC8.3 (A1), IC8.4 (A2); also elsewhere on the board
!MREQ: IC7.2 (I1); also elsewhere on the board
!PAUSE: IC6.8 (I7); also elsewhere on the board
!PROGRAM: IC6.19 (O1), IC7.1 (CLK)
!RAM_CS: IC7.18 (O2); also elsewhere on the board
!RD: IC6.4 (I3); also elsewhere on the board
!RESET: U22.5 (~RESET); also elsewhere on the board
!RESET_REQ: IC6.13 (O7), U21.4 (OUT2)
!RESIN: IC6.18 (O2), U22.2 (~RESIN)
!RUN: IC3.13 (CLR), R7.1, SW3.3
!RXF: IC6.7 (I6); also elsewhere on the board
!SS_REQ: IC3.8 (!Q), IC6.9 (I8)
!SS_WAIT_REQ: IC3.5 (Q), IC6.12 (O8)
!TXE: IC6.6 (I5); also elsewhere on the board
!USB_CS: IC6.5 (I4), IC7.16 (O4)
!USB_RD: IC6.15 (O5); also elsewhere on the board
!USB_WR: IC6.16 (O4); also elsewhere on the board
!WAIT: IC6.17 (O3); also elsewhere on the board
!WR: IC6.3 (I2); also elsewhere on the board
ADDR13: IC7.9 (I8); also elsewhere on the board
ADDR14: IC7.8 (I7); also elsewhere on the board
ADDR15: IC7.7 (I6); also elsewhere on the board
ADDR16: IC7.6 (I5); also elsewhere on the board
ADDR17: IC7.5 (I4); also elsewhere on the board
ADDR18: IC7.4 (I3); also elsewhere on the board
ADDR19: IC7.3 (I2); also elsewhere on the board
BREAK: IC3.11 (CLK), IC7.12 (O8)
GND: C5.1, IC3.7 (GND), IC6.10 (GND), IC6.11 (OE), IC7.10 (GND), IC8.7 (GND), R7.2, SW1.3 (B0), SW2.3 (B0), U21.2 (GND), U22.1 (CONTROL), U22.4 (GND); also elsewhere on the board
unnamed: IC3.1 (CLR), IC8.1 (!Q)
unnamed: C5.2, U22.3 (CT)
unnamed: C6.2, IC8.10 (C)
unnamed: SW1.2 (A1), U21.1 (IN1)
unnamed: R5.1, SW1.1 (A0)
unnamed: R6.1, SW2.1 (A0)
unnamed: SW2.2 (A1), U21.3 (IN2)
unnamed: C6.1, IC8.11 (R/C)
RESET: IC6.1 (CLK), U22.6 (RESET); also elsewhere on the board
STEP: IC3.3 (CLK), U21.6 (OUT1)
VCC: IC3.2 (D), IC3.4 (PRE), IC3.10 (PRE), IC3.12 (D), IC3.14 (VCC), IC6.20 (VCC), IC7.20 (VCC), IC8.5 (B), IC8.9 (R), IC8.14 (VCC), R5.2, R6.2, SW3.2, U21.5 (VCC), U22.7 (SENSE), U22.8 (VDD); also elsewhere on the board

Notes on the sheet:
RUN - SINGLE STEP
SWITCH DEBOUNCE
MEMORY & I/O DECODE LOGIC
PROGRAM & SINGLE STEP LOGIC
RESET DELAY
MONOSTABLE

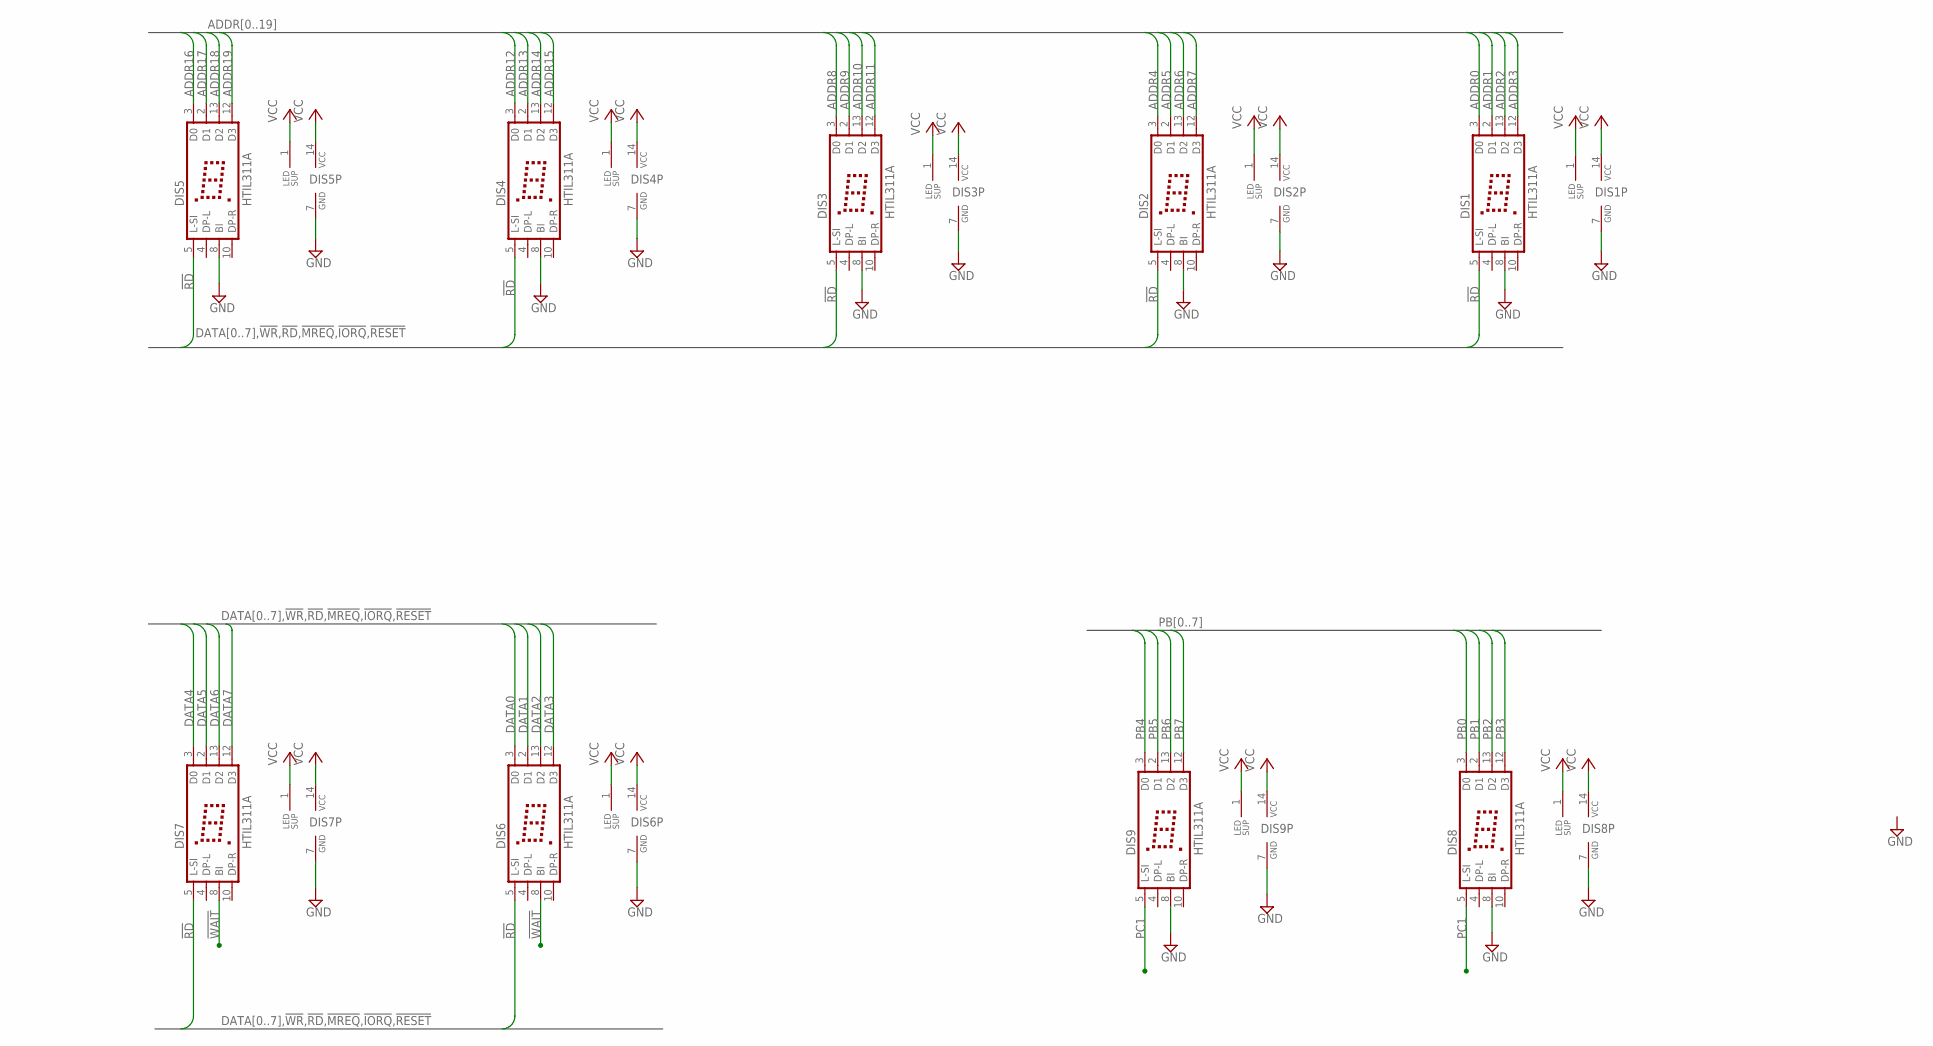
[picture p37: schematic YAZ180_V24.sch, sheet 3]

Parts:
DIS1, DIS2, DIS3, DIS4, DIS5, DIS6, DIS7, DIS8, DIS9: HTIL311A

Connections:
!RD: DIS1.5 (L-SI), DIS2.5 (L-SI), DIS3.5 (L-SI), DIS4.5 (L-SI), DIS5.5 (L-SI), DIS6.5 (L-SI), DIS7.5 (L-SI); also elsewhere on the board
!WAIT: DIS6.8 (BI), DIS7.8 (BI); also elsewhere on the board
ADDR0: DIS1.3 (D0); also elsewhere on the board
ADDR1: DIS1.2 (D1); also elsewhere on the board
ADDR2: DIS1.13 (D2); also elsewhere on the board
ADDR3: DIS1.12 (D3); also elsewhere on the board
ADDR4: DIS2.3 (D0); also elsewhere on the board
ADDR5: DIS2.2 (D1); also elsewhere on the board
ADDR6: DIS2.13 (D2); also elsewhere on the board
ADDR7: DIS2.12 (D3); also elsewhere on the board
ADDR8: DIS3.3 (D0); also elsewhere on the board
ADDR9: DIS3.2 (D1); also elsewhere on the board
ADDR10: DIS3.13 (D2); also elsewhere on the board
ADDR11: DIS3.12 (D3); also elsewhere on the board
ADDR12: DIS4.3 (D0); also elsewhere on the board
ADDR13: DIS4.2 (D1); also elsewhere on the board
ADDR14: DIS4.13 (D2); also elsewhere on the board
ADDR15: DIS4.12 (D3); also elsewhere on the board
ADDR16: DIS5.3 (D0); also elsewhere on the board
ADDR17: DIS5.2 (D1); also elsewhere on the board
ADDR18: DIS5.13 (D2); also elsewhere on the board
ADDR19: DIS5.12 (D3); also elsewhere on the board
DATA0: DIS6.3 (D0); also elsewhere on the board
DATA1: DIS6.2 (D1); also elsewhere on the board
DATA2: DIS6.13 (D2); also elsewhere on the board
DATA3: DIS6.12 (D3); also elsewhere on the board
DATA4: DIS7.3 (D0); also elsewhere on the board
DATA5: DIS7.2 (D1); also elsewhere on the board
DATA6: DIS7.13 (D2); also elsewhere on the board
DATA7: DIS7.12 (D3); also elsewhere on the board
GND: DIS1.7 (GND), DIS1.8 (BI), DIS2.7 (GND), DIS2.8 (BI), DIS3.7 (GND), DIS3.8 (BI), DIS4.7 (GND), DIS4.8 (BI), DIS5.7 (GND), DIS5.8 (BI), DIS6.7 (GND), DIS7.7 (GND), DIS8.7 (GND), DIS8.8 (BI), DIS9.7 (GND), DIS9.8 (BI); also elsewhere on the board
PB0: DIS8.3 (D0); also elsewhere on the board
PB1: DIS8.2 (D1); also elsewhere on the board
PB2: DIS8.13 (D2); also elsewhere on the board
PB3: DIS8.12 (D3); also elsewhere on the board
PB4: DIS9.3 (D0); also elsewhere on the board
PB5: DIS9.2 (D1); also elsewhere on the board
PB6: DIS9.13 (D2); also elsewhere on the board
PB7: DIS9.12 (D3); also elsewhere on the board
PC1: DIS8.5 (L-SI), DIS9.5 (L-SI); also elsewhere on the board
VCC: DIS1.1 (LEDSUP), DIS1.14 (VCC), DIS2.1 (LEDSUP), DIS2.14 (VCC), DIS3.1 (LEDSUP), DIS3.14 (VCC), DIS4.1 (LEDSUP), DIS4.14 (VCC), DIS5.1 (LEDSUP), DIS5.14 (VCC), DIS6.1 (LEDSUP), DIS6.14 (VCC), DIS7.1 (LEDSUP), DIS7.14 (VCC), DIS8.1 (LEDSUP), DIS8.14 (VCC), DIS9.1 (LEDSUP), DIS9.14 (VCC); also elsewhere on the board

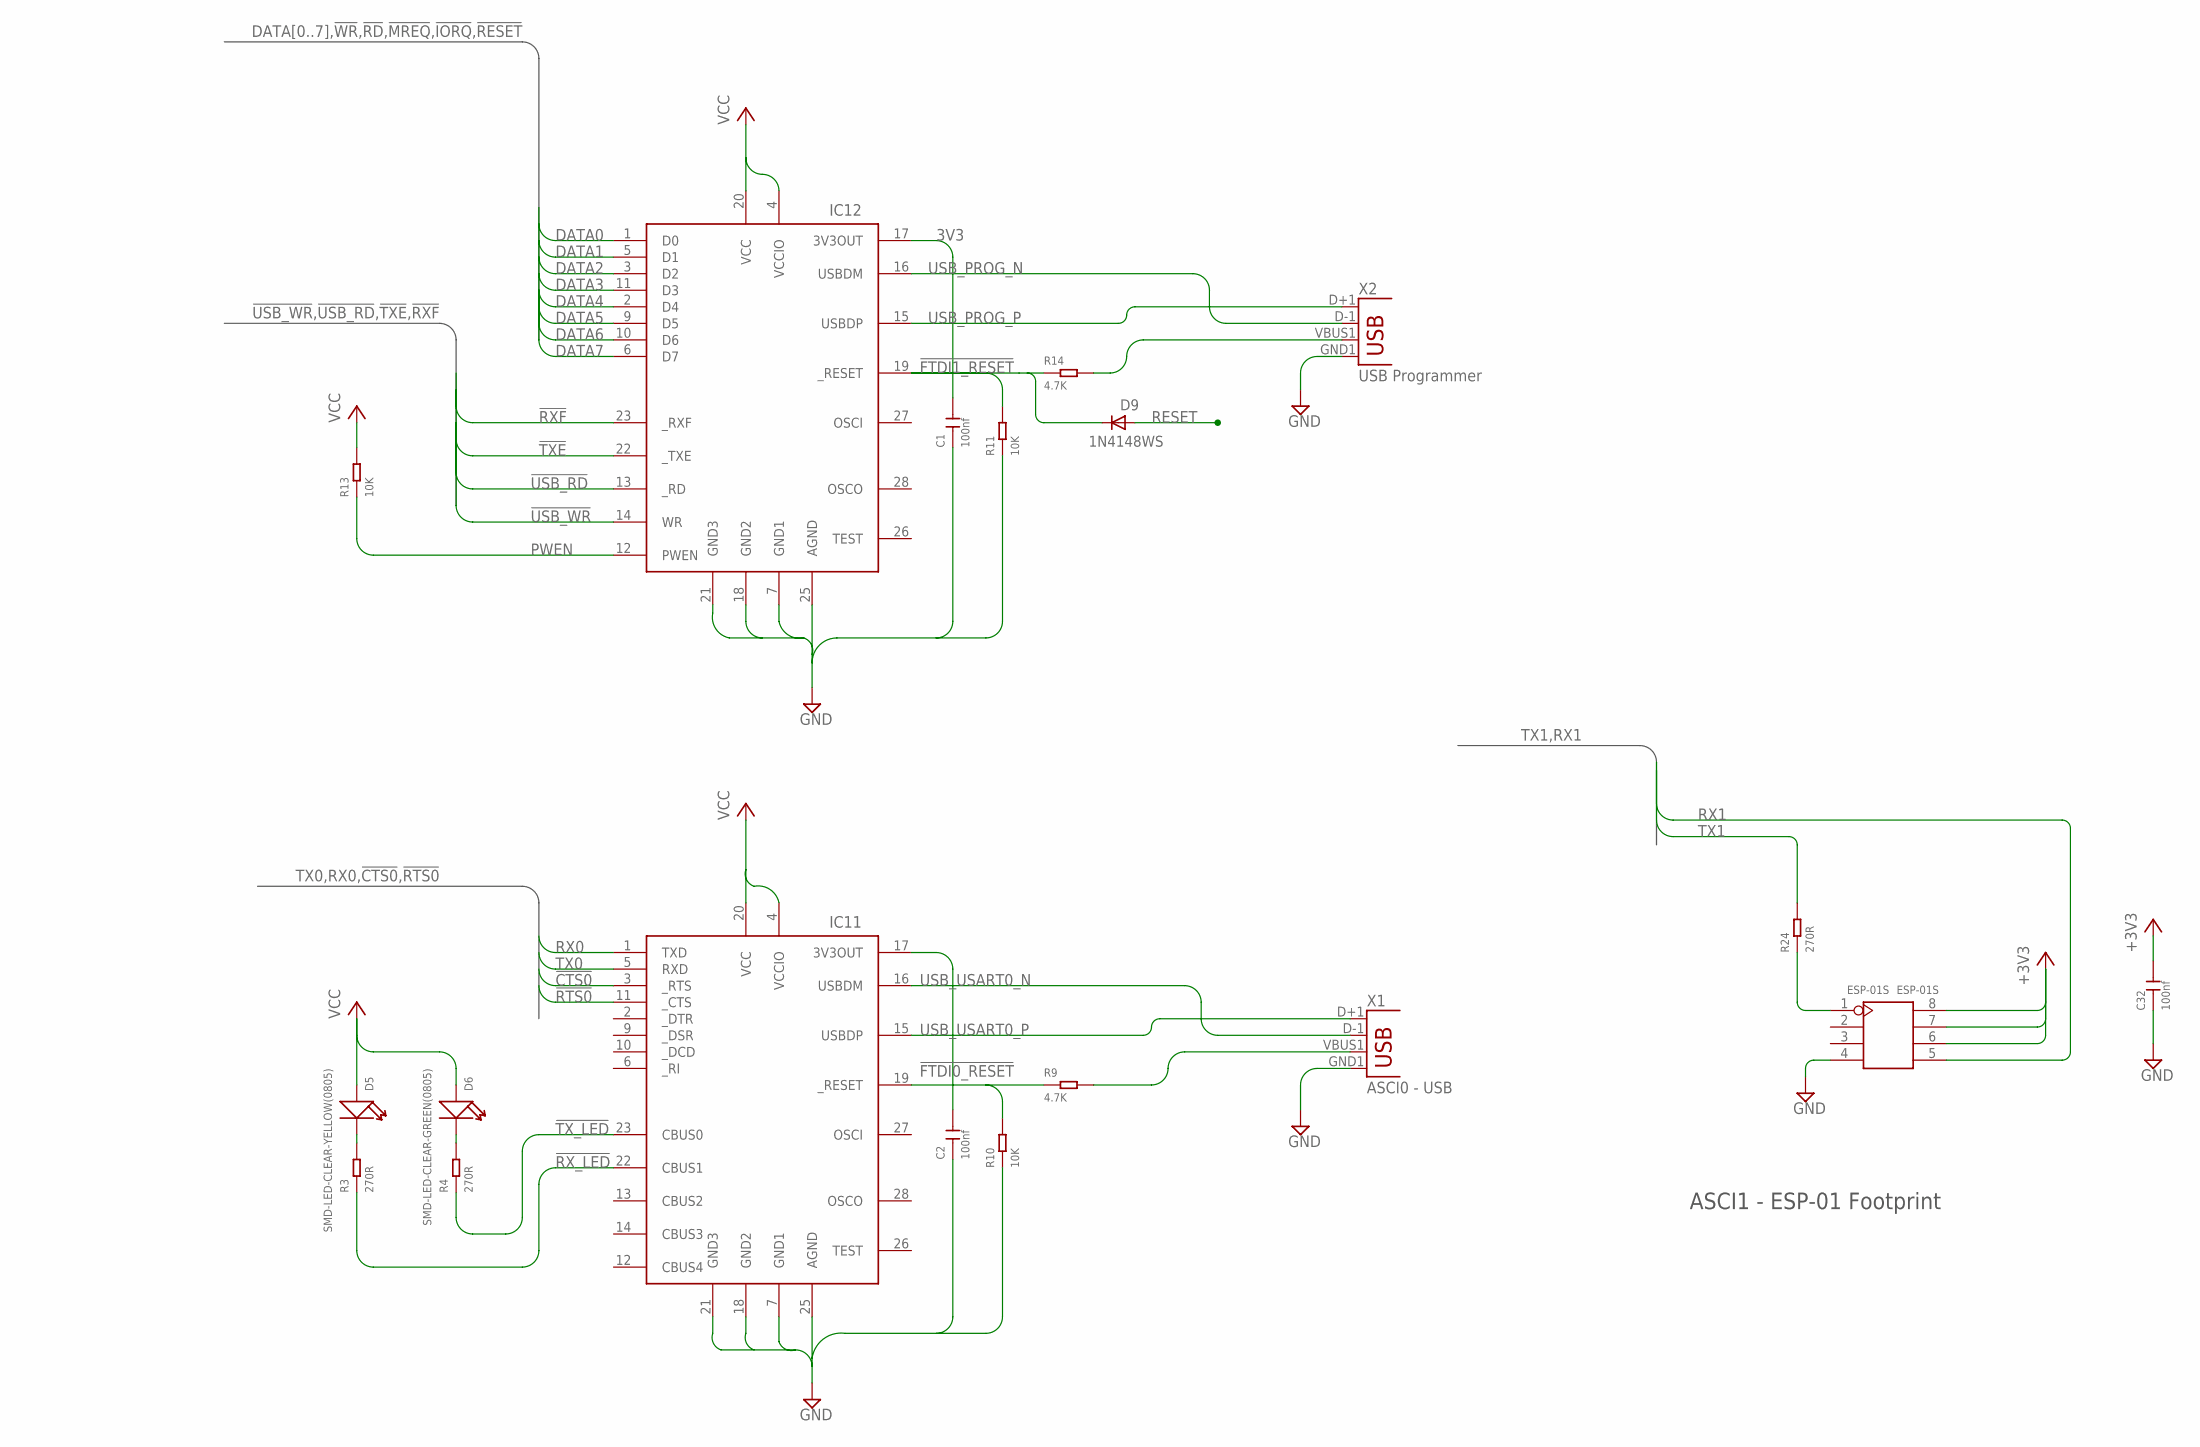
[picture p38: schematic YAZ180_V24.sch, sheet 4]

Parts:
C1, C2, C32: 100nf; C0603
D5: SMD-LED-CLEAR-YELLOW(0805); LED-0805
D6: SMD-LED-CLEAR-GREEN(0805); LED-0805
D9: 1N4148WS; SOD323F
ESP-01S: ESP-01S; H2X4-2.54
IC11: FT232RL; SSOP28DB
IC12: FT245RL; SSOP28DB
R3, R4, R24: 270R; R0603
R9, R14: 4.7K; R0603
R10, R11, R13: 10K; R0603
X1: ASCI0 - USB; USB-A-SMT-MALE
X2: USB Programmer; USB-A-SMT-MALE

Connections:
3V3: C1.2, IC12.17 (3V3OUT)
!CTS0: IC11.3 (_RTS); also elsewhere on the board
!FTDI0_RESET: IC11.19 (_RESET), R9.1, R10.2
!FTDI1_RESET: D9.C, IC12.19 (_RESET), R11.2, R14.1
!RTS0: IC11.11 (_CTS); also elsewhere on the board
!RXF: IC12.23 (_RXF); also elsewhere on the board
!RX_LED: IC11.22 (CBUS1), R3.1
!TXE: IC12.22 (_TXE); also elsewhere on the board
!TX_LED: IC11.23 (CBUS0), R4.1
!USB_RD: IC12.13 (_RD); also elsewhere on the board
!USB_WR: IC12.14 (WR); also elsewhere on the board
+3V3: C32.2, ESP-01S.6, ESP-01S.7, ESP-01S.8; also elsewhere on the board
DATA0: IC12.1 (D0); also elsewhere on the board
DATA1: IC12.5 (D1); also elsewhere on the board
DATA2: IC12.3 (D2); also elsewhere on the board
DATA3: IC12.11 (D3); also elsewhere on the board
DATA4: IC12.2 (D4); also elsewhere on the board
DATA5: IC12.9 (D5); also elsewhere on the board
DATA6: IC12.10 (D6); also elsewhere on the board
DATA7: IC12.6 (D7); also elsewhere on the board
GND: C1.1, C2.1, C32.1, ESP-01S.4, IC11.7 (GND1), IC11.18 (GND2), IC11.21 (GND3), IC11.25 (AGND), IC12.7 (GND1), IC12.18 (GND2), IC12.21 (GND3), IC12.25 (AGND), R10.1, R11.1, X1.GND1 (GND), X2.GND1 (GND); also elsewhere on the board
unnamed: R14.2, X2.VBUS1 (VBUS)
unnamed: R9.2, X1.VBUS1 (VBUS)
unnamed: ESP-01S.1, R24.1
unnamed: C2.2, IC11.17 (3V3OUT)
unnamed: D5.-, R3.2
unnamed: D6.-, R4.2
PWEN: IC12.12 (PWEN), R13.1
RESET: D9.A; also elsewhere on the board
RX0: IC11.1 (TXD); also elsewhere on the board
RX1: ESP-01S.5; also elsewhere on the board
TX0: IC11.5 (RXD); also elsewhere on the board
TX1: R24.2; also elsewhere on the board
USB_PROG_N: IC12.16 (USBDM), X2.D-1 (D-)
USB_PROG_P: IC12.15 (USBDP), X2.D+1 (D+)
USB_USART0_N: IC11.16 (USBDM), X1.D-1 (D-)
USB_USART0_P: IC11.15 (USBDP), X1.D+1 (D+)
VCC: D5.+, D6.+, IC11.4 (VCCIO), IC11.20 (VCC), IC12.4 (VCCIO), IC12.20 (VCC), R13.2; also elsewhere on the board

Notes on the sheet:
ASCI1 - ESP-01 Footprint

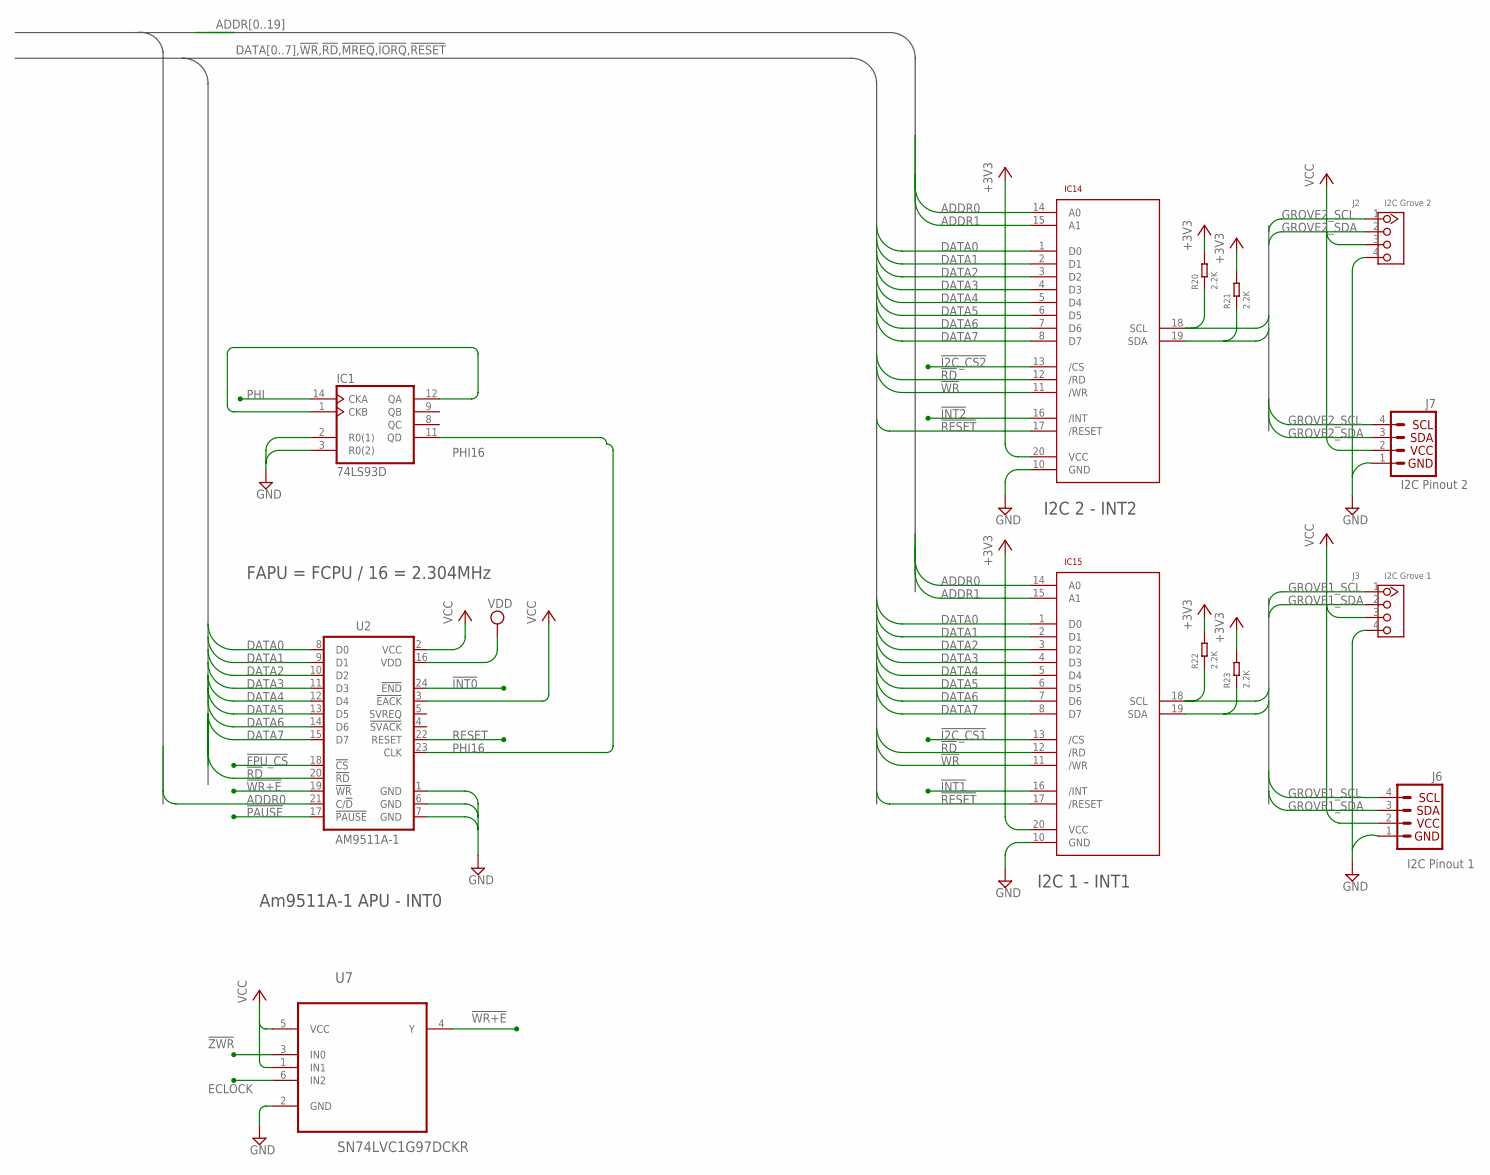
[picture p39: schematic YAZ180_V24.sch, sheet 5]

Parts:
IC1: 74LS93D; SO14
IC14, IC15: PCA9665; TSSOP20
J2: I2C Grove 2; HW4-2.0-90D
J3: I2C Grove 1; HW4-2.0-90D
J6: I2C Pinout 1; 1X04
J7: I2C Pinout 2; 1X04
R20, R21, R22, R23: 2.2K; R0603
U2: AM9511A-1; DIL24-6
U7: SN74LVC1G97DCKR; SOT65P210X110-6N

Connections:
!FPU_CS: U2.18 (!CS); also elsewhere on the board
!I2C_CS1: IC15.13 (/CS); also elsewhere on the board
!I2C_CS2: IC14.13 (/CS); also elsewhere on the board
!INT0: U2.24 (!END); also elsewhere on the board
!INT1: IC15.16 (/INT); also elsewhere on the board
!INT2: IC14.16 (/INT); also elsewhere on the board
!PAUSE: U2.17 (!PAUSE); also elsewhere on the board
!RD: IC14.12 (/RD), IC15.12 (/RD), U2.20 (!RD); also elsewhere on the board
!RESET: IC14.17 (/RESET), IC15.17 (/RESET); also elsewhere on the board
!WR: IC14.11 (/WR), IC15.11 (/WR); also elsewhere on the board
!WR+E: U2.19 (!WR), U7.4 (Y)
!ZWR: U7.3 (IN0); also elsewhere on the board
+3V3: IC14.20 (VCC), IC15.20 (VCC), R20.2, R21.2, R22.2, R23.2; also elsewhere on the board
ADDR0: IC14.14 (A0), IC15.14 (A0), U2.21 (C/!D); also elsewhere on the board
ADDR1: IC14.15 (A1), IC15.15 (A1); also elsewhere on the board
DATA0: IC14.1 (D0), IC15.1 (D0), U2.8 (D0); also elsewhere on the board
DATA1: IC14.2 (D1), IC15.2 (D1), U2.9 (D1); also elsewhere on the board
DATA2: IC14.3 (D2), IC15.3 (D2), U2.10 (D2); also elsewhere on the board
DATA3: IC14.4 (D3), IC15.4 (D3), U2.11 (D3); also elsewhere on the board
DATA4: IC14.5 (D4), IC15.5 (D4), U2.12 (D4); also elsewhere on the board
DATA5: IC14.6 (D5), IC15.6 (D5), U2.13 (D5); also elsewhere on the board
DATA6: IC14.7 (D6), IC15.7 (D6), U2.14 (D6); also elsewhere on the board
DATA7: IC14.8 (D7), IC15.8 (D7), U2.15 (D7); also elsewhere on the board
ECLOCK: U7.6 (IN2); also elsewhere on the board
GND: IC1.2 (R0(1)), IC1.3 (R0(2)), IC1.10 (GND), IC14.10 (GND), IC15.10 (GND), J2.4, J3.4, J6.1, J7.1, U2.1 (GND), U2.6 (GND), U2.7 (GND), U7.2 (GND); also elsewhere on the board
GROVE1_SCL: IC15.18 (SCL), J3.1, J6.4, R22.1
GROVE1_SDA: IC15.19 (SDA), J3.2, J6.3, R23.1
GROVE2_SCL: IC14.18 (SCL), J2.1, J7.4, R20.1
GROVE2_SDA: IC14.19 (SDA), J2.2, J7.3, R21.1
unnamed: IC1.1 (CKB), IC1.12 (QA)
PHI: IC1.14 (CKA); also elsewhere on the board
PHI16: IC1.11 (QD), U2.23 (CLK)
RESET: U2.22 (RESET); also elsewhere on the board
VCC: IC1.5 (VCC), J2.3, J3.3, J6.2, J7.2, U2.2 (VCC), U2.3 (!EACK), U7.1 (IN1), U7.5 (VCC); also elsewhere on the board
VDD: U2.16 (VDD); also elsewhere on the board

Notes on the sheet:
Am9511A-1 APU - INT0
I2C 2 - INT2
I2C 1 - INT1
FAPU = FCPU / 16 = 2.304MHz

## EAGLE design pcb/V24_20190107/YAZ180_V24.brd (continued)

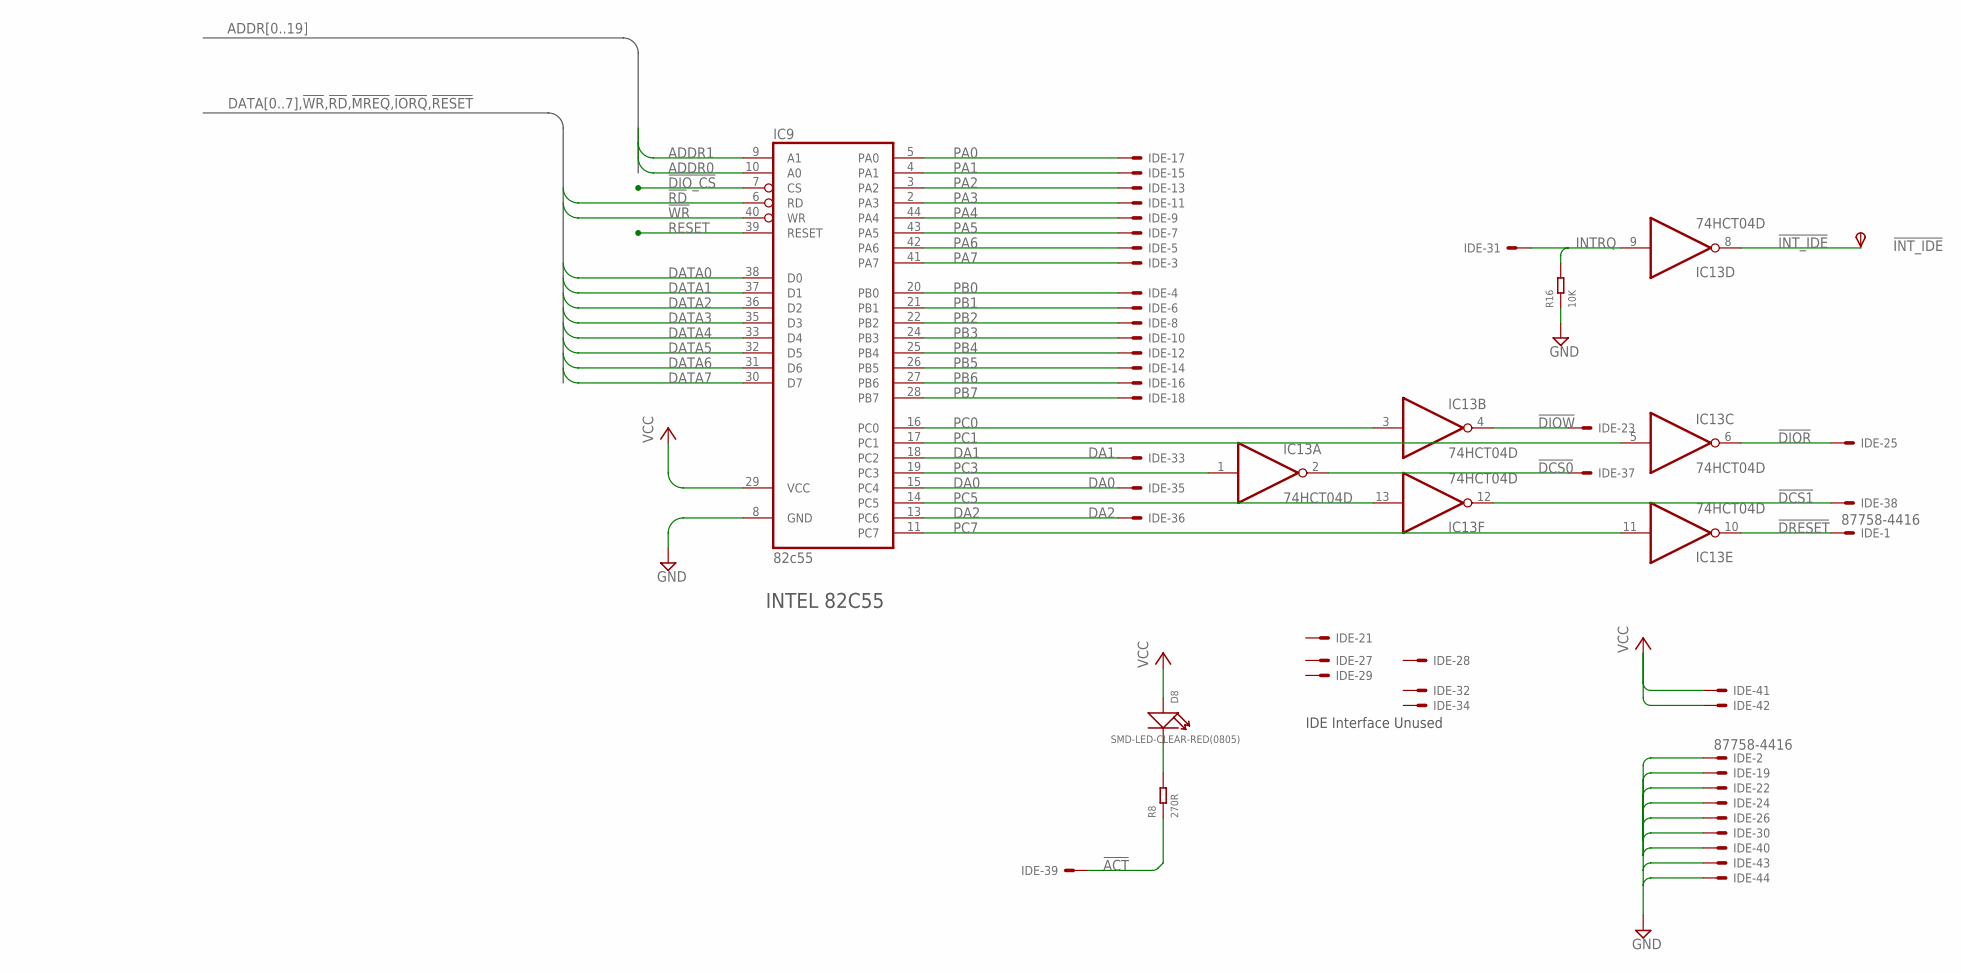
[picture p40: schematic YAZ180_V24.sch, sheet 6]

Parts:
!INT_IDE: TPSPAD1-13; P1-13
D8: SMD-LED-CLEAR-RED(0805); LED-0805
IC9: 82c55; S44
IC13: 74HCT04D; SO14
IDE: 87758-4416
R8: 270R; R0603
R16: 10K; R0603

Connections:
!ACT: IDE.39, R8.1
!DCS0: IC13.2 (O), IDE.37
!DCS1: IC13.12 (O), IDE.38
!DIOR: IC13.6 (O), IDE.25
!DIOW: IC13.4 (O), IDE.23
!DIO_CS: IC9.7 (CS); also elsewhere on the board
!DRESET: IC13.10 (O), IDE.1
!INT_IDE: !INT_IDE.TP, IC13.8 (O)
!RD: IC9.6 (RD); also elsewhere on the board
!WR: IC9.40 (WR); also elsewhere on the board
ADDR0: IC9.10 (A0); also elsewhere on the board
ADDR1: IC9.9 (A1); also elsewhere on the board
DA0: IC9.15 (PC4), IDE.35
DA1: IC9.18 (PC2), IDE.33
DA2: IC9.13 (PC6), IDE.36
DATA0: IC9.38 (D0); also elsewhere on the board
DATA1: IC9.37 (D1); also elsewhere on the board
DATA2: IC9.36 (D2); also elsewhere on the board
DATA3: IC9.35 (D3); also elsewhere on the board
DATA4: IC9.33 (D4); also elsewhere on the board
DATA5: IC9.32 (D5); also elsewhere on the board
DATA6: IC9.31 (D6); also elsewhere on the board
DATA7: IC9.30 (D7); also elsewhere on the board
GND: IC9.8 (GND), IC13.7 (GND), IDE.2, IDE.19, IDE.22, IDE.24, IDE.26, IDE.30, IDE.40, IDE.43, IDE.44, R16.1; also elsewhere on the board
INTRQ: IC13.9 (I), IDE.31, R16.2
unnamed: D8.-, R8.2
PA0: IC9.5 (PA0), IDE.17
PA1: IC9.4 (PA1), IDE.15
PA2: IC9.3 (PA2), IDE.13
PA3: IC9.2 (PA3), IDE.11
PA4: IC9.44 (PA4), IDE.9
PA5: IC9.43 (PA5), IDE.7
PA6: IC9.42 (PA6), IDE.5
PA7: IC9.41 (PA7), IDE.3
PB0: IC9.20 (PB0), IDE.4; also elsewhere on the board
PB1: IC9.21 (PB1), IDE.6; also elsewhere on the board
PB2: IC9.22 (PB2), IDE.8; also elsewhere on the board
PB3: IC9.24 (PB3), IDE.10; also elsewhere on the board
PB4: IC9.25 (PB4), IDE.12; also elsewhere on the board
PB5: IC9.26 (PB5), IDE.14; also elsewhere on the board
PB6: IC9.27 (PB6), IDE.16; also elsewhere on the board
PB7: IC9.28 (PB7), IDE.18; also elsewhere on the board
PC0: IC9.16 (PC0), IC13.3 (I)
PC1: IC9.17 (PC1), IC13.5 (I); also elsewhere on the board
PC3: IC9.19 (PC3), IC13.1 (I)
PC5: IC9.14 (PC5), IC13.13 (I)
PC7: IC9.11 (PC7), IC13.11 (I)
RESET: IC9.39 (RESET); also elsewhere on the board
VCC: D8.+, IC9.29 (VCC), IC13.14 (VCC), IDE.41, IDE.42; also elsewhere on the board

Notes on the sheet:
INTEL 82C55
IDE Interface Unused

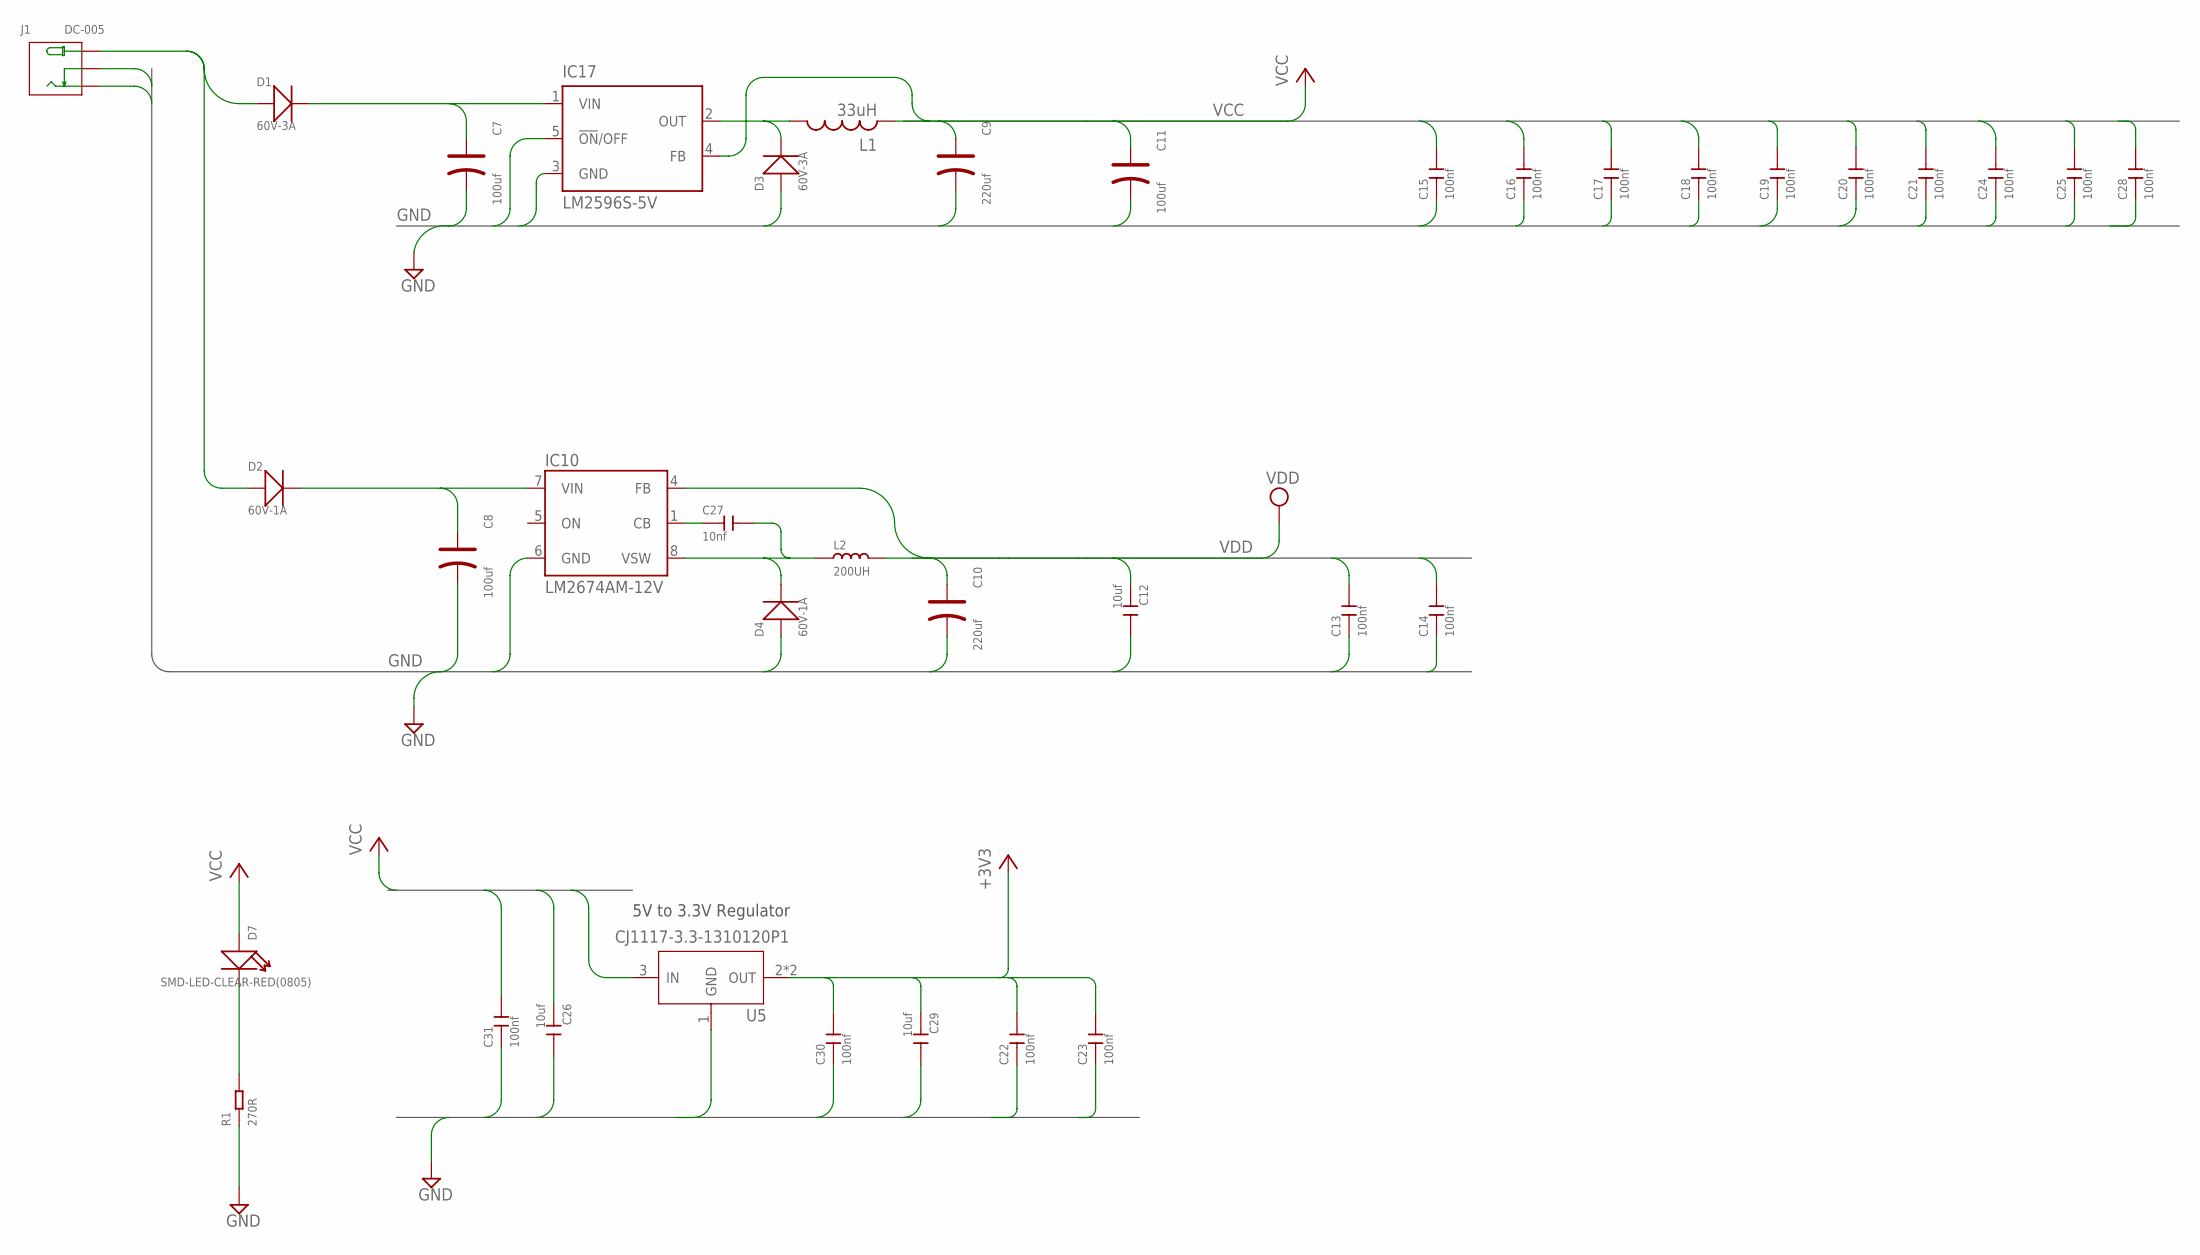
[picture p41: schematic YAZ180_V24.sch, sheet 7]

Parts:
C7, C8: 100uf; ELECTRO-SMD-E-7.8MM
C9, C10: 220uf; AVX-E
C11: 100uf; AVX-C
C12, C26, C29: 10uf; C0805
C13, C14, C15, C16, C17, C18, C19, C20, C21, C22, C23, C24, C25, C28, C30, C31: 100nf; C0603
C27: 10nf; C0603
D1, D3: 60V-3A; SOD-323
D2, D4: 60V-1A; SOD-323
D7: SMD-LED-CLEAR-RED(0805); LED-0805
IC10: LM2674AM-12V; SO08
IC17: LM2596S-5V; TO263-5
J1: DC-005; DCJ3P-14.2X11.0X9.0MM
L1: 33uH; MSS1260
L2: 200UH; SMD-2P-5.0X5.0X2.0MM
R1: 270R; R0603
U5: CJ1117-3.3-1310120P1; SOT89

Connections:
+3V3: C22.2, C23.2, C29.1, C30.2, U5.2 (OUT), U5.4 (OUT); also elsewhere on the board
GND: C7.-, C8.-, C9.-, C10.-, C11.-, C12.2, C13.1, C14.1, C15.1, C16.1, C17.1, C18.1, C19.1, C20.1, C21.1, C22.1, C23.1, C24.1, C25.1, C26.2, C28.1, C29.2, C30.1, C31.1, D3.+, D4.+, IC10.6 (GND), IC17.3 (GND), IC17.5 (!ON!/OFF), J1.-1 (-), J1.-2 (CDN), R1.1, U5.1 (GND); also elsewhere on the board
unnamed: C27.1, IC10.1 (CB)
unnamed: D1.+, D2.+, J1.+
unnamed: D7.-, R1.2
unnamed: C7.+, D1.-, IC17.1 (VIN)
unnamed: C8.+, D2.-, IC10.7 (VIN)
unnamed: D3.-, IC17.2 (OUT), L1.P$1
unnamed: C27.2, D4.-, IC10.8 (VSW), L2.1
VCC: C9.+, C11.+, C15.2, C16.2, C17.2, C18.2, C19.2, C20.2, C21.2, C24.2, C25.2, C26.1, C28.2, C31.2, D7.+, IC17.4 (FB), L1.P$2, U5.3 (IN); also elsewhere on the board
VDD: C10.+, C12.1, C13.2, C14.2, IC10.4 (FB), L2.2; also elsewhere on the board

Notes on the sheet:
5V to 3.3V Regulator

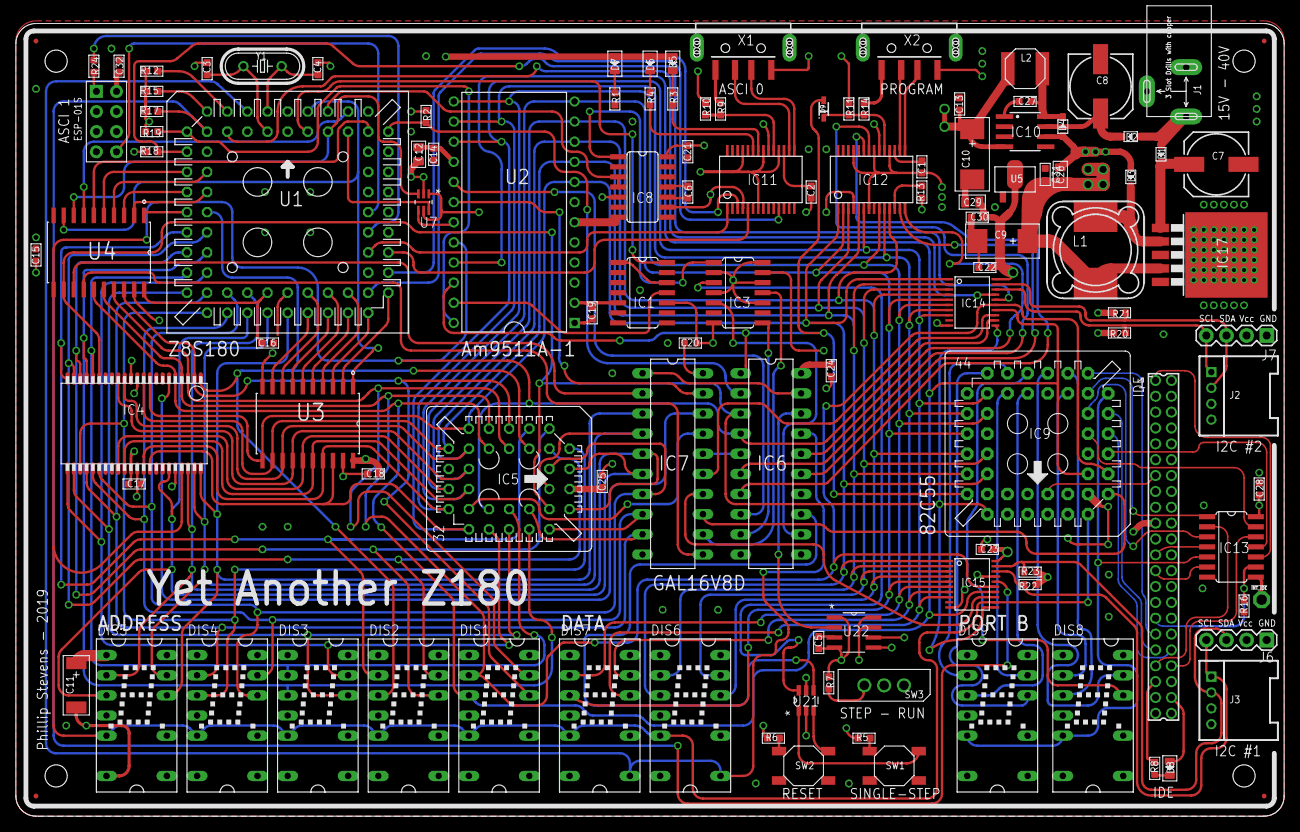
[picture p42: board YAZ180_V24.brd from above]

Board: 4 copper layers, 160.0 x 100.0 mm, 117 parts (0 on the bottom side), 163 nets.

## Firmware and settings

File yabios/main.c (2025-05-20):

/***************************************************************************//**

  @file         main.c
  @author       Phillip Stevens, inspired by Stephen Brennan
  @brief        YASH (Yet Another SHell)

  This programme reached working state on Melbourne Cup Day, 2017.

*******************************************************************************/

#include <stdlib.h>
#include <stdio.h>
#include <string.h>
#include <sys/compiler.h>

#include <arch.h>
#include <arch/yaz180.h>

#include <time.h>
#include <sys/time.h>
#include <lib/yaz180/time.h>

#include "ffconf.h"
#include <lib/yaz180/ff.h>

#include <arch/yaz180/diskio.h>

// PRAGMA DEFINES
#pragma output REGISTER_SP             = 0xFFDE // __BIOS_SP
#pragma output CRT_ENABLE_RST          = 0x00FE
#pragma output CRT_ENABLE_TRAP         = 1

#pragma output CLIB_MALLOC_HEAP_SIZE   = 9984   // 0x2700 measured maximum free

// DEFINES

#define MAX_FILES 2             // number of files open at any time

#define BUFFER_SIZE 1024        // size of working buffer (on heap)
#define LINE_SIZE 256           // size of a command line (on heap)
#define TOK_BUFSIZE 64          // size of token pointer buffer (on heap)

#define TOK_DELIM " \t\r\n\a"

#define PAGE0_SIZE 0x0100       // size of a Page0 copy buffer (on heap)

// GLOBALS

static uint32_t driveLBAbase[4];/* Base of CPM drive files */

static void * buffer;           /* create a scratch buffer on heap later */

static FATFS * fs;              /* Pointer to the filesystem object (on heap) */
                                /* FatFs work area needed for each volume */

static FIL File[MAX_FILES];     /* File object needed for each open file */

static FILE * input;            /* defined input */
static FILE * output;           /* defined output */
static FILE * error;            /* defined output */

static uint8_t directoryBlock[32] = {0xE5,0x20,0x20,0x20,0x20,0x20,0x20,0x20,0x20,0x20,0x20,0x20, \
                                            0,0,0,0,0,0,0,0,0,0,0,0,0,0,0,0,0,0,0,0};

/*
  Function Declarations for built-in shell commands:
 */

// CP/M related functions
int8_t ya_mkcpmb(char ** args); // initialise CP/M bank with up to 4 drives
int8_t ya_mkcpmd(char ** args); // create a FATFS file for CP/M drive

// bank related functions
int8_t ya_mkb(char ** args);    // initialise the nominated bank (to warm state)
int8_t ya_cpb(char ** args);    // copy or clone the nominated bank
int8_t ya_rmb(char ** args);    // remove the nominated bank (to cold state)
int8_t ya_initb(char ** args);  // jump to and begin executing the nominated bank at nominated address
int8_t ya_loadh(char ** args);  // load the nominated bank with intel hex from asci0/1
int8_t ya_loadb(char ** args);  // load the nominated bank and address with binary code
int8_t ya_saveb(char ** args);  // save the nominated bank from 0x0100 to 0xF000 by default

// system related functions
int8_t ya_md(char ** args);     // memory dump
int8_t ya_help(char ** args);   // help
int8_t ya_exit(char ** args);   // exit and restart

// fat related functions
int8_t ya_frag(char ** args);   // check file for fragmentation
int8_t ya_ls(char ** args);     // directory listing
int8_t ya_rm(char ** args);     // delete a file
int8_t ya_cp(char ** args);     // copy a file
int8_t ya_mv(char ** args);     // move (rename) a file
int8_t ya_cd(char ** args);     // change the current working directory
int8_t ya_pwd(char ** args);    // show the current working directory
int8_t ya_mkdir(char ** args);  // create a new directory
int8_t ya_chmod(char ** args);  // change file or directory attributes
int8_t ya_mount(char ** args);  // mount a FAT file system

// disk related functions
int8_t ya_ds(char ** args);     // disk status
int8_t ya_dd(char ** args);     // disk dump sector

// time related functions
int8_t ya_clock(char ** args);  // set the time (UNIX epoch)
int8_t ya_tz(char ** args);     // set timezone (no daylight savings, so adjust manually)
int8_t ya_diso(char ** args);   // print the local time in ISO: 2013-03-23 01:03:52
int8_t ya_date(char ** args);   // print the local time in US: Sun Mar 23 01:03:52 2013

// helper functions
uint8_t ya_num_builtins(void);  // 
static void put_rc (FRESULT rc);    // print error codes to defined error IO
static void put_dump (const uint8_t * buff, uint16_t ofs, uint8_t cnt);

// EXTERNAL FUNCTIONS

#if __SCCZ80

extern void exit_far(void) __smallc;

extern uint8_t asci0_flush_Rx(void) __smallc;   // Rx0 flush routine
extern uint8_t asci0_pollc(void) __smallc;      // Rx0 polling routine, checks Rx0 buffer fullness
extern uint8_t asci0_getc(void) __smallc;       // Rx0 receive routine, from Rx0 buffer
extern uint8_t asci1_flush_Rx(void) __smallc;   // Rx1 flush routine
extern uint8_t asci1_pollc(void) __smallc;      // Rx1 polling routine, checks Rx1 buffer fullness
extern uint8_t asci1_getc(void) __smallc;       // Rx1 receive routine, from Rx1 buffer

#elif __SDCC

extern void exit_far(void) __preserves_regs(b,c,d,e,h,l,iyl,iyh);

extern uint8_t asci0_flush_Rx(void) __preserves_regs(b,c,d,e,iyl,iyh);  // Rx0 flush routine
extern uint8_t asci0_pollc(void) __preserves_regs(b,c,d,e,iyl,iyh);     // Rx0 polling routine, checks Rx0 buffer fullness
extern uint8_t asci0_getc(void) __preserves_regs(b,c,d,e,iyl,iyh);      // Rx0 receive routine, from Rx0 buffer
extern uint8_t asci1_flush_Rx(void) __preserves_regs(b,c,d,e,iyl,iyh);  // Rx1 flush routine
extern uint8_t asci1_pollc(void) __preserves_regs(b,c,d,e,iyl,iyh);     // Rx1 polling routine, checks Rx1 buffer fullness
extern uint8_t asci1_getc(void) __preserves_regs(b,c,d,e,iyl,iyh);      // Rx1 receive routine, from Rx1 buffer

#endif

/*
  List of builtin commands.
 */

struct Builtin {
  const char * name;
  int8_t (*func) (char ** args);
  const char * help;
};

struct Builtin builtins[] = {
  // CP/M related functions
    { "mkcpmb", &ya_mkcpmb, "[src][dest][file][][][] - initialise dest bank for CP/M from src bank, up to 4 drive files"},
    { "mkcpmd", &ya_mkcpmd, "[file][dir][bytes] - create a drive file for CP/M, with dir entries, of bytes size"},

  // bank related functions
    { "mkb", &ya_mkb, "[bank] - initialise the nominated bank (to warm state)"},
    { "cpb", &ya_cpb, "[src][dest] - copy or clone the nominated bank"},
    { "rmb", &ya_rmb, "[bank] - remove the nominated bank (to cold state)"},
    { "initb", &ya_initb, "[bank][origin] - begin executing the nominated bank at nominated address"},
    { "loadh", &ya_loadh, "[bank] - load the nominated bank with intel hex"},
    { "loadb", &ya_loadb, "[path][bank][origin] - load the nominated bank from origin with binary code"},
    { "saveb", &ya_saveb, "[bank][path] - save the nominated bank from 0x0100 to 0xF000"},

// fat related functions
    { "frag", &ya_frag, "[file] - check for file fragmentation"},
    { "ls", &ya_ls, "[path] - directory listing"},
    { "rm", &ya_rm, "[file] - delete a file"},
    { "cp", &ya_cp, "[src][dest] - copy a file"},
    { "mv", &ya_mv, "[src][dest] - move (rename) a file"},
    { "cd", &ya_cd, "[path] - change the current working directory"},
    { "pwd", &ya_pwd, "- show the current working directory"},
    { "mount", &ya_mount, "[option] - mount a FAT file system"},
    { "mkdir", &ya_mkdir, "[path] - create a new directory"},
    { "chmod", &ya_chmod, "[path][attr][mask] - change file or directory attributes"},

// disk related functions
    { "ds", &ya_ds, "- disk status"},
    { "dd", &ya_dd, "[sector] - disk dump, sector in decimal"},

// time related functions
    { "clock", &ya_clock, "[timestamp] - set the time (UNIX epoch) 'date +%s'"},
    { "tz", &ya_tz, "[tz] - set timezone (no daylight saving)"},
    { "diso", &ya_diso, "- local time ISO format: 2013-03-23 01:03:52"},
    { "date", &ya_date, "- local time: Sun Mar 23 01:03:52 2013" },

// system related functions
    { "md", &ya_md, "[bank][origin] - memory dump, origin in hexadecimal"},
    { "help", &ya_help, "- this is it"},
    { "exit", &ya_exit, "- exit and restart"}
};

uint8_t ya_num_builtins(void) {
  return sizeof(builtins) / sizeof(struct Builtin);
}


/*
  Builtin function implementations.
*/


/**
   @brief Builtin command:
   @param args List of args.  args[0] is "mkcpmb".  args[1] is the source bank.  args[2] is the CP/M destination bank.
                              args[3][4][5][6] are names of drive files.
   @return Always returns 1, to continue executing.
 */
int8_t ya_mkcpmb(char ** args)  /* initialise CP/M bank with up to 4 drives */
{
    FRESULT res;
    uint8_t * page0Template;
    uint8_t srcBank;
    uint8_t destBank;
    uint8_t i = 0;

    if (args[1] == NULL || args[2] == NULL || args[3] == NULL) {
        fprintf(output, "yash: expected 3 arguments to \"mkcpmb\"\n");
    } else {
        page0Template = (uint8_t *)malloc(sizeof(uint8_t)*PAGE0_SIZE);  /* Get work area for the Page 0 */

        if (page0Template != NULL && args[1] != NULL && args[2] != NULL)
        {
            srcBank = bank_get_abs((int8_t)atoi(args[1]));
            destBank = bank_get_abs((int8_t)atoi(args[2]));

            memcpy( page0Template, (uint8_t *)0x0000, PAGE0_SIZE ); // copy the existing ROM Page0 to our working space
            // existing RST0 trap code is contained in this space at 0x0080, and jumps to __Start at 0x0100.

            // set the new bank SP to point to top of BANKnn for _jp_far(), _bank_sp = 0x003B
            *(volatile uint16_t*)(page0Template + (uint16_t)&bank_sp) = __COMMON_AREA_1_BASE;

            // set up (up to 4) CPM drive LBA locations, before copying to Page 0 template
            while(args[i+3] != NULL)
            {
                fprintf(output,"Opening \"%s\"", args[i+3]);
                res = f_open(&File[0], (const TCHAR *)args[i+3], FA_OPEN_EXISTING | FA_READ);
                if (res != FR_OK) { put_rc(res); return 1; }
                driveLBAbase[i] = (&File[0])->obj.fs->database + ((&File[0])->obj.fs->csize * ((&File[0])->obj.sclust - 2));
                fprintf(output," at LBA %lu\n", driveLBAbase[i]);
                f_close(&File[0]);
                ++i;                // go to next file
            }

            // copy up to 4x LBA base addresses into the Page 0 template YABIOS scratch at 0x0040
            memcpy( (volatile uint8_t*)(page0Template + 0x0040), (const uint8_t*)driveLBAbase, sizeof(uint32_t)*4 );

            // copy the source bank for CP/M CCP/BDOS/BIOS for CP/M BIOS wboot usage to Page 0 at 0x0050
            *(volatile uint8_t*)(page0Template + 0x0050) = srcBank;

            // copy over source bank CP/M CCP/BDOS/BIOS to dest bank, if it exists args[1] != 0
            if ( srcBank != 0x00)
            {
                // do the copy from CP/M CCP/BDOS/BIOS src to final destination bank
                memcpy_far( (void *)0x0100, (int8_t)destBank, (void *)0x0100, (int8_t)srcBank, (__COMMON_AREA_1_BASE - PAGE0_SIZE) );
                // do the Page 0 copy from template to final destination bank Page 0
                memcpy_far( (void *)0x0000, (int8_t)destBank, page0Template, 0, PAGE0_SIZE );
                // do the Page 0 initialisation from CP/M CCP/BDOS/BIOS src to final destination bank
                memcpy_far( (void *)0x0000, (int8_t)destBank, (void *)0x0000, (int8_t)srcBank, 0x08 );
                // do the cpm_iobyte initialisation from the bios_ioByte as this is volatile
                memcpy_far( (void *)0x0003, (int8_t)destBank, &bios_ioByte, 0, 0x01 );
            } else {
                // we'll have to load CP/M using loadh later
                // do the Page 0 copy from template to final destination bank Page 0
                memcpy_far( (void *)0x0000, (int8_t)destBank, page0Template, 0, PAGE0_SIZE );
                // do the cpm_iobyte initialisation from the bios_ioByte as this is volatile
                memcpy_far( (void *)0x0003, (int8_t)destBank, &bios_ioByte, 0, 0x01 );
            }

            // set bank referenced from _bankLockBase, so the the bank is noted as warm.
            lock_give( &bankLockBase[ destBank ] );

            fprintf(output,"Initialised Bank: %01X, for CP/M", destBank);
            free(page0Template);
        }
    }
    return 1;
}


/**
   @brief Builtin command:
   @param args List of args.  args[0] is "mkcpmd".  args[1] is the nominated drive name.
                              args[2] is the number of directory entries,  args[3] is file size in bytes.
   @return Always returns 1, to continue executing.
 */
int8_t ya_mkcpmd(char ** args)  /* create a file for CP/M drive */
{
    FRESULT res;
    int16_t dirEntries;
    int16_t dirBytesWritten;
    uint32_t lbaBase;

    if (args[1] == NULL || args[2] == NULL || args[3] == NULL) {
        fprintf(output, "yash: expected 3 arguments to \"mkcpmd\"\n");
    } else {
        fprintf(output,"Creating \"%s\"", args[1]);
        res = f_open(&File[0], (const TCHAR*)args[1], FA_CREATE_ALWAYS | FA_WRITE);
        if (res != FR_OK) { put_rc(res); return 1; }

        res = f_expand(&File[0], atol(args[3]), 1);
        if (res != FR_OK) {
            put_rc(res);
            f_close(&File[0]);
            return 1;
        }

        dirEntries = atoi(args[2]);

        for (uint16_t i = 0; i < dirEntries; i++) {

            // There are 4 Directory Entries (Extents) per CPM sector
            res = f_write ( &File[0], (const uint8_t *)directoryBlock, 32, &dirBytesWritten );
            if (res != FR_OK || dirBytesWritten != 32) {
                fprintf(output, "\nCP/M Directory incomplete");
                put_rc(res);
                f_close(&File[0]);
                return 1;
            }
        }

        lbaBase = (&File[0])->obj.fs->database + ((&File[0])->obj.fs->csize * ((&File[0])->obj.sclust - 2));
        f_close(&File[0]);

        fprintf(output," at base sector LBA %lu", lbaBase);
    }
    return 1;
}


/*
 bank related functions
 */


/**
   @brief Builtin command:
   @param args List of args.  args[0] is "mkb".  args[1] is the nominated bank.
   @return Always returns 1, to continue executing.
 */
int8_t ya_mkb(char ** args)     /* initialise the nominated bank (to warm state) */
{
    uint8_t * page0Template;

    page0Template = (uint8_t *)malloc(sizeof(uint8_t)*PAGE0_SIZE);  /* Get work area for the Page 0 */

    if (page0Template != NULL && args[1] != NULL)
    {
        memcpy(page0Template, (uint8_t *)0x0000, PAGE0_SIZE); // copy the existing ROM Page0 to our working space
        // existing RST0 trap code is contained in this space at 0x0080, and jumps to __Start at 0x0100.
        // existing RST jumps and INT0 code is correctly copied.
        *(volatile uint16_t*)(page0Template + (uint16_t)&bank_sp) = __COMMON_AREA_1_BASE; // set the new bank SP to point to top of BANKnn
        // do the copy
        memcpy_far((void *)0x0000, (int8_t)atoi(args[1]), page0Template, 0, PAGE0_SIZE);
        // set bank referenced from _bankLockBase, so the the bank is noted as warm.
        lock_give( &bankLockBase[ bank_get_abs((int8_t)atoi(args[1])) ] );
        fprintf(output,"Initialised Bank: %01X", bank_get_abs((int8_t)atoi(args[1])) );
        free(page0Template);
    }
    return 1;
}


/**
   @brief Builtin command:
   @param args List of args.  args[0] is "cpb".  args[1] is source bank. args[2] is the destination bank.
   @return Always returns 1, to continue executing.
 */
int8_t ya_cpb(char ** args)     /* move or clone the nominated bank */
{
    if ( (args[2] != NULL) && (bank_get_abs((int8_t)atoi(args[1])) != 0) && (bank_get_abs((int8_t)atoi(args[2])) != 0) )   // the source and destination can never be BANK0
    {
        // do the copy
        memcpy_far((void *)0x0000, (int8_t)atoi(args[2]), (void *)0x0000, (int8_t)atoi(args[1]), (__COMMON_AREA_1_BASE-0)); // copy it all
        // set bank referenced from _bankLockBase, so the clone bank is noted as the same state as its parent.
        bankLockBase[ bank_get_abs((int8_t)atoi(args[2])) ] = bankLockBase[ bank_get_abs((int8_t)atoi(args[1])) ];
        fprintf(output,"Cloned Bank: %01X into Bank: %01X", bank_get_abs((int8_t)atoi(args[1])), bank_get_abs((int8_t)atoi(args[2])));
    }
    return 1;
}


/**
   @brief Builtin command:
   @param args List of args.  args[0] is "rmb".  args[1] is the nominated bank.
   @return Always returns 1, to continue executing.
 */
int8_t ya_rmb(char ** args)     /* remove the nominated bank (to cold state) */
{
    if (args[1] == NULL) {
        fprintf(output, "yash: expected 1 argument to \"rmb\"\n");
    } else {
        // set bank referenced from _bankLockBase, so the the bank is noted as cold.
        bankLockBase[ bank_get_abs((int8_t)atoi(args[1])) ] = 0x00;
        fprintf(output,"Deleted Bank: %01X", bank_get_abs((int8_t)atoi(args[1])) );
    }
   return 1;
}


/**
   @brief Builtin command:
   @param args List of args.  args[0] is "initb".  args[1] is the nominated bank. args[2] is the nominated origin.
   @return only returns when the jumped to bank exits.
 */
int8_t ya_initb(char ** args)   /* jump to and begin executing the nominated bank at nominated address */
{
    uint8_t * origin;
    uint8_t bank;

    if (args[1] == NULL) {
        fprintf(output, "yash: expected 2 arguments to \"initb\"\n");
    } else {
        if (args[2] == NULL) {
            origin = (uint8_t *)0x100;
        } else {
            origin = (uint8_t *)strtoul(args[2], NULL, 16);
        }
        bank = (int8_t)atoi(args[1]);
        jp_far(origin, bank);   // manages the stack swap from _bios_sp to _bank_sp
    }
    return 1;
}


/**
   @brief Builtin command:
   @param args List of args.  args[0] is "loadh".  args[1] is the nominated initial bank.
   @return Always returns 1, to continue executing.
 */
int8_t ya_loadh(char ** args)   /* load the nominated bank with intel hex using current port */
{
    uint8_t initialBank;

    if (args[1] == NULL) {
        fprintf(output, "yash: expected 1 argument to \"loadh\"\n");
    } else {
        initialBank = bank_get_abs((int8_t)atoi(args[1]));
        load_hex( initialBank );
        // set bank referenced from _bankLockBase, so the the bank is noted as warm.
        lock_give( &bankLockBase[ initialBank ] );
        fprintf(output,"Loaded Bank: %01X", initialBank );
    }
    return 1;
}


/**
   @brief Builtin command:
   @param args List of args.  args[0] is "loadb".  args[1] is the path.
        args[2] is the nominated bank. args[3] is the origin address.
   @return Always returns 1, to continue executing.
 */
int8_t ya_loadb(char ** args)   /* load the nominated bank and address with binary code */
{
    FRESULT res;
    uint8_t * dest;
    uint32_t p1;
    uint16_t s1;

    struct timespec startTime, endTime, resTime;

    if (args[1] == NULL || args[2] == NULL) {
        fprintf(output, "yash: expected 3 arguments to \"loadb\"\n");
    } else {
        if (args[3] == NULL) {
            dest = (uint8_t *)0x0100;
        } else {
            dest = (uint8_t *)strtoul(args[3], NULL, 16);
        }
        fprintf(output,"Opening \"%s\"\n", args[1]);
        res = f_open(&File[0], (const TCHAR *)args[1], FA_OPEN_EXISTING | FA_READ);
        if (res != FR_OK) { put_rc(res); return 1; }

        fprintf(output,"Loading \"%s\" to %01X:%04X...", args[1], bank_get_abs((int8_t)atoi(args[2])), (uint16_t)dest );

        clock_gettime( CLOCK_MONOTONIC, &startTime );

        p1 = 0;
        while ((uint16_t)dest < (__COMMON_AREA_1_BASE-0)) {
            res = f_read(&File[0], buffer, sizeof(char)*BUFFER_SIZE, &s1);
            if (res != FR_OK || s1 == 0) break;   /* error or eof */

            if (s1 > (__COMMON_AREA_1_BASE-0) - (uint16_t)dest) {       // don't overwrite COMMON AREA 1
                s1 = (__COMMON_AREA_1_BASE-0) - (uint16_t)dest;
            }
            memcpy_far((void *)dest, (int8_t)atoi(args[2]), buffer, 0, s1);     // write s1 bytes to ram
            dest += s1;
            p1 += s1;
        }

        clock_gettime( CLOCK_MONOTONIC, &endTime );

        f_close(&File[0]);

        // set bank referenced from _bankLockBase, so the the bank is noted as warm.
        lock_give( &bankLockBase[ bank_get_abs((int8_t)atoi(args[2])) ] );

        timersub(&endTime, &startTime, &resTime);

        fprintf(output, "\nLoaded %lu bytes, the time taken was %li.%.4lu seconds", p1, resTime.tv_sec, resTime.tv_nsec/100000);
    }
    return 1;
}
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
int main(int argc, char ** argv)
{
    (void)argc;
    (void *)argv;

    FRESULT res;

    set_zone((int32_t)10 * ONE_HOUR);               /* Australian Eastern Standard Time */
    set_system_time(1747663200 - UNIX_OFFSET);      /* Initial time: 00.00 May 20, 2025 UTC */

    fs = (FATFS *)malloc(sizeof(FATFS));                    /* Get work area for the volume */
    buffer = (char *)malloc(BUFFER_SIZE * sizeof(char));    /* Get working buffer space */

    fprintf(stdout, "\n\nYAZ180 - yabios - CRT\n\n> :?");
    fprintf(ttyout, "\n\nYAZ180 - yabios - TTY\n\n> :?");

    // Run command loop if we got all the memory allocations we need.
    if (fs && buffer) {
        if(res = f_mount(fs, (const TCHAR*)"0:", 0) != 0) put_rc(res);
        ya_loop();
    }

    // Perform any shutdown/cleanup.
    free(buffer);
    free(fs);

    return 0;
}

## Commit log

2017-10-13 initial structure + documents
    [YAZ180_V21.GBL, YAZ180_V21.GBO, YAZ180_V21.GBP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]
2017-10-31 Excel Version of BOM
    Includes stock in hand on 1 Nov 2017
    [YAZ180_V21_BOM.xlsx]
2017-10-31 Digikey Shopping Cart
    Final V2.1 shopping cart at Digikey.
    In case the Internet forgets.
    [2017-10-30T22_14_47.csv]
2018-01-31 fix mkcpmb and CP/M wboot SP
    [main.c]
2018-02-23 Added PCB Version 2.2
    [YAZ180_V21.GBL, YAZ180_V21.GBO, YAZ180_V21.GBP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]
2018-02-23 Removed old V2.1 directory
    [YAZ180_V21.GBL, YAZ180_V21.GBO, YAZ180_V21.GBP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]
2018-02-28 revised z88dk terminal drivers
2018-03-11 PCBv2.1 Errata
2018-03-28 Error if f_opendir() fails
    [main.c]
2018-05-10 v2.2 PCB image
2018-05-18 yabios - ChaN FATFS Version 13b & CA1 Drivers 0xF580
2018-06-03 yabios - bank aware apu driver
2018-06-05 yabios - fix APU device driver
2018-09-29 MP/M - mpmldr adjust assembly glue
2018-11-20 YAZ180 - V2.3 for 2019 release
    [YAZ180_V23.GBL, YAZ180_V23.GBO, YAZ180_V23.GBP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]
2018-11-22 YAZ180 PCB V23 - Re-Gerbered for Seeed
    [YAZ180_V23_BOM_PARTS.csv, YAZ180_V23_BOM_VALUES.csv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]
2018-11-23 YAZ180 PCB V23 - Re-Gerbered again for Seeed
    [YAZ180_V23.GBL, YAZ180_V23.GBO, YAZ180_V23.GBP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]
2018-12-08 revert to ZSDCC r9958
    [main.c]
2018-12-12 docs - update BOM for V2.3
    [YAZ180_V23_ListByValues.csv]
2019-01-07 PCB - V2.4 minor polishing
    [YAZ180_V24.GBL, YAZ180_V24.GBO, YAZ180_V24.GBP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]
2019-01-09 PCB - V2.4 documents
    [YAZ180_V23_BOM_PARTS.csv, YAZ180_V23_BOM_VALUES.csv, YAZ180_V24_PARTS.csv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]
2019-01-12 yabios - fix ya_pwd & ya_chmod
    [main.c]
2019-02-01 CUPL - PCBv2.4 & SST39SF020A 256kB
2019-02-03 PCB - delete names from silk
    [YAZ180_V24.brd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]
2019-08-09 pcb - check and re-order
    [YAZ180_V24.GBL, YAZ180_V24.GBP, YAZ180_V24.GBS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]
2019-08-11 yabios - defc interrupt locations
2019-10-26 readme - add I2C video link
2019-10-26 readme - add I2C video thumbnail
2019-10-26 readme - add I2C video remark
2019-11-02 yabios - minor fixes
    [main.c]
2020-04-30 cpm - 256 Sectors per Track
2021-06-04 yabios - asci0 RTS flow control
2021-06-05 yabios - optimise RTS flow control
2021-06-05 introduce end-of-line normalisation
    [2017-10-30T22_14_47.csv]
2022-08-27 yabios - fix ls
    [main.c]

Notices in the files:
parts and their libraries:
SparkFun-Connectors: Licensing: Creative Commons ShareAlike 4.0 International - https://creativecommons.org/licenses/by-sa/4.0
